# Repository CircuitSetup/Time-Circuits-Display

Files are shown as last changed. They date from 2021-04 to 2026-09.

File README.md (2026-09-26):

# Time Circuits Display

| TCD Front |

This [repository](https://github.com/CircuitSetup/Time-Circuits-Display) holds the most current firmware for CircuitSetup's wonderful [Time Circuits Display](https://circuitsetup.us/product/complete-time-circuits-display-kit/) ("TCD") kit, a reproduction of an iconic part of the Delorean Time Machine.

The kit is available [here](https://circuitsetup.us/product/complete-time-circuits-display-kit/). The metal version is very popular among Delorean owners who convert their vehicle into a Time Machine. A testament to its build quality and accuracy is further the fact that it is used in the **movie-based, official musicals on tour** (2024-2026), and that a sample is part of the experience in the **"OUTATIME" [Escape Room](https://www.universalorlando.com/web/en/us/things-to-do/entertainment/universals-great-movie-escape) in Orlando, Florida**. Namedropping aside, this TCD makes an excellent centerpiece of every movie props collection. It can be used stand-alone or in combination with several [peripherals](#peripherals), both in car and home setups.

[View the instructions for assembling your CircuitSetup TCD Kit](https://github.com/CircuitSetup/Time-Circuits-Display/wiki)

And don't be fooled by the looks, it got brains, too!

| Watch the video (https://youtu.be/1HX0PiZ1YL0) |
|:--:|
| Click to watch the video |

| Watch the video (https://youtu.be/u9oTVXUIOXA) |
|:--:|
| Click to watch the video |

Features include

- Clock-related:
  - Time keeping for years 1-9999, accurately based on Julian and Gregorian [calendars](#calendar-system)
  - Support for time zones and automatic DST (Daylight Saving adjustment)
  - Time synchronization through Internet ([NTP&#10548;](https://en.wikipedia.org/wiki/Network_Time_Protocol)) or [GPS](#gps-receiver)
  - [World Clock mode](#world-clock-mode): Show current time in different time zones on *destination time* and/or *last time departed* displays
  - [Alarm function](#alarm): Daily alarms, with weekday selection as well as snooze and auto-snooze functions
  - [Count-down timer](#count-down-timer): Count down from up to 99 minutes
  - [Yearly/monthly reminder](#yearlymonthly-reminder): Get a yearly or monthly acoustic reminder
  - [Sound on the hour](#additional-custom-sounds)
  - Time can be [spoken out loud](#martys-time-announcement) by "Marty McFly"
- Movie-related:
  - Movie-accurate [Beep](#beep-on-the-second) sound every second (4 modes)
  - Movie-accurate [time travel](#time-travel) function
  - Configuration options to emulate nearly all variations of the TCD shown in the trilogy
  - ["Return from Time Travel"](#time-travel): Return to real present time easily
  - ["Time-cycling"](#time-cycling): Movie-accurate time travel times displayed in *destination time* and *last time departed* displays, and cycled in configurable interval
  - [Exhibition mode](#exhibition-mode): Show a fixed time in *Present Time* display instead of a running clock. Helpful for filming or museums.
- Network capabilities:
  - Advanced network-accessible [Config Portal](#the-config-portal) for setup (http://timecircuits.local)
  - [Wireless communication](#connecting-props-wirelessly-bttf-network-bttfn) with compatible props such as CircuitSetup's [Flux Capacitor](https://circuitsetup.us/product/flux-capacitor-light-sound-kit/) and [SID](https://circuitsetup.us/product/delorean-time-machine-status-indicator-display-sid/), as well as the [Dash Gauges](https://circuitsetup.us/product/delorean-time-machine-dash-gauge-control-board/), [VSR](https://vsr.out-a-ti.me) and modified [Futaba Remote Control](https://circuitsetup.us/product/futaba-remote-stanley-display-wireless-control-kit/), for synchronized Time Travel sequences, replaying movie scenes, mutual remote control, and more. No need for even more wires in your Delorean.
  - [Home Assistant](#home-assistant--mqtt) (MQTT) support for sending and displaying messages, remote controlling and more.
  - Easy [firmware updates](#firmware-installation--firmware-update) over-the-air. No need to send in stuff for firmware updates, it's the 2020s after all.
- [Night mode](#night-mode): Dim or switch off displays on schedule, manually or sensor-controlled. So you won't be blinded during night drives.
- Support for [SD cards](#sd-card) up to 32GB
- Audio output through [line-out](#audio-output) for time travel sound, music and [user-added](#additional-custom-sounds) sound. Connect your TCD to your (car) stereo for high-quality stereo-sound. No more "time traveling" through a 2" speaker. (Requires Control Board 1.4.5 or later)
- [Music player](#the-music-player): Play your mp3 files located on SD card, through your (car) stereo if available. 
- [Keypad-controlled menu](#the-keypad-menu) for adjusting various settings and viewing status through the three displays
- Support for numerous [peripherals](#peripherals):
  - [Fake "power switch"](#fake-power-switch) (eg. a [TFC drive switch](https://tfc.out-a-ti.me))
  - [Speedometer](#speedometer) (eg. CircuitSetup's [speedo](https://circuitsetup.us/product/delorean-time-machine-speedometer-kit) with built-in GPS receiver)
  - [GPS receiver](#gps-receiver) for time synchronization and actual [speed](#gps-for-speed) to be displayed on speedo
  - [Rotary encoders](#rotary-encoder) for manual selection of speed to be displayed on speedo, and/or audio volume
  - External [Time Travel trigger](#external-time-travel-trigger), with optional delay
  - [Temperature/humidity sensor](#room-condition-mode-temperaturehumidity-sensor) for [Room Condition mode](#room-condition-mode-temperaturehumidity-sensor) [display temperature and humidity in *destination time* and *last time departed* displays] and for displaying temperature on speedo while idle
  - Multi-purpose output for signaling/controlling other props [connected by wire](#connecting-props-by-wire) (for example flux lights, third party props)
- &#128007; &#129370; &#129370; &#129370; &#129370; &#129370; &#129370; &#129370; &#129370; &#129370; &#129370; &#129370; &#129370;

>[This repository](https://tcd.out-a%2dti.me) is the upstream source for CircuitSetup's releases. The differences are that both code and documentation [here](https://tcd.out%2da-ti.me) might be ahead in development, and in the sound-packs.

For information on updating the firmware of your TCD, see [here](#firmware-installation--firmware-update).

## Initial Configuration

The first step is to establish access to the TCD's configuration website ("Config Portal") in order to configure your TCD:

- Power up the TCD and wait until it shows a time (which is probably wrong).
- Connect your computer or handheld device to the WiFi network "TCD-AP".
- Navigate your browser to http://timecircuits.local or http://192.168.4.1 to enter the Config Portal.

#### Time zone and Time

The next step is to set the TCD's time zone. If the time zone isn't properly configured, the TCD will show a wrong time and DST (daylight saving) will not be switched on/off correctly.

Click on "Settings" on the Config Portal's main page, and specify your [time zone](#-time-zone). Then click "SAVE"; the TCD will reboot.

Setting actual time:
- If the TCD is going to be connected to a WiFi network with internet access as described below, it will receive time information through NTP (network time protocol). No user interaction is required.
- Otherwise please set your local time through the [keypad menu](#how-to-set-the-real-time-clock-rtc).

#### Sound-pack re-installation (Firmware 3.23 an onwards)

If your factory-fresh TCD came with firmware version 3.23 or later, but no SD card, and you have an SD card at hand, the next step is to re-install the sound-pack. The reason for this is that the sound-pack does not entirely fit into the device's flash memory and parts of it need to be installed on your SD card. Please see [here](#sound-pack-installation) for instructions.

#### WiFi Setup

The TCD knows two ways of WiFi operation: Either it creates its own WiFi network or it connects to a pre-existing WiFi network.

As long as the device is unconfigured, it creates a WiFi network of its own named "TCD-AP". This is called **"Access point mode"** or **"AP-mode"**. In this mode, other WiFi devices - such as other props or a computer - can connect to the TCD, but the TCD can't access the internet (and therefore not synchronize time through NTP). Also, [HA/MQTT](#home-assistant--mqtt) is not possible.

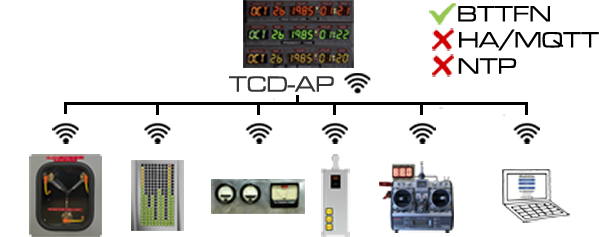
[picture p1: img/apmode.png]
APmode


It is ok to leave the TCD in this mode if there is no WiFi network available.

<details>
<summary>More...</summary>

>Please do not leave computers/handhelds permanently connected to the TCD's AP. These devices might think they are connected to the internet and therefore hammer the TCD with DNS and HTTP requests which might lead to packet loss and disruptions.

>If you want your device to remain in AP-mode, please choose a suitable WiFi channel on the Config Portal's "WiFi Configuration" page. See [here](#-wifi-channel).

</details>

In a typical **home setup**, however, you might want to connect the TCD to your local WiFi network. This allows for for time synchronization (NTP) and [HA/MQTT](#home-assistant--mqtt):

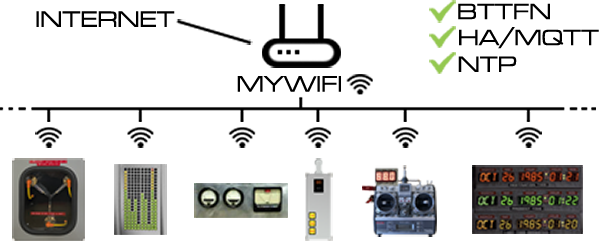
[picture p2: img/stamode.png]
STAmode


To connect your TCD to your WiFi network, navigate to the Config Portal and click on "WiFi Configuration". The bare minimum is to select an WiFi network name (SSID) and a WiFi password.

<details>
<summary>More...</summary>
  
>If there are several APs with identical SSID nearby, the TCD will connect to the first one found which might not be the nearest/strongest. It is therefore recommended to select a specific AP by its BSSID (AP's MAC address). You can either manually find out your AP's BSSID and enter it or have it filled out automatically: Click "Scan for networks", then "Show all". If you click on an AP, its BSSID will be copied into BSSID field in the form below. To see which AP is which, hover over the name to see its BSSID as a tooltip.

>The TCD requests an IP address via DHCP, unless you entered valid data in the fields for static IP addresses (IP, gateway, netmask, DNS). If the device is inaccessible as a result of incorrect static IPs, hold ```ENTER``` while powering it up until the white LED lights up; static IP data will be deleted and the device will return to DHCP.
</details>

After saving the WiFi configuration settings, the TCD reboots and tries to connect to your selected WiFi network. If that fails, it will again start in access point mode.

If your TCD is **mounted in a car**, there is a special Car Mode that allows having a WiFi network configured (for administrative purposes and NTP time synchronization) and switching between AP-Mode and WiFi-connection through keypad commands. See [here](#car-mode) and [here](#car-setup---best-practice). So, despite using your TCD in a car, you can at this point configure a WiFi Connection, eg. to your cell phone's hotspot, and then put the TCD into Car Mode which reboots it into Access-Point mode. 

After completing these steps, your TCD is ready for use; you can also continue configuring it to your personal preferences through the Config Portal.

## The Config Portal

The "Config Portal" is the TCD's configuration website. 

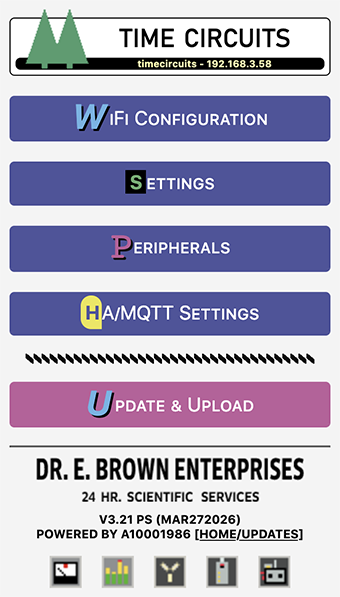
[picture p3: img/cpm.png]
The Config Portal
|  |
|:--:| 
| *The Config Portal's main page* |

It can be accessed as follows:

#### If TCD is in AP mode

- Connect your computer or handheld device to the WiFi network "TCD-AP".
- Navigate your browser to http://timecircuits.local or http://192.168.4.1 to enter the Config Portal.
- (For proper operation, please disconnect your computer or handheld from TCD-AP when you are done with configuring your TCD. These devices can cause high network traffic, resulting in severe performance penalties.)

#### If TCD is connected to WiFi network

- Connect your handheld/computer to the same WiFi network to which the TCD is connected, and
- navigate your browser to http://timecircuits.local

  <details>
  <summary>More...</summary>

  >Accessing the Config Portal through this address requires the operating system of your handheld/computer to support Bonjour/mDNS: Windows 10 version TH2     (1511) [other sources say 1703] and later, Android 13 and later; MacOS and iOS since the dawn of time.

  >If connecting to http://timecircuits.local fails due to a name resolution error, you need to find out the TCD's IP address: Hold ```ENTER``` on the TCD's keypad for 2 seconds, then repeatedly  press 8 until "NETWORK" is shown, then press ```5```. The TCD will show its current IP address. Then, on your handheld or computer, navigate to http://a.b.c.d (a.b.c.d being the IP address as shown on the display) in order to enter the Config Portal.
</details>

In the main menu, click on "Settings" or "Peripherals" to configure your TCD. 

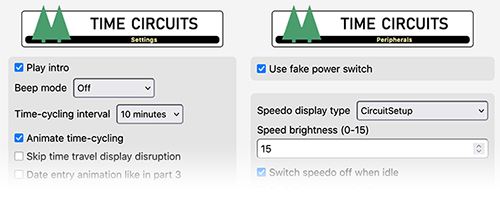
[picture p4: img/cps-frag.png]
| [](img/cp_setup.png) |
|:--:| 
| *Click for full screenshot* |

A full reference of the Config Portal is [here](#appendix-a-the-config-portal).

## Basic Operation

*Present time* is a clock and normally shows actual local present time, as received from the network or set up through the [keypad menu](#how-to-set-the-real-time-clock-rtc).

*Destination time* and *Last time departed* are stale. These, by default, work like in the movie: Upon a time travel, *present time* becomes *last time departed*, and *destination time* becomes *present time*. Or in Doc's words: The red one tells you where you're going. The green one tells you where you are. The yellow one tells you where you were.

The keypad is for programming destination times like in the movies and for controlling the TCD through commands. "Keypad commands" are multi-digit codes to be typed on the digit keys followed by ```ENTER```. ```ENTER``` is the button right above the "Clear" badge.

<details>
<summary>"REPLACE BATTERY" displayed on boot?</summary>
If "REPLACE BATTERY" is shown upon boot, the onboard CR2032 battery is depleted and needs to be replaced. For technical reasons, "REPLACE BATTERY" will also show up the very first time you power-up the TCD *after* changing the battery. You can, of course, disregard that message at that point.
</details>

### Powering down the TCD

The TCD sometimes writes data to either the internal flash memory or the SD card. These write operations should not be interrupted by a power loss.

In general, it is safe to power-down the TCD when it has been idle for 15 seconds or after it has been fake-powered-down. Try to avoid powering down the TCD
- when it is clearly busy (such as when copying or renaming audio files);
- within 15 seconds after changing the display mode (World Clock, Room condition, geolocation, …) or audio volume through a Rotary Encoder, 
- if [**_Make time travel persistent_**](#persistent--non-persistent-time-travels) is checked: in the first few seconds after a timetravel.

### Calendar system

The TCD firmware uses the [Julian Calendar&#10548;](https://en.wikipedia.org/wiki/Julian_calendar) from Jan 1, 1, until Sep 2, 1752, and for later dates the [Gregorian&#10548;](https://en.wikipedia.org/wiki/Gregorian_calendar) one. Sep 2, 1752, was the last day the Julian calendar was used in the ["First" British Empire&#10548;](https://en.wikipedia.org/wiki/British_Empire#%22First%22_British_Empire_(1707%E2%80%931783)) (Great Britain and its colonies, including eastern parts of North America, Canada). Other countries stopped using this calendar system way earlier; most of Europe, including Spain and its colonies worldwide, had switched in 1582 already.

Since the time machine was built in the USA, my guess is Doc would have picked 1752. (One might argue that California was a Spanish colony, but it only became that in 1769.)

So, what does this mean? First off, in the Julian calendar every 4th year is a leap year; in the Gregorian calendar there are some exceptions to this rule. As a result, the two calendars were drifting apart over time, and dates didn't match. As of 2023, the Julian calendar is 13 days ahead.

Secondly, and as a result of this drift, when countries switched from one to the other calendar system, days were skipped. In case of the switch in 1752, Sep 3 until Sep 13 were skipped, so after Sep 2 came Sep 14. For using the TCD this means that dates entered within that skipped period are corrected to Sep 14.

Neither the Gregorian nor the Julian Calendar know a "year 0"; 1AD followed after 1BC. Nevertheless, it is possible to travel to year 0. In good old Hollywood tradition, I won't let facts stand in the way of an authentic movie experience.

### Time-cycling

"Time cycling" is a decorative mode of operation in which the device cycles through a list of pre-programmed *destination* and *last time departed* times. These pre-programmed times match the dates/times of all time-travels that take place in the three movies.

Time-cycling is enabled by setting up a **_Time-cycling Interval_** in the Config Portal or the [keypad menu](#how-to-select-the-time-cycling-interval). The device will then cycle through named list every 5th, 10th, 15th, 30th or 60th minute. The option **_Animate time-cycling_** decides whether the times simply switch or the cycling event looks like someone entered a new destination date.

Triggering a time-travel pauses time-cycling for 30 minutes.

### World Clock mode

In World Clock (WC) mode, the red and yellow displays show not some stale times, but current time in other time zones. These time zones can be configured in Config Portal. At least one time zone (for either the red or yellow display) must be configured in order to use WC mode. Optionally, also names for cities/locations for these time zones can be entered in the Config Portal and shown [instead of the date or alternately](#world-clock-mode-1). Names can only contain letters a-z, numbers 0-9, space and minus. 

| Watch the video (https://youtu.be/Uk1W7D6Ab9Y) |
|:--:|
| Click to watch the video |

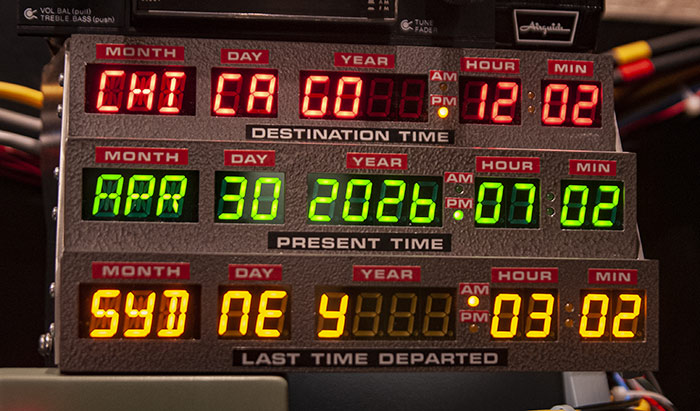
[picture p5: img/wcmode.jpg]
WC mode
|  |
|:--:|
| *World Clock mode* |

WC mode is toggled through keypad command ```112```. If an SD card is present, WC mode is persistent across reboots. To return to the default display mode, enter keypad command ```110```.

For logical reasons, WC mode will be automatically disabled in some situations:

- After entering a destination time. WC mode is disabled at this point, because your new *Destination Time* would be overwritten otherwise.
- Time travel. The time travel sequence runs like in non-WC mode: If a time travel is triggered while WC mode is enabled (and no new destination time was entered before), the currently shown *Destination Time* will be the travel target, and the *Last Time Departed* display will show your formerly current time. However: Both *Destination Time* as well as *Last Time Departed* become stale after the time travel as per the nature of the sequence.

#### WC/RC hybrid mode

In this mode, which is a hybrid of [Room Condition (RC) mode](#room-condition-mode-temperaturehumidity-sensor) and WC mode, one display is used for room conditions, the other for world time. If there is a time zone configured for the red display, room conditions will be shown in the yellow display. If there is no time zone for the red display, it's used for room conditions, and the yellow display will show world time.

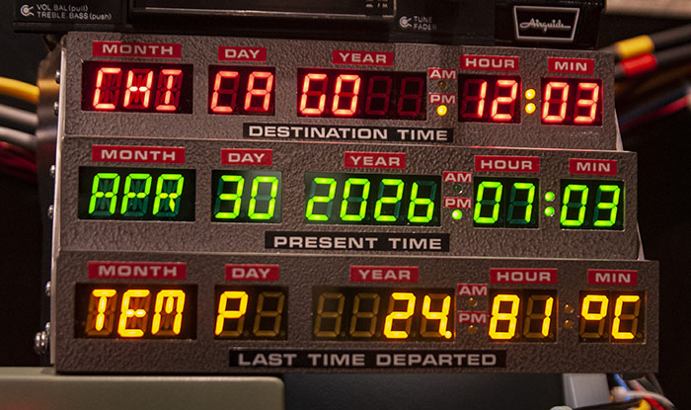
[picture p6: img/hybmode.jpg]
WC/RC hybrid
|  |
|:--:|
| *WC/RC hybrid mode* |

To toggle WC/RC hybrid mode, enter keypad command ```113```. To return to the default display mode, enter keypad command ```110```.

### Minimal mode

In "Minimal" mode, the *Present Time* display shows the weekday instead of the year, the other displays are switched off. To enable this mode, enter keypad command ```117```. If an SD card is present, Minimal mode is persistent across reboots. To return to the default display mode, enter keypad command ```110```.

Minimal mode is disabled automatically under the same conditions as World Clock mode.

### Exhibition mode

In this mode, the TCD shows a fixed, pre-programmed time in the *Present Time* display. Also after a time travel, the *Present Time* display will stay fixed at the time you travelled to. This is useful for exhibitions or for filming.

To enable this mode, enter keypad command ```999```. The default fixed time will be displayed. To change this time, type ```99mmddyyyyhhMM``` followed by ```ENTER```. Keypad command ```999``` takes you back to normal mode.

Exhibition mode is persistent; the pre-programmed time will be stored and retrieved after a reboot/power-down.

Not strictly part of Exhibition mode, but related: If you want your TCD to display specific times in the *Destination Time* and/or *Last Time Departed* displays, you can program those times through the [keypad menu](#how-to-program-datestimes-for-the-destination-and-last-time-departed-displays). To quickly reset the displays to your pre-programmed times (such as after a time travel, during which they were replaced by other dates/times), enter keypad command ```998```.

### Audio Output

Control boards 1.4.5 and later have two ways of audio output:
- built-in speaker or
- line-out (at line-level, for connecting the TCD to a stereo's line-in)

By default, all audio is played over the speaker.

Keypad command ```351``` enables playback over line-out for music, time travel sound, user-added sound as well as some other sound effects.

All sounds, which are supposed to be emitted by the TCD itself, are always played over the built-in speaker. Note that the TCD's volume control (knob, software-selected level, rotary encoder) only has impact on the built-in speaker.

Keypad command ```350``` disables line-out output. 

The chosen line-out setting is persistent over reboots.

### Common usage scenarios

####  &#9193; I want my TCD to work like in the movie

In this case, head to the Config Portal and set the **_Time Cycling Interval_** to OFF.

>Note that *actual* time travel is not supported.

#### 	&#9193; I want my TCD to always show my favorite *Destination* and *last time departed* times

In this case,
- head to the Config Portal and set the **_Time Cycling Interval_** to OFF, and
- then, using the [keypad menu](#how-to-program-datestimes-for-the-destination-and-last-time-departed-displays), program your favorite *Destination* and *Last time departed* times.

Time-traveling will naturally lead to the displays showing other times. To bring your favorite times back without rebooting, enter keypad command ```998```.

#### 	&#9193; I want my TCD to show/cycle movie times

In this case, head to the Config Portal and set the **_Time Cycling Interval_** to the desired interval.

Time-traveling will interrupt the cycling of movie times for 30 minutes.

### Keypad reference

In the following, "pressing" means briefly pressing a key, "holding" means keeping the key pressed for 2 seconds or longer.

```mm``` = month (01-12, 2 digits); ```dd``` = day (01-31, 2 digits); ```yyyy``` = year (4 digits); ```hh``` = hour (00-23, 2 digits); ```MM``` = minute (00-59, 2 digits)

<table id="commandref">
    <tr>
     <td align="center" colspan="2">Destination time programming<br>(&#9166; = <code>ENTER</code> key)</td>
    </tr>
    <tr>
     <td align="center"><code>mmddyyyyhhMM</code>&#9166;</td>
     <td align="center">Set complete date/time for <a href="#time-travel">Time Travel</a></td>
    </tr>
    <tr>
     <td align="center"><code>mmddyyyy</code>&#9166;</td>
     <td align="center">Set date for <a href="#time-travel">Time Travel</a></td>
    </tr>
    <tr>
     <td align="center"><code>hhMM</code>&#9166;</td>
     <td align="center">Set time for <a href="#time-travel">Time Travel</a></td>
    </tr>
</table>

<table>
    <tr>
     <td align="center" colspan="2">Keypad commands<br>(&#9166; = <code>ENTER</code> key)</td>
    </tr>
   <tr>
     <td align="left">Reset display mode (disable 111-117)</a></td>
     <td align="left"><code>110</code>&#9166;</td>
    </tr>
    <tr>
     <td align="left">Toggle <a href="#room-condition-mode-temperaturehumidity-sensor">Room Condition mode</a></td>
     <td align="left"><code>111</code>&#9166;</td>
    </tr>
    <tr>
     <td align="left">Toggle <a href="#world-clock-mode">World Clock mode</a></td>
     <td align="left"><code>112</code>&#9166;</td>
    </tr>
    <tr>
     <td align="left">Toggle <a href="#wcrc-hybrid-mode">WC/RC hybrid mode</a></td>
     <td align="left"><code>113</code>&#9166;</td>
    </tr>
    <tr>
     <td align="left">Toggle <a href="#geolocation-mode">geolocation mode</a> (DD/DMS/DMD)</td>
     <td align="left"><code>114</code>&#9166;/<code>115</code>&#9166;/<code>116</code>&#9166;</td>
    </tr>
    <tr>
     <td align="left">Toggle <a href="#minimal-mode">Minimal</a> mode</td>
     <td align="left"><code>117</code>&#9166;</td>
    </tr>
    <tr>
     <td align="left">Display weekday of currently displayed <i>present time</i> date</td>
     <td align="left"><code>39</code>&#9166;</td>
    </tr>
  <tr>
     <td align="left">Disable <a href="#beep-on-the-second">beep</a> sound</td>
     <td align="left"><code>20</code>&#9166;</td>
   </tr>
   <tr>
     <td align="left">Enable <a href="#beep-on-the-second">beep</a> sound</td>
     <td align="left"><code>21</code>&#9166;</td>
   </tr>
   <tr>
     <td align="left">Enable <a href="#beep-on-the-second">beep</a> sound (30 seconds)</td>
     <td align="left"><code>22</code>&#9166;</td>
   </tr>
   <tr>
     <td align="left">Enable <a href="#beep-on-the-second">beep</a> sound (60 seconds)</td>
     <td align="left"><code>23</code>&#9166;</td>
   </tr>
    <tr>
     <td align="left">Select relative beep volume level</td>
     <td align="left"><code>30</code> - <code>33</code>&#9166;</td>
    </tr>
  <tr>
     <td align="left">Select audio volume level</td>
     <td align="left"><code>300</code> - <code>320</code>&#9166;</td>
    </tr>
    <tr>
     <td align="left">Disable/enable <a href="#audio-output">line-out audio</a> for music and time travel sounds</td>
     <td align="left"><code>350</code>&#9166; / <code>351</code>&#9166;</td>
    </tr>
    <tr>
     <td align="left">Enable built-in volume knob</td>
     <td align="left"><code>399</code>&#9166;</td>
    </tr>
    <tr>
     <td align="left">Show current <a href="#alarm">alarm</a> time/weekday</td>
     <td align="left"><code>11</code>&#9166;</td>
    </tr>
    <tr>
     <td align="left">Set <a href="#alarm">alarm</a> to hh:MM</td>
     <td align="left"><code>11hhMM</code>&#9166;</td>
    </tr>
    <tr>
     <td align="left">Stop <a href="#alarm">alarm</a>, cancel Snooze</td>
     <td align="left"><code>12</code>&#9166;</td>
    </tr>
    <tr>
     <td align="left"><a href="#count-down-timer">Timer</a>: Show remaining time</td>
     <td align="left"><code>44</code>&#9166;</td>
    </tr>
    <tr>
     <td align="left"><a href="#count-down-timer">Timer</a>: Set timer to MM minutes</td>
     <td align="left"><code>44MM</code>&#9166;</td>
    </tr>
    <tr>
     <td align="left"><a href="#count-down-timer">Timer</a>: Delete timer</td>
     <td align="left"><code>440</code>&#9166;</td>
    </tr>
    <tr>
     <td align="left"><a href="#yearlymonthly-reminder">Reminder</a>: Display reminder</td>
     <td align="left"><code>77</code>&#9166;</td>
    </tr>
    <tr>
     <td align="left"><a href="#yearlymonthly-reminder">Reminder</a>: Display time until reminder</td>
     <td align="left"><code>777</code>&#9166;</td>
    </tr>
    <tr>
     <td align="left"><a href="#yearlymonthly-reminder">Reminder</a>: Program reminder</td>
     <td align="left"><code>77mmdd</code>&#9166;</td>
    </tr>
    <tr>
     <td align="left"><a href="#yearlymonthly-reminder">Reminder</a>: Program reminder</td>
     <td align="left"><code>77mmddhhMM</code>&#9166;</td>
    </tr>
    <tr>
     <td align="left"><a href="#yearlymonthly-reminder">Reminder</a>: Delete reminder</td>
     <td align="left"><code>770</code>&#9166;</td>
    </tr>
    <tr>
     <td align="left"><a href="#the-music-player">Music Player</a>: Show currently played track</td>
     <td align="left"><code>55</code>&#9166;</td>
    </tr>
    <tr>
     <td align="left"><a href="#the-music-player">Music Player</a>: Shuffle off</td>
     <td align="left"><code>222</code>&#9166;</td>
    </tr>
    <tr>
     <td align="left"><a href="#the-music-player">Music Player</a>: Shuffle on</td>
     <td align="left"><code>555</code>&#9166;</td>
    </tr> 
    <tr>
     <td align="left"><a href="#the-music-player">Music Player</a>: Go to track 0</td>
     <td align="left"><code>888</code>&#9166;</td>
    </tr>
    <tr>
     <td align="left"><a href="#the-music-player">Music Player</a>: Go to track xxx</td>
     <td align="left"><code>888xxx</code>&#9166;</td>
    </tr>
    <tr>
     <td align="left">Play "<a href="#additional-custom-sounds">keyX.mp3</a>" (X=1-9)</td>
     <td align="left"><code>501</code> - <code>509</code>&#9166;</td>
    </tr>
    <tr>
     <td align="left">Send pre-configured <a href="#send-messages">HA/MQTT</a> messages</td>
     <td align="left"><code>600</code> - <code>609</code>&#9166;</td>
    </tr>
    <tr>
     <td align="left">Set <a href="#connecting-props-by-wire">TT OUT</a> LOW / HIGH</td>
     <td align="left"><code>900</code>&#9166; / <code>901</code>&#9166;</td>
    </tr>
    <tr>
     <td align="left">Disable / enable <a href="#car-mode">car mode</a>(*)</td>
     <td align="left"><code>990</code>&#9166; / <code>991</code>&#9166;</td>
    </tr>
    <tr>
     <td align="left">Forbid / allow TCD to be <a href="#futaba-remote-control">remote controlled</a>(*)</td>
     <td align="left"><code>992</code>&#9166; / <code>993</code>&#9166;</td>
    </tr>
    <tr>
     <td align="left">Forbid / allow TCD keypad to be <a href="#remote-controlling-the-tcds-keypad">remote controlled</a>(*)</td>
     <td align="left"><code>994</code>&#9166; / <code>995</code>&#9166;</td>
    </tr>
    <tr>
     <td align="left">Release HA from <a href="#fake-power-control-through-ha">Fake-Power control</a>(*)</td>
     <td align="left"><code>996</code>&#9166;</td>
    </tr>
    <tr>
     <td align="left">Restore user destination/last time dep. times</td>
     <td align="left"><code>998</code>&#9166;</td>
    </tr>
    <tr>
     <td align="left">Enable / disable <a href="#exhibition-mode">Exhibition mode</a></td>
     <td align="left"><code>999</code>&#9166;</td>
    </tr>
    <tr>
     <td align="left">Program time for <a href="#exhibition-mode">Exhibition mode</a></td>
     <td align="left"><code>99mmddyyyyhhMM</code>&#9166;</td>
    </tr>
    <tr>
     <td align="left">Program and save time for <a href="#how-to-program-datestimes-for-the-destination-and-last-time-departed-displays"><i>Destination Time</i> display</a></td>
     <td align="left"><code>91mmddyyyyhhMM</code>&#9166;</td>
    </tr>
    <tr>
     <td align="left">Program and save time for <a href="#how-to-program-datestimes-for-the-destination-and-last-time-departed-displays"><i>Last Time Departed</i> display</a></td>
     <td align="left"><code>92mmddyyyyhhMM</code>&#9166;</td>
    </tr>    
    <tr>
     <td align="left">Toggle firmware update message at power-up</td>
     <td align="left"><code>53281</code>&#9166;</td>
    </tr>
    <tr>
     <td align="left">Reboot the device(*)</td>
     <td align="left"><code>64738</code>&#9166;</td>
    </tr>
</table>

(*) Not supported through HA/MQTT [_INJECT_](#the-inject_x-command) command

<table>
    <tr>
     <td align="center" colspan="3">Holding keys for 2 seconds</td>
    </tr>
    <tr>
     <td align="center"><code>1</code><br>Toggle <a href="#alarm">Alarm</a> on/off</td>
     <td align="center"><code>2</code><br><a href="#the-music-player">Music Player</a>: Previous track</td>
     <td align="center"><code>3</code><br><a href="#additional-custom-sounds">Play "key3.mp3"</a></td>
    </tr>
    <tr>
     <td align="center"><code>4</code><br>Toggle <a href="#night-mode">Night mode</a> on/off</td>
     <td align="center"><code>5</code><br><a href="#the-music-player">Music Player</a>: Play/Stop</a></td>
     <td align="center"><code>6</code><br><a href="#additional-custom-sounds">Play "key6.mp3"</a></td>
    </tr>
    <tr>
     <td align="center"><code>7</code><br><a href="#wifi-power-saving-features">Re-enable WiFi</a></td>
     <td align="center"><code>8</code><br><a href="#the-music-player">Music Player</a>: Next track</td>
     <td align="center"><code>9</code><br><a href="#time-travel">Return from Time Travel</a></td>
    </tr>
    <tr>
     <td align="center"></td>
     <td align="center"><code>0</code><br><a href="#time-travel">Time Travel</a></td>
     <td align="center"></td>
    </tr>
</table>

[Here](CheatSheet.pdf) is a cheat sheet for printing or screen-use.

#### Remote controlling the TCD's keypad

The TCD's keypad can be remote controlled through either [Flux Capacitor](https://circuitsetup.us/product/flux-capacitor-light-sound-kit/) or [SID](https://circuitsetup.us/product/delorean-time-machine-status-indicator-display-sid/), using their respective IR remote control. In order to permit keypad remote controlling, enter keypad command ```995```. To prohibit remote controlling, enter keypad command ```994```. No further configuration is required on the TCD's side. Please see the [Flux Capacitor](https://github.com/CircuitSetup/Flux-Capacitor) and/or [SID](https://github.com/CircuitSetup/SID) documentation for details. 

## Time travel

To travel through time, hold ```0``` for 2 seconds (or use an [external trigger](#external-time-travel-trigger)). The *destination time*, as shown in the red display, will be your new *present time*, the old *present time* will be the *last time departed*. The new *present time* will continue to run like a normal clock.

Before triggering the time travel, you can also first quickly set a new destination time by entering a date on the keypad: ```mmddyyyy```, ```mmddyyyyhhMM``` or ```hhMM```, then press ```ENTER```. While typing, there is no visual feedback, but the date is then shown on the *destination time* display after pressing ```ENTER```.

To travel back to actual present time, hold ```9``` for 2 seconds.

### Persistent / Non-persistent time travels

On the Config Portal's "Settings" page, there is an option item named **_Make time travel persistent_**. The default is off. 

>For using this feature, an SD card is required and the option **_Save secondary settings on SD_** must be checked as well.

If time travels are persistent
- any *destination time* entered (by typing ```mmddyyyyhhMM```/```mmddyyyy```/```hhMM```) is immediately saved and retrieved upon power-up/reboot.
- *last time departed* is saved when changed during a time travel and retrieved upon power-up/reboot.
- *present time*, be it actual present time or "fake" after time traveling, will continue to run while the device is not powered, as long as its battery lasts, and displayed on power-up/reboot.

If time travels are non-persistent
- *destination time* is not saved,
- a *last time departed* is not saved,
- *present time* is always reset to actual present time upon power-up/reboot.

If you want your device to display exactly the same after a power loss, choose persistent (and disable [Time-cycling](#time-cycling)). 

>[Time-cycling](#time-cycling), if enabled, will force the device to cycle through the list of pre-programmed times, regardless of your time travel persistence setting. Time-Cycling does, however, not overwrite saved times, only displayed times.

## Beep on the second

In the movies, the Time Circuits emit a "beep" sound every second, which is only really audible in the scene in which Doc explains to Marty how the time machine works. The firmware supports that beep, too.

The beep can be permanently disabled, permanently enabled, or enabled for 30 or 60 seconds
- after a destination time is entered (and ```ENTER``` is pressed),
- upon triggering a time travel,
- after switching on the TCD (real power-up or fake power-up),
- after changing "speed" using a [Rotary Encoder](#rotary-encoder).

The different modes are selected through keypad commands ```20``` (disabled), ```21``` (enabled), ```22``` (enabled for 30 secs) or ```23``` (enabled for 60 secs).

The beep volume level can be selected relative to general volume, in four steps (keypad commands ```30```-```33```). _Relative to general volume_ means that the beep volume is a percentage of general volume, and as a result, the lower your general volume, the less of a difference will be between the relative beep levels.

For technical reasons, the beep is suppressed whenever other sounds are played-back.

## Marty's time announcement

As of version 3.23, the TCD, or rather "Marty McFly", will tell you the time out loud on pressing ```ENTER``` (without a command).

Furthermore, since version 3.27, a default "sound on the hour" can be enabled in the Config Portal, which consists of the Clock Tower Bell and a time announcement from "Marty McFly".

## Night mode

In night-mode, by default, the *destination time* and *last time departed* displays are switched off, the *present time* display is dimmed to a minimum, and the volume of sound playback is reduced (except the alarm). Apart from considerably increasing the displays' lifetime, night-mode reduces the power consumption of the device from around 4.5W to around 2.5W.

You can configure the displays' behavior in night-mode in the Config Portal: They can individually be dimmed or switched off in night-mode.

#### Manually switching to night-mode

To toggle night-mode on/off manually, hold ```4```.

#### Scheduled night-mode

In the Config Portal, a schedule for night-mode can be programmed. You can choose from various time-schedule presets or set up a daily schedule with your preferred start and end hours.

The presets are for typical home, office and shop setups, and they assume the TCD to be in use (ie night-mode off) at the following times:
- Home: Mon-Thu 5pm-11pm, Fri 1pm-1am, Sat 9am-1am, Sun 9am-11pm
- Office (1): Mon-Fri 9am-5pm
- Office (2): Mon-Thu 7am-5pm, Fri 7am-2pm
- Shop: Mon-Wed 8am-8pm, Thu-Fri 8am-9pm, Sat 8am-5pm
- Night Owl (aka "Mancave"): Sun-Thu 8pm-1am, Fri/Sat 8pm-4am

The *daily* schedule works by entering start and end in the text fields below. The TCD will go into night-mode at the defined start hour (xx:00), and return to normal operation at the end hour (yy:00). 

Night mode schedules are always based on actual local present time.

#### Sensor-controlled night-mode

You can also connect a light sensor to your TCD for night-mode switching: When the sensor reports a lux level below or equal the threshold set in the Config Portal, the TCD will go into night-mode.

If both a schedule and the light sensor are enabled, the sensor will overrule the schedule only in non-night-mode hours; ie it will never switch off night-mode when night-mode is active according to the schedule.

Switching on/off night-mode manually deactivates any schedule and the light sensor for 30 minutes. Afterwards, a programmed schedule and/or the light sensor will overrule the manual setting.

To use a light sensor, check the option _Use light sensor_ in the Config Portal. You can observe the measured lux level through the [keypad menu](#how-to-view-sensor-info) to find out about the right lux threshold for your environment.

For information on supported sensor models/types and configuration, see [here](AddOns.md#light-sensor).

## Alarm

The alarm function works like any common alarm clock: An alarm sounds at a pre-programmed time.

The alarm can be programmed through the [keypad menu](#how-to-set-up-the-alarm) or quickly through keypad command ```11hhMM``` (hh=hour, 00-23; MM=minute, 00-59). Weekday selection must be done through the [keypad menu](#how-to-set-up-the-alarm).

Holding ```1``` enables and disables the alarm; the state is shown by the dot in the present time's minute field. Keypad command ```11``` shows the currently programmed alarm time and the weekdays.

As regards the alarm event itself, the alarm function knows two modes of operation: Legacy and Extended.

Legacy means a simple one-time alarm sound at the programmed time. The default alarm plays for 5 seconds; if [substituted](#sound-substitution), the provided file is played once until its end.

#### Extended Alarm 

In extended mode, the alarm sounds for two minutes, and can be stopped by pressing or holding ```ENTER``` while the alarm sound plays.

If Snooze is enabled in the Config Portal, 
- (briefly) pressing ```ENTER``` while the alarm sounds starts Snooze: The alarm will be silenced and repeat after the configured "Snooze Time".
- hold ```ENTER``` for 2 seconds while the alarm sounds to stop the alarm.

If Auto-Snooze is enabled, and the user does not react to the alarm with the ```ENTER``` button, the alarm will be silenced after two minutes and automatically repeat after the configured "Snooze Time".

While on snooze, the _Present time_'s minute's dot blinks and the alarm can be canceled by keypad command ```12```.

Alarms can also be stopped or put into snooze through [Home Assistant](#home-assistant--mqtt) (```ALARM_STOP```, ```ALARM_SNOOZE```).

A [substitution](#sound-substitution) alarm sound file will be played once. If it is considerably shorter than two minutes, it can be "looped". However, it is stopped after two minutes.

### Other means

An alarm can also be signalled through the [TT-OUT pin](-signals-alarm) to third party props, as well as wirelessly through [BTTFN](#connecting-props-wirelessly-bttf-network-bttfn) and [Home Assistant](#home-assistant--mqtt). Only the original alarm is transmitted, not repeated alarms resulting from Snooze.

## Count-down timer

The firmware features a simple count-down timer. This timer can count down from max 99 minutes and plays a sound upon expiration.

- To set the timer to MM minutes, type ```44MM``` and press ```ENTER```. A single-digit number of minutes must be preceded by 0.
- To cancel a running timer, enter keypad command ```440```.
- The check the remaining time, enter keypad command ```44```.

## Yearly/monthly reminder

A reminder is yearly or monthly alarm.

To program a yearly reminder, enter ```77mmddhhMM``` and press ```ENTER```. For example: ```7705150900``` sets the reminder to May 15, 9am. Now a reminder sound will play every year on May 15 at 9am.

To program a monthly reminder, enter ```7700ddhhMM``` and press ```ENTER```. For example: ```7700152300``` sets the reminder to the 15th of each month, at 11pm.

You can also leave out the hhMM part; in that case the time remains unchanged from a previous setting, unless both hour and minute were 0 (zero), in which case the reminder time is set to 9am.

_All fields consist of two digits, and hours are entered in 24-hour notation._

Keypad command ```77``` displays the programmed reminder, ```770``` deletes it, and ```777``` displays the days/hours/minutes until the next reminder.

At the time the reminder is due, the TCD plays a sound. If a file named "reminder.mp3" is on your SD card, this will be played instead of the default sound.

## SD card

>Only SD/SDHC/SDXC cards up to 32GB are supported. Card needs to be FAT32-formatted (not exFAT). Transcend, Sandisk Ultra (as of firmware version 3.25) and Industrial, Verbatim Premium and Samsung Pro Endurance SDHC cards usually work fine. Some SD cards might not be recognized due to off-specs initialization quirks. SDUC cards are not supported.

The SD card, apart from being required for [installing](#sound-pack-installation) and partly hosting the sound-pack, can be used for substituting built-in sound effects, some additional custom sound effects, and for music played back by the [Music player](#the-music-player). Also, it is _strongly recommended_ to store [secondary settings](#-save-secondary-settings-on-sd) on the SD card to minimize [Flash Wear](#flash-wear).

The SD card must be inserted before powering up the TCD. It is not recognized if inserted while the TCD is running. Furthermore, do not remove the SD card while the TCD is powered.

### Sound substitution

The TCD's built-in sound effects can be substituted by your own sound files stored on the SD card. These files will be played back directly from the SD card during operation, so the SD card has to remain in the slot.

Your replacements need to be put in the root (top-most) directory of the SD card, be in mp3 format (128kbps max) and named as follows:
- "alarm.mp3": Played when the alarm sounds.
- "alarmon.mp3": Played when enabling the alarm,
- "alarmoff.mp3": Played when disabling the alarm,
- "nmon.mp3": Played when manually enabling night mode,
- "nmoff.mp3": Played when manually disabling night mode,
- "reminder.mp3": Played when the reminder is due.
- "timer.mp3": Played when the count-down timer expires.
- "ping.mp3": Played when re-connecting/re-enabling WiFi by holding ```7``` on the keypad.
- "remoteon.mp3" / "remoteoff.mp3": Those are played back if a [Futaba remote control](#futaba-remote-control) takes over speed-control or relinquishes it, respectively. Those sounds are played through [line-out](#audio-output), if enabled.

The following sounds are time-sync'd to display action. If you decide to substitute these with your own, be prepared to lose synchronicity:
- "enter.mp3": Played when a date was entered and ```ENTER``` was pressed.
- "baddate.mp3": Played when a bad (too short or too long) date was entered and ```ENTER``` was pressed.
- "intro.mp3": Played during the power-up intro.
- "travelstart.mp3": Played when a time travel starts (including "acceleration").
- "travelstart2.mp3": Played when a time travel starts (without "acceleration").
- "timetravel.mp3": Played when re-entry of a time travel takes place.
- "shutdown.mp3": Played when the device is fake "powered down".
- "startup.mp3": Played when the TCD is starting up.

### Additional Custom Sounds

The firmware supports some additional, user-provided sound effects, which it will load from the SD card. If the respective file is present, it will be used. If that file is absent, no sound will be played.

- "ttaccel.mp3": Will be played immediately upon triggering a time travel when a speedo is connected, during the acceleration phase (ie while the speedo counts up to 88). This sound is then interrupted by the usual time travel sound. You can use, for instance, the sound of a car accelerating for this. This sound is played through [line-out](#audio-output), if enabled.
- "ttcancel.mp3": Will be played when a time travel acceleration phase is canceled by hitting the brake on the [Remote](#futaba-remote-control). This sound is played through [line-out](#audio-output), if enabled.
- "hour.mp3": Will be played every hour, on the hour. If this file is present, it will be played [instead of the default](#-play-default-sound-on-the-hour). This feature is disabled in night mode.
- "hour-xx.mp3", xx being 00 through 23: Sounds-on-the-hour for specific hours that will be played instead of "hour.mp3". If a sound for a specific hour is not present, "hour.mp3" will be played, if that one exists, otherwise the default (if enabled in the Config Portal). This feature is disabled in night mode.
- "key1.mp3" - "key9.mp3": Will be played on a ```50x``` keypad command (x=1-9); additionally, "key3.mp3"/"key6.mp3" will be played when holding the ```3```/```6``` key for 2 seconds. Those sounds are played through [line-out](#audio-output), if enabled.
- "ha-alert.mp3"/"ha-alart-p.mp3"/"ha-alart-l.mp3": Will be played when a [HA/MQTT message](#display-messages) is received.

Those files are not provided here. You can use any mp3, with a bitrate of 128kpbs or less. Examples are in the install/alt_sound folder.

### Installing Custom & Replacement Audio Files

Replacements and custom sounds can either be uploaded through the Config Portal or copied to the SD card’s root folder using a computer.

Uploading through the Config Portal works exactly like [installing the sound-pack](#sound-pack-installation); on the main menu, click "Update & Upload". Afterwards choose one or more mp3 files to upload using the bottom file selector, and click "Upload". The firmware will store the uploaded mp3 files on the SD card.

In order to delete a file from the SD card, upload a file whose name is prefixed with "delete-". For example: To delete "ttaccel.mp3" from the SD card, upload a file named "delete-ttaccel.mp3"; the file's contents does not matter, so it's easiest to use a newly created empty file. The firmware detects the "delete-" part and, instead of storing the uploaded file, it throws it away and deletes "ttaccel.mp3" from the SD card.

For technical reasons, the TCD must reboot after mp3 files are uploaded in this way.

The maximum bitrate for mp3 files is 128kbps. 

The uploaded files are stored to the root folder of the SD card, so this way of uploading cannot be used to upload music files for the Music Player. 

## The Music Player

The firmware contains a simple music player to play mp3 files located on the SD card. 

> [!NOTE]
> The maximum mp3 bitrate is __128kpbs__. The free [Adapter&#10548;](https://macroplant.com/adapter/audio-converter) tool can re-encode your mp3 files in batches.

To be recognized, your mp3 files need to be organized in music folders named *music0* through *music9*. The folder number is 0 by default, i.e. the player starts searching for music in folder *music0*. This folder number can be changed in the [keypad menu](#how-to-select-the-music-folder-number).

The names of the audio files must only consist of three-digit numbers, starting at 000.mp3, in consecutive order. No numbers should be left out. Each folder can hold up to 1000 files (000.mp3-999.mp3). 

Since manually renaming mp3 files is somewhat cumbersome, the firmware can do this for you: Just copy your files with their original filenames to a music folder of your choice; when selecting that folder, the files will be sorted alphabetically and renamed according to the 3-digit name scheme. (If you want your tracks in a specific order, you must rename them, for instance by inserting a letter or number at the start.) The renaming process can take a while (11 minutes for 1000 files in bad cases). Mac users are advised to delete the ._ files from the SD before putting it back into the TCD as this speeds up the process. While the renaming is in progress, the TCD's display shows the number of files yet to be processed.

To add files to a music folder later, just copy them to the music folder, and delete the cache file "musicXc" (X being the folder number) located in the top-most folder. That way that the firmware knows that something has changed and will re-examine the folder. 

To start and stop music playback, hold ```5```. Holding ```2``` jumps to the previous track, holding ```8``` to the next one.

By default, the tracks are played in order, starting at 000.mp3, followed by 001.mp3 and so on. By entering keypad command ```555``` you can switch to shuffle mode, in which the tracks are played in random order. Keypad command ```222``` switches back to consecutive mode. The Shuffle mode state is saved and persistent across reboots.

Keypad command ```888``` re-starts the player at track 000, and ```888xxx``` (xxx = three-digit number) jumps to track #xxx.

See [here](#keypad-reference) for a list of controls of the music player.

While the music player is playing music, most sound effects are disabled/muted, such as keypad sounds, sound-on-the-hour, sounds for switching on/off the alarm and night-mode. Initiating a time travel stops the music player, as does activating the keypad menu. The alarm, the reminder and the count-down timer will sound as usual and stop the music player.

## The keypad menu
 
The keypad menu is an additional way to configure your TCD; it only involves the three displays and the keypad. 

The menu is invoked by holding the ```ENTER``` button for 2 seconds.

> [!NOTE]
> If the keypad menu is active at a time when the alarm, the reminder or sound-on-the-hour are due, those events will be missed. In case of the count-down timer, the expiration sound will be played after leaving the keypad menu, hence not on time.

Menu navigation uses
- ```2``` for "up" or "+",
- ```8``` for "down" or "-",
- ```5``` or ```ENTER``` for select, and
- ```9``` for cancel/quit.

Data entry, such as for dates and times, is done through the keypad's number keys and works as follows: Whenever a data entry is requested, the field for that data is lit (while the rest of the display is dark) and a pre-set value is shown. If you want to keep that pre-set, press ```ENTER``` to proceed to next field. Otherwise press a digit on the keypad; the pre-set is then overwritten by the value entered. 2 digits can be entered (4 for years). After entering a value, press ```ENTER``` to proceed. A month needs to be entered numerically (01-12), and hours need to be entered in 24-hour notation (00-23), regardless of 12-hour or 24-hour mode as per the Config Portal setting.

After invoking the keypad menu, the first step is to choose a menu item. The available items are  
- set the alarm ("ALARM"),
- set the audio volume (VOLUME),
- set the Music Player folder number ("MUSIC FOLDER NUMBER")
- select the Time-cycling Interval ("TIME CYCLING"),
- select the brightness for the three displays ("BRIGHTNESS"),
- show network information ("NETWORK"),
- set the internal Real Time Clock (RTC) ("SET CLOCK"),
- enter dates/times for the *Destination* and *Last Time Departed* displays ("PROGRAM DATE"),
- show light/temperature/humidity sensor info (if such a sensor is connected) ("SENSORS"),
- show when time was last sync'd with NTP or GPS ("TIME SYNC"),
- see a list of [BTTFN-Clients](#connecting-props-wirelessly-bttf-network-bttfn) currently connected ("BTTFN CLIENTS").
 
Pressing ```ENTER``` or ```2```/```8``` cycles through the list, holding ```ENTER``` or pressing ```5``` selects an item. ```9``` quits the menu.
 
#### How to set up the [alarm](#alarm):

- Hold ```ENTER``` to invoke main menu
- (Currently, the alarm is the first menu item; otherwise press ```2```/```8``` until "ALARM" is shown)
- Press ```5``` or ```ENTER```
- Press ```2```/```8``` to toggle the alarm on and off, press ```5``` or ```ENTER``` to proceed
- Then enter the hour and minutes. This works as described above under "Data entry".
- Choose the weekday(s) by pressing ```2```/```8``` to cycle through options
- Press ```5``` or ```ENTER``` to select
- If you chose "USER DAYS", press keys ```1``` through ```7``` to toggle each day.
- Press ```ENTER``` to proceed to save and quit the menu. "SAVING" is displayed briefly.

Pressing ```9``` at any point - except when entering hour and minutes - cancels and quits the menu.

When the alarm is set and enabled, the dot in the present time's minute field will light up. 

Under normal operation (ie outside of the menu), holding ```1``` toggles the alarm on/off.

The alarm time can also quickly be set by typing ```11hhMM``` (eg. ```110645``` for 6:45am, or ```112300``` for 11:00pm) and pressing ```ENTER```, just like when setting a time travel destination time. (The weekday selection has still to be done via the keypad menu.) Keypad command ```11``` shows the currently set time and weekday selection briefly.

The alarm is recurring, i.e. it rings daily at the programmed time, unless disabled. 

The alarm time is, by default, based on your actual local time, not the time displayed (eg after a time travel). It can, however, be configured to be based on the time displayed, in the Config Portal.

*Important: The alarm will not sound when the keypad menu is active at the programmed alarm time.*

#### How to set the audio volume:

By default, the device uses the built-in hardware volume knob to determine the desired volume. You can change this to a pre-selected level as follows:
- Hold ```ENTER``` to invoke main menu
- Press ```2```/```8``` repeatedly until "VOLUME" is shown
- Press ```5``` or ```ENTER```
- Press ```2```/```8``` to toggle between "USE VOLUME KNOB" and "SELECT LEVEL"
- Press ```5``` or ```ENTER```
- If you chose "SELECT LEVEL", you can now select the desired level by pressing ```2```/```8```. The volume knob is now ignored.
- Press ```5``` or ```ENTER``` to save and quit the menu. "SAVING" is displayed briefly.

Pressing ```9``` at any point cancels and quits the menu.

You can also quickly set the volume through keypad commands ```300```-```320``` (select a level) and ```399``` (enables the volume knob).

If you are using a Rotary Encoder for volume, you need to disable the volume knob by pre-selecting a level (00-20). While the built-in volume knob is active, the Rotary Encoder will do nothing.

#### How to select the music folder number:

In order for this menu item to show up, an SD card is required.

- Hold ```ENTER``` to invoke main menu
- Press ```2```/```8``` repeatedly until "MUSIC FOLDER NUMBER" is shown
- Press ```5``` or ```ENTER```, "FOLDER" and a number is displayed
- Press ```2```/```8``` repeatedly to cycle through the possible values. The message "NOT FOUND" appears if either the folder itself or 000.mp3 in that very folder is not present. "PROCESSING REQUIRED" means that the TCD will prepare the folder (eg rename files) after selection; this requires a reboot.
- Press ```5``` or ```ENTER``` to select the value shown and exit the menu. "SAVING" is displayed briefly.

Pressing ```9``` at any point cancels and quits the menu.

If shuffle was enabled before, the new folder is also played in shuffled order.

#### How to select the Time-cycling Interval:

- Hold ```ENTER``` to invoke main menu
- Press ```2```/```8``` repeatedly until "TIME-CYCLING" is shown
- Press ```5``` or ```ENTER```, "INTERVAL" is displayed
- Press ```2```/```8``` repeatedly to cycle through the possible Time-cycling intervals. "0" disables automatic time cycling ("OFF").
- Press ```5``` or ```ENTER``` to select the value shown and exit the menu. "SAVING" is displayed briefly.

Pressing ```9``` at any point cancels and quits the menu.
 
#### How to adjust the display brightness:

- Hold ```ENTER``` to invoke main menu
- Press ```2```/```8``` repeatedly until "BRIGHTNESS" is shown
- Press ```5``` or ```ENTER```, the displays show all elements, the top-most display says "LVL"
- Press ```2```/```8``` repeatedly to cycle through the possible levels (1-15)
- Press ```5``` or ```ENTER``` to use current value and proceed to next display
- After the third display, "SAVING" is displayed briefly and the menu is left automatically.

Pressing ```9``` at any point cancels and quits the menu.
 
#### How to find out the IP address and WiFi status:

- Hold ```ENTER``` to invoke main menu
- Press ```2```/```8``` repeatedly until "NETWORK" is shown
- Press ```5``` or ```ENTER```, the displays show the IP address
- Repeatedly press ```2```/```8``` to cycle between IP address, WiFi status, MAC address (in station mode) and Home Assistant connection status.
- Press ```5``` or ```ENTER``` or 9 to leave the menu

#### How to set the Real Time Clock (RTC):

If you can't use network time (NTP) as a source of time, you need to manually adjust the TCD's clock. Moreover, manual clock adjustment is a required prerequisite for using [GPS](#gps-receiver). Before setting the TCD's clock, it is essential that you set the correct time zone in the [Config Portal](#the-config-portal).

Always set your actual local present time here; if you want to display some other time, use the Time Travel function. 

- Hold ```ENTER``` to invoke main menu
- Press ```2```/```8``` repeatedly until "SET CLOCK" is displayed and the *Present Time* display shows a date and time 
- Press ```5``` or ```ENTER```
- The *Present Time* display goes off and only the field to enter data into is shown, pre-set with its current value
- Data entry works as described [above](#the-keypad-menu); remember that months need to be entered numerically (01-12), and hours in 24-hour notation (0-23).
- After entering data into all fields, the data is saved and the menu is left automatically.

The time you entered will be re-set/overruled/re-adjusted when the TCD has access to authoritative time via NTP or GPS.

#### How to program dates/times for the *Destination* and *Last Time Departed* displays:

- Hold ```ENTER``` to invoke main menu
- Press ```2```/```8``` repeatedly until the display says "PROGRAM DATE" and the desired display shows a date and time
- Press ```5``` or ```ENTER```
- The display goes off and only the field to enter data into is shown, pre-set with its current value
- Data entry works as described [above](#the-keypad-menu); remember that months need to be entered numerically (01-12), and hours in 24-hour notation (00-23).
- After entering data into all fields, the data is saved and the menu is left automatically.

Your entered date/time(s) are stored, and shown until replaced by the results of time travels; you can then quickly bring your times back to the displays by entering keypad command ```998```.

When entering dates/times into the *destination time* or *last time departed* displays, Time-cycling Interval is paused for 30 minutes. 

Alternatively, you can program and store a "destination time" outside of the keypad menu by typing ```91mmddyyyyhhMM```, and a "last time departed" by ```92mmddyyyyhhMM```. 

#### How to view sensor info

- Hold ```ENTER``` to invoke main menu
- Press ```2```/```8``` repeatedly until "SENSORS" is shown. If that menu item is missing, a light or temperature sensor was not detected during boot.
- Press ```5``` or ```ENTER```
- Now the currently measured lux level or temperature is displayed.
- Press ```2```/```8``` to toggle between light sensor and temperature sensor info (if both are connected)
- Press ```5``` or ```ENTER``` or 9 to exit the menu

>Sometimes a lux value of -1 might be displayed, indicating a sensor overload. This can have the following reasons: The TCD firmware sets up the sensors for indoor usage and, as a result, sensors will overload in broad daylight. Secondly, some sensors have issues with halogen lamps (reportedly TSL2561), and most sensors also "overload" if too much IR light is directed at them, for instance from surveillance cameras.

#### How to see a list of BTTF-Network clients

- Hold ```ENTER``` to invoke main menu
- Press ```2```/```8``` repeatedly until "BTTFN CLIENTS" is shown.
- Press ```5``` or ```ENTER```
- Now one of the connected clients is displayed, or "NO CLIENTS" if currently no clients are connected.
- Press ```2```/```8``` to cycle through the list of connected clients.
- Press ```5``` or ```ENTER``` or 9 to exit the menu

#### How to leave the menu:

Press ```9``` in the main menu.

## Peripherals

![The BTTF Prop Family](img/family-head.png)

- [Fake Power Switch](#fake-power-switch)
- [Speedometer](#speedometer)
- [GPS-Receiver](#gps-receiver)
- [Rotary encoder](#rotary-encoder)
- [Temperature Sensor](#room-condition-mode-temperaturehumidity-sensor)
- [Light Sensor](#sensor-controlled-night-mode)
- [Other Props](#controlling-other-props) (Flux Capacitor, SID, Dash Gauges, VSR, Flux lights, ...)

## Fake power Switch 

You probably noticed that the device takes longer to boot than would be required to re-create the movie experience where Doc turns the knob and the Time Circuits immediately turn on. As a remedy, the firmware supports a fake "power switch": 

If the **_Use fake power switch_** option is checked in the Config Portal, the device will power-up, initialize everything, but stay quiet and dark. Only when the fake "power switch" is activated, the device will visually "power up". Likewise, you can also fake "power off" the device using this switch. Fake "off" disables the displays, all audio (except alarm, reminder and timer) and the keypad. Just like in the movie.

On Control Boards V1.3 and later, there is a dedicated header labeled "Fake PWR" to connect the switch to. The pins to be connected by the switch are labeled "GND" and "PWR Trigger":

![pwr_trigger](img/fakepwr.jpg)

On earlier Control Boards (1.2 and below), the switch needs connect the pins labeled "IO13" and "GND" as shown here: (The pin headers are not present on original boards)

![pwr_trigger1_2](img/fakepwr12.jpg)

The switch needs to be a switch with a maintained contact; the pins need to remain connected for as long as the device is fake-switched-on.

To use the Fake Power Switch, check **_Use fake power switch_** in the Config Portal.

[Here](https://tfc.out-a-ti.me) are some hints for building a TFC Switch like this one:

![TFC Switch](img/tfcswitch.jpg)

Fake-Power can also be controlled through [HomeAssistant/MQTT](#home-assistant--mqtt) and a modified [Futaba remote control](#futaba-remote-control).

## External Time Travel Trigger

As mentioned above, a time travel can be triggered by holding ```0``` on the keypad. Since this doesn't really allow for an authentic movie-like experience, the firmware also supports an external trigger, such as a button switch or even another prop to trigger a time travel. Unlike the [Fake Power Switch](#fake-power-switch), this trigger must be a momentary toggle.

On Control Boards V1.3 and later, there is a dedicated header for the button labeled "Time Travel". The button needs to connect pins "TT IN" and "GND".

| ![ttin](img/ttin.jpg) |
|:--:|
| TT_IN/GND on TCB 1.3 |

Unfortunately, there is no header for "TT_IN" on TC control boards V1.2 and below. There is, however, a row of solder pads right next to the socket on the control board, where a pin header or cable can easily be soldered on:

| ![tcboard_io27](img/ttin12.jpg) |
|:--:|
| TT_IN/GND on TCB 1.2 |

To trigger a time-travel sequence on the Time Circuits, "TT IN" and GND must be connected for at least 200ms and then opened; the time travel is triggered upon release of the button. If the button is pressed for 3000ms (3 seconds), a ["Return from Time Travel"](#time-travel) is triggered.

The Config Portal allows configuring a delay for matching/synchronizing the TCD to another prop. The delay, if any, starts running after the button is released. The time travel sequence starts after the delay has expired.

## Speedometer

The firmware supports [CircuitSetups's speedometer display](https://circuitsetup.us/product/delorean-time-machine-speedometer-kit) as part of the time travel sequence and for other purposes.

| [![Watch the video](https://img.youtube.com/vi/opAZugb_W1Q/0.jpg)](https://youtu.be/opAZugb_W1Q) |
|:--:|
| Click to watch the video |

_The video was shot before the CircuitSetup speedo became available. The speedo shown is a DIY prop and not the - much better looking - CircuitSetup speedo. The video is only meant to demonstrate how the TCD and the speedo inter-operate. (The TFC switch was made by me, see [here](https://tfc.out-a-ti.me), it uses the [Fake Power Switch](#fake-power-switch) feature of the TCD.)_

If your CircuitSetup [Speedo Kit](https://circuitsetup.us/product/delorean-time-machine-speedometer-kit/) came with a cable with 7 wires, it needs to be wired as shown below:

![speedo_i2c](img/speedo_i2c.jpg)

The SDA and SCL wires should be paired with a wire connected to GND. If you using a 4 wire twisted-pair cable, pair SCL with GND, and SDA with 5V.

If the cable is shielded, connect the shield to GND on the TCD's end (not the other!). Also see [here](AddOns.md#i2c-peripheral-wiring).

If you want to make your own speedo, see [here](AddOns.md#speedometer).

#### Software setup

In order to use the Speedometer display, select the correct model/display type in the Config Portal. 

## GPS receiver

A GPS receiver can be used as a source of authoritative time (like NTP), speed of movement and geolocation mode.

The CircuitSetup original [speedo](https://circuitsetup.us/product/delorean-time-machine-speedometer-kit) has a built-in GPS receiver. If you want to use a third party GPS receiver, see [here](AddOns.md#gps-receiver). 

GPS receivers receive signals from satellites, but in order to do so, they need to be "tuned in" (in GPS-lingo: get a "fix"). This "tuning" process can take a long time; after first power up, it can take 30 minutes or more for a receiver to be able to determine its position. To speed up this process, modern GPS receivers have special "assisting" features. One key element is knowledge of current time, as this helps identifying satellite signals quicker. So, in other words, initially, you need to tell the receiver what it is supposed to tell you. However, as soon as the receiver has received satellite signals for 15-20 minutes, it saves the data it collected to its battery-backed memory and will find a fix within seconds after power-up in the future.

For using GPS effectively as a long-term source of accurate time, it is therefore essential, that 
- the correct time zone is defined in the Config Portal,
- the Time Circuit's RTC (real time clock) is initially [set to correct local time](#how-to-set-the-real-time-clock-rtc), 
- and the GPS receiver has been receiving data for 15-20 mins at least once a month.

If/as long as the GPS receiver has a fix and receives data from satellites, the dot in the *present time*'s year field is lit.

To use the GPS receiver as a source of time, the option [**_Use GPS time_**](#-use-gps-time) must be checked in the Config Portal (which it is by default).

### Geolocation mode

If the TCD is connected to the CircuitSetup Speedo or a third-party GPS receiver, it can display your current location.

| ![geolocation](img/geomode.jpg) |
|:--:|
| *Geolocation mode* |

Three different notations are supported:
- DD: Decimal degrees;
- DMS: Degrees, minutes, seconds;
- DMD: Degrees, decimal minutes. This is the most precise one of the three.

To toggle geolocation mode, enter keypad commands ```114``` (DD), ```115``` (DMS) or ```116``` (DMD). Geolocation mode is mutually exclusive to World Clock, Room Condition and Minimal mode, and disabled when a Time Travel is initiated. If an SD card is present, Geolocation mode is persistent across reboots.

### GPS for speed

One nice feature of GPS is that the receiver can deliver current speed of movement. If the Time Circuits are, for instance, mounted in a car, and a [speedo](#speedometer) is connected, you'll have a real speedometer:

| [![Watch the video](https://img.youtube.com/vi/wbeXZJaDLa8/0.jpg)](https://youtu.be/wbeXZJaDLa8) |
|:--:|
| Click to watch the video |

To have GPS speed displayed on your speedo, check **_Display GPS speed_** in the Config Portal. 

To let other props connected through [BTTF-Network](#connecting-props-wirelessly-bttf-network-bttfn) know about current GPS speed, check the option **_Provide GPS speed to wireless props_**.

Setting these options gives GPS speed priority over speed from a [rotary encoder](#rotary-encoder), and, as regards the speedo display, over other purposes (such as displaying temperature). Checking them really does not make sense when your props are permanently stationary.

> [!NOTE]
> The only indicator for a fix is the dot in the *present time*'s year field. The speedo will show "0" when the receiver has no fix. If there was a fix, and speed was greater than 3mph when the signal was lost, the speedo will display "-" for 60 seconds and then switch to "0". 

## Rotary Encoder

A rotary encoder is a sensor that converts the physical rotation or position of a shaft into electrical signals or, simply put, a turnable knob. The TCD supports rotary encoders for adjusting speed and/or audio volume.

For information on supported encoder models/types and wiring, see [here](AddOns.md#rotary-encoder).

Up to two rotary encoders can be connected, one for speed, one for volume.

### Rotary Encoder for Speed 

A rotary encoder for speed allows manually selecting speed to be displayed on the speedo, as well as to be sent to [BTTFN](#connecting-props-wirelessly-bttf-network-bttfn) clients in place of actual (GPS) speed.

| [![Watch the video](https://img.youtube.com/vi/Y6uu1SU6YJA/0.jpg)](https://youtu.be/Y6uu1SU6YJA) |
|:--:|
| Click to watch the video |

Remarks:
- The encoder is only evaluated if no GPS receiver is connected or if the **_Display GPS speed_** is unchecked (as this option gives GPS speed priority over the encoder).
- The encoder is also evaluated if no speedo is connected; it can be operated "blindly" to trigger time travels and its movement is sent to BTTFN clients like GPS speed (if no GPS receiver is connected or the option **_Provide GPS speed to wireless props_** is unchecked)
- The speedo displays "0" as long as the encoder is not moved; if the encoder is turned counter-clockwise a couple of notches, the speedo will be switched off.

### Rotary Encoder for Audio Volume

A rotary encoder for volume replaces the volume knob on back of the TCD's keypad. The advantages of the rotary encoder are that it is more precise, especially at lower volume levels, and it can be physically relocated. To use a rotary encoder for volume, the TCD's own volume knob must be disabled; this is done by pre-selecting an audio level in the keypad menu or by entering keypad commands ```3xx``` (xx being 00-20).

## Room Condition Mode, Temperature/humidity sensor

The firmware supports various [temperature/humidity sensors](AddOns.md#temperaturehumidity-sensor) for "Room Condition mode"; in this mode, *destination* and *last departed* times are replaced by temperature and humidity, respectively. To toggle between normal and Room Condition mode, enter keypad command ```111```. If an SD card is present, Room Condition mode is persistent across reboots.

![rcmode](img/rcmode.jpg)

"WC/RC hybrid mode", which is Room condition mode combined with [World Clock mode](#world-clock-mode), is described [here](#wcrc-hybrid-mode).

Temperature on speedometer display: Unless you do time traveling on a regular basis, the [speedo](#speedometer) is idle most of the time in a typical home setup. To give it more of a purpose, the firmware can display ambient [temperature on the speedo](#-display-temperature) while idle. 

A connected sensor is auto-detected, no configuration is required. For information on supported sensor models and wiring, see [here](AddOns.md#temperaturehumidity-sensor).

## Controlling other props

### Connecting props wirelessly: BTTF-Network (BTTFN)

The TCD can communicate with other compatible props wirelessly, via the built-in "**B**asic-**T**elematics-**T**ransmission-**F**ramework" over WiFi. It can send out information about a time travel and an alarm, and other props can query the TCD for time, speed and some other data.

Here is a demonstration of all the props connected through BTTFN:

| [![Watch the video](https://img.youtube.com/vi/u9oTVXUIOXA/0.jpg)](https://youtu.be/u9oTVXUIOXA) |
|:--:|
| Click to watch the video |

BTTFN requires the props to be connected to the same network, such as, for example, your home WiFi network. 

![STAmode](img/stamode-bttfn.png)

>In order to use BTTFN, all props must be connected to the same IP subnet; BTTFN does not work over the internet.

On the TCD, no special configuration is required for BTTFN. 

On the other prop, such as CircuitSetup's [Flux Capacitor](https://circuitsetup.us/product/flux-capacitor-light-sound-pcb/), [SID](https://circuitsetup.us/product/delorean-time-machine-status-indicator-display-sid/), the [Dash Gauges](https://circuitsetup.us/product/delorean-time-machine-dash-gauge-control-board/), the [VSR](https://vsr.out-a-ti.me) or the [Futaba Remote Control kit](https://circuitsetup.us/product/futaba-remote-stanley-display-wireless-control-kit/?v=7d0db380a5b9), the TCD's hostname (usually _timecircuits_) must be entered into the *Hostname or IP address of TCD* field on the Setup page in their Config Portal - that's all.

To see which BTTFN clients are currently known to the TCD, either check at the Config Portal's main page or enter the keypad menu and select "BTTFN CLIENTS", 

#### Car Mode

As [discussed](#wifi-setup), in a car or other places without a WiFi network, the TCD can act as WiFi access point for other props. The recommended network configuration for this use case is as follows:

![APmode](img/apmode-car.png)

When set in *Car Mode*, the TCD _always boots into AP-mode_, regardless of a configured WiFi network. Not attempting to connect to a network speeds up the boot process and allows other BTTFN-capable props to quickly connect to "TCD-AP".

To enable *Car Mode*, enter keypad command ```991```. The TCD will reboot in AP mode. If a WiFi network to connect to is configured at that point, it is ignored; no connection attempt is made.

To disable *Car Mode*, enter keypad command ```990```. The TCD will reboot and attempt to connect to a previously configured WiFi network.

*Car Mode* is persistent, i.e. it remains active (even across reboots and power-downs) until disabled.

A compilation of best practices in Car Mode is [here](#car-setup---best-practice).

### Connecting props by wire

The TCD has a TT-OUT pin (marked "TT OUT (IO14)" or "IO14") which can be used to
- signal a time travel,
- signal alarm,
- or manually switching on/off connected props.

#### Signal a Time Travel

If the option [TT-OUT (IO14) pin] **_signals Time Travel_** is checked in the Config Portal, the TCD sets this pin to HIGH either 5 seconds ahead of the temporal displacement sequence or - if the option **_Signal without 5s lead_** is checked - right at the start of the temporal displacement sequence. This allows third-party props to take part in time travel sequences. For more information, see [here](AddOns.md#other-props).

CircuitSetup/A10001986 original props also support a wired connection, if for whatever reason BTTFN is not an option. For detailed wiring instructions, please see the documentation for the prop ([Flux capacitor](https://github.com/CircuitSetup/Flux-Capacitor#connecting-a-tcd-by-wire), [SID](https://github.com/CircuitSetup/SID#connecting-a-tcd-by-wire), [Dash Gauges](https://github.com/realA10001986/Dash-Gauges/blob/main/Hardware.md#connecting-a-tcd-to-the-dash-gauges-by-wire), [VSR](https://github.com/realA10001986/VSR#connecting-a-tcd-by-wire)); 

In case CircuitSetup/A10001986 original props are connected by wire, the option **_Signal without 5s lead_** should _not_ be set since it deletes the props’ "acceleration phase"; however, if that option is set on the TCD (for instance, because third-party props, unaware of the 5 second lead, are connected by wire as well), the corresponding option must be set in the CircuitSetup/A10001986 prop's Config Portal, too. This option has no effect for wirelessly connected props.

#### Signal Alarm

If the option [TT-OUT (IO14) pin] **_signals alarm_** is checked in the Config Portal, the TCD sets this pin to HIGH upon an [alarm](#alarm); the duration for HIGH can be between 3 and 99 seconds.

#### Switching TT-OUT manually

If the option [TT-OUT (IO14) pin] **_is controlled by commands 900/901_** is checked in the Config Portal, keypad commands ```900``` (off) and ```901``` (on) allow switching this pin manually. The power-up state of the TT OUT pin can be set to HIGH by checking the **_Power-up state HIGH_** option.

#### Limitations

Although the options can be set freely and are not mutually exclusive, be advised that CircuitSetup/A10001986 original props connected by wire always interpret the TT-OUT signal as a trigger for a time travel sequence. It can make sense to set more than one option if your connect, for instance, flux bands or lights.

Hardware considerations: CS/A10001986 props can be connected directly. TT OUT cannot be used to supply power for third party props; please us a relay. In case of a standard "Arduino relay module", connect "-"/"GND" to GND, "+"/"VCC"/"5V" to 5V, and "S"/"IN" to TT OUT.

See also [here](AddOns.md#other-props), chapter "Other props".

## Home Assistant / MQTT

By means of MQTT, the TCD can
- display messages on configured topics on its displays,
- send pre-programmed messages to pre-programmed topics,
- be remote controlled through commands sent to **bttf/tcd/cmd**
- send out notifications on time travel and alarm for use by third party props.

The TCD supports MQTT protocol versions 3.1.1 and 5.0.

### Display messages

The TCD can subscribe to three user-configured topics and display messages received for these topics on all three displays. This can be used to display the status of other HA/MQTT devices, for instance alarm systems. 

If the SD card contains a file named 
- "ha-alert.mp3" (for _Destination Time_ display),
- "ha-alart-p.mp3" (for _Present Time_  display) and/or
- "ha-alert-l.mp3" (for _Last Time Departed_  display),

this file will be played upon reception of a message for the respective display. There are no default sounds.

Only ASCII messages are supported, the maximum length is 255 characters.

### Send messages

The TCD can send configurable messages to configurable topics through keypad commands ```600``` up to ```609```. Both topics and messages are programmed in the Config Portal.

### Control the TCD via MQTT

The TCD can be controlled through messages sent to topic **bttf/tcd/cmd**. Supported commands are
- ```TIMETRAVEL```: Start a time travel
- ```RETURN```: Return from time travel
- ```BEEP_ON```: Enables the [beep](#beep-on-the-second)
- ```BEEP_OFF```: Disables the [beep](#beep-on-the-second)
- ```BEEP_30```, ```BEEP_60```: Set the beep modes as described [here](#beep-on-the-second)
- ```ALARM_ON```: Enable the alarm
- ```ALARM_OFF```: Disable the alarm
- ```ALARM_STOP```: Stop on-going alarm and cancel a snoozed alarm
- ```ALARM_SNOOZE```: Put an on-going alarm into snooze
- ```NIGHTMODE_ON```: Enable manual [night mode](#night-mode)
- ```NIGHTMODE_OFF```: Disable manual [night mode](#night-mode)
- ```MP_PLAY```: Starts the Music Player
- ```MP_STOP```: Stops the Music Player
- ```MP_NEXT```: Jump to next track
- ```MP_PREV```: Jump to previous track
- ```MP_SHUFFLE_ON```: Enables shuffle mode in Music Player
- ```MP_SHUFFLE_OFF```: Disables shuffle mode in Music Player
- ```MP_REQSTATUS```: Publish current [music player status](#-publish-music-player-status-to-bttftcdmpstatus) to bttf/tcd/mpstatus
- ```PLAYKEY_x```: Play keyX.mp3 (from SD card), X being in the range from 1 to 9.
- ```STOPKEY```: Stop playback of keyX file. Does nothing if no keyX file is currently played back.
- ```PLAY_DOOR_OPEN```, ```PLAY_DOOR_CLOSE```: Play door sound
- ```PLAY_DOOR_OPEN_L```, ```PLAY_DOOR_CLOSE_L```: Play door sound on left stereo channel
- ```PLAY_DOOR_OPEN_R```, ```PLAY_DOOR_CLOSE_R```: Play door sound on right stereo channel
- ```VOLUME_UP```, ```VOLUME_DOWN```: Increase/decrease volume by a notch
- ```VOLUME_SET_x```: Set volume to x% (x=0-100)
- ```POWER_CONTROL_ON```: Take over Fake-Power control; POWER_xx commands now control Fake-Power.
- ```POWER_CONTROL_OFF```: Release Fake-Power control
- ```POWER_ON```, ```POWER_OFF```: Switch Fake-Power on or off, respectively.
- ```INJECT_x```: See immediately below.

#### The INJECT_x command

This command allows controlling the TCD through HA/MQTT in the same way as through pressing keys on the keypad. By means of this command, you can "enter" dates/times as well as keypad commands. Commands are listed [here](#commandref); nearly all are supported. For example:

To set 12/25/0000 as the destination date, issue ```INJECT_12250000```

To enable the "beep" (21), issue the following command: ```INJECT_21```

To play "key2.mp3" (502), issue ```INJECT_502```

To set the alarm to 9:00am (110900), issue ```INJECT_110900```

#### Fake-Power control through HA

HA can control [Fake-Power](#fake-power-switch), overruling a Fake-Power switch.

In order to let HA/MQTT control fake power, first publish ```POWER_CONTROL_ON``` to **bttf/tcd/cmd**. Subsequent ```POWER_ON``` or ```POWER_OFF``` commands switch Fake-Power on or off, respectively.

```POWER_CONTROL_OFF``` relinquishes Fake-Power control; afterwards, if a Fake-Power switch is connected, its state becomes effective. If no switch is connected, Fake-Power will be switched on.

The initial power-up state of POWER_CONTROL and POWER can be configured in the [Config Portal](#-ha-controls-fake-power-at-startup).

Keypad command ```996``` works like ```POWER_CONTROL_OFF```; it allows to separate HA from Fake-Power control. This is useful when, for instance, the broker isn't reachable.

### Notify other devices of a time travel or alarm

The TCD can send out notifications on time travel and/or alarm through MQTT. This enables the use of MQTT-capable devices to react to, and take part in time travel and/or alarm sequences by simply listening to the TCD's public topic **bttf/tcd/pub**.

To enable the sending of time travel and/or alarm notifications, check the options **_Publish time travel events_** and/or **_Publish alarm events_** on the _HA/MQTT Settings_ page in the Config Portal. These options, however, have some implications for BTTFN-connected devices, see [below](#MQTT-vs-BTTFN).

The timing for time travel is described [here](AddOns.md#synchronized-time-travel-through-hamqtt), in short:
- ```PREPARE``` might be published ahead of the time travel to prepare; the timing is not specified.
- ```TIMETRAVEL``` or ```TIMETRAVEL_xxxx_yyyy``` is published [on or 5 seconds ahead](#-enhanced-time-travel-notification) of the temporal displacement sequence.
- ```REENTRY``` is published upon re-entry.

```WAKEUP``` is published if something happens on the TCD, like destination time entry or speed changes.

When the [alarm](#alarm) sounds, the TCD publishes ```ALARM```.

### MQTT vs BTTFN

MQTT and BTTFN work fine along each other.

BTTFN is the primary way of inter-prop communication. The majority of network features (such as mutual remote controlling, transmission of speed, synchronized fake-power and night mode switching, etc.) _require_ a BTTFN connection. These features are not supported through MQTT. Therefore, to work as designed, all BTTFN-compatible props need to be properly configured to connect to the TCD through BTTFN.

The only inter-prop communication features that are covered by both BTTFN and MQTT are _time travel_ and _alarm_. 

The TCD can send out time travel and alarm notifications through **_either_ MQTT _or_ BTTFN**, and you must make a choice:
- If the options **_Publish time travel events_** and **_Publish alarm events_** on the _HA/MQTT Settings_ page are checked, respective notifications are exclusively sent over MQTT. Therefore, all props that are supposed to take part in time travel and/or alarm sequences must be connected to the same broker. That includes all CircuitSetup/A10001986 props.
- If either of these options is unchecked, respective notifications are sent exclusively over BTTFN.

Checking these options really only makes sense if there are MQTT-capable, but BTTFN-incapable props to take part in time travel and/or alarm sequences. If that is not the case, please leave these options unchecked.

### Setup

MQTT requires a "broker" such as [mosquitto&#10548;](https://mosquitto.org/), [Cassandana&#10548;](https://github.com/mtsoleimani/cassandana), [RabbitMQ&#10548;](https://www.rabbitmq.com/), [Ejjaberd&#10548;](https://www.ejabberd.im/), [HiveMQ&#10548;](https://www.hivemq.com/) or [EMQX&#10548;](https://www.emqx.com/), to name a few. For proper operation with low latency, running the broker on your local network is recommended.

![MQTT connection](img/stamode-mqtt.png)

The broker's address needs to be configured in the Config Portal. It can be specified by either domain or IP (IP preferred). The default port is 1883. If a different port is to be used, append a ":" followed by the port number to the domain/IP, such as "192.168.1.5:1884". 

If your broker supports protocol version 3.1.1, stick with 3.1.1. Version 5.0 has no advantages, but more overhead.

If your broker does not allow anonymous logins, a username and password can be specified.

Limitations: TLS/SSL not supported; ".local" domains (MDNS, Bonjour) not supported; maximum message length 255 characters; the machine running the broker must respond to PING (ICMP) echo requests. Using HA/MQTT will disable [WiFi power saving](#wifi-power-saving-features). MQTT is disabled when the TCD is operated in AP-mode or car mode.

## Futaba Remote Control

CircuitSetup's [kit for modifying a Futaba remote control](https://circuitsetup.us/product/futaba-remote-stanley-display-wireless-control-kit/) allows, among many features, to control the TCD's speedo. The Remote can increase/decrease speed, trigger a time travel, switch fake power, and more. 

In order to permit remote controlling, enter keypad command ```993```. No further configuration is required on the TCD's side.

To prohibit remote controlling, enter keypad command ```992```. 

For more information, see [here](https://github.com/CircuitSetup/Remote).

## Car Setup - Best Practice

> In the following, default settings are assumed. If you, for instance, changed your TCD's hostname, this hostname is to be used instead of _timecircuits_ below.

#### General

- Do not connect the props to your car's electrical system. Use a separate power supply, such as a lithium battery, with constant power output (no peaks, no degrading voltage on depletion).
- Put good-quality ("endurance") SD cards into all the props.
  
#### Network setup

In a car, the TCD acts as WiFi access point, to which the other props are connected:

![APmode](img/apmode-car.png)

This configuration is achieved automatically by putting all props into [Car Mode](#car-mode). 

- TCD: Keypad commands ```990```/```991``` disable/enable Car Mode. 
- FC and SID: IR command sequences ```*990ok```/```*991ok``` disable/enable Car Mode.
- Dash Gauges: Holding "Button 1" for 6 seconds (until a triple beep is emitted) toggles Car Mode.
- VSR: Holding ```9``` in Admin Button Mode toggles Car Mode.
- Remote: Holding "Calibration" for 6 seconds (until a triple beep is emitted) toggles Car Mode.

Please refer to the other props' documentation, chapter "Car Setup", for details: [Flux Capacitor](https://fc.out-a%2dti.me#car-setup), [SID](https://sid.out%2da%2dti.me#car-setup), [Dash Gauges](https://dg.out%2da-ti.me#car-setup), [VSR](https://vsr.out-a%2dti.me#car-setup), [Remote Control](https://remote.out-a%2dti%2eme#car-setup).

> If your car might come close to other cars with identical equipment, for instance at meet-ups, it is recommended to add your TCD's BSSID (a unique identifier of your TCD) in the other props' Car Mode settings. To find out your TCD's BSSID, check the TCD's Config Portal's _WiFi Configuration_ page, section _Access Point settings_. Copy the value next to **_TCD-AP BSSID_** (XX:XX:XX:XX:XX:XX) into the field "TCD-AP BSSID" under _Car Mode Settings_ on all the other props' _WiFi Configuration_ pages. **Firmwares released after September 19, 2026, do this automatically upon the first successful connection to your TCD in Car Mode.**

#### Accessing the Config Portal while in Car Mode

1. Connect your notebook/handheld to WiFi network "TCD-AP".
2. Navigate your browser to the prop's Config Portal. By default the domains are http://timecircuits.local, http://flux.local, http://sid.local, http://gauges.local, http://vsr.local, http://dtmremote.local.

#### Typical Option setting for in-car operation

- TCD:
  - Check **_Display GPS Speed_**
  - Check **_Provide GPS speed to BTTFN clients_**

- Other props (FC, SID, Dash Gauges, VSR, Remote):
  - Put TCD's hostname (usually _timecircuits_) in **_Hostname of TCD_**. (The other options under "Wireless connection (BTTFN)" can be set/unset based on your personal preferences.)
  - Uncheck **_TCD is connected by wire_** (Option not available on Remote)

#### Performing Firmware Updates

1. Download the firmware binaries and sound-packs for all props to be updated to your notebook/handheld.
2. Connect said notebook/handheld to WiFi network "TCD-AP".
3. Navigate your browser to the prop's Config Portal. By default the domains are http://timecircuits.local, http://flux.local, http://sid.local, http://gauges.local, http://vsr.local, http://dtmremote.local.
4. Perform firmware update procedure. Repeat steps 2-4 for installing the sound-pack, if a new version is available.

#### Time Synchonization

The TCD has no internet access while in Car Mode; this means that, unless a GPS receiver is present, it cannot update its clock automatically. If the clock runs off over time (which usually is something like 1 minute in 6-8 months), you either quit Car Mode once in a while and allow the TCD connect to a internet-connected WiFi network or re-adjust time using the [keypad menu](#how-to-set-the-real-time-clock-rtc). 

For the first alternative, it is recommended to pre-configure the TCD to connect to a WiFi network (eg. your iPhone's WiFi hotspot) when *not* in Car mode. In order to do so, 
- quit Car Mode (```990```),
- enter the TCD's Config Portal by connecting to "TCD-AP" and navigating to http://timecircuits.local, enter "WiFi Settings", and [connect](#connecting-to-an-existing-wifi-network) the TCD to your WiFi network.
- After saving the new settings and thereby rebooting, re-enable Car Mode (```991```).

In order to sync time, have your WiFi network ready (eg, by enabling the iPhone hotspot), and
- power up the TCD in Car Mode,
- disable Car Mode (```990```),
- and wait until the TCD has rebooted and connected to your WiFi network. Time synchronization is usually done in the first few seconds after a reboot.
- re-enable Car Mode (```991```).

## WiFi power saving features

The Config Portal offers two options for WiFi power saving, one for station mode (ie when the device is connected to a WiFi network), one for AP-mode (ie when the device acts as an access point). Both options do the same: They configure a timer after whose expiration WiFi is switched off; the device is no longer transmitting or receiving data over WiFi. 

The timers can be set to 0 (which disables them; WiFi is never switched off; this is the default) or 10-99 minutes. 

The reason for having two different timers for AP-mode and for station mode is that if the device is used in a car, it might act as an access point (such as in [car mode](#car-mode)), while at home it is most probably connected to a WiFi network as a client. Since in a car, unless other props are installed that communicate wirelessly, WiFi will most likely not be used on a regular basis, the timer for AP mode can be short (eg 10 minutes), while the timer for station mode can be disabled.

After WiFi has been switched off due to timer expiration, it can be re-enabled by holding ```7``` on the keypad for approx. 2 seconds, in which case the timers are restarted (ie WiFi is again switched off after timer expiration).

If your configured WiFi network was not available when the TCD was trying to connect, it will end up in AP-mode. Holding ```7``` in that case will trigger another attempt to connect to your WiFi network.

## Flash Wear

Flash memory has a somewhat limited lifetime. It can be written to only between 10.000 and 100.000 times before becoming unreliable. The firmware writes to the internal flash memory when saving settings and other data. Every time you change settings through the keypad menu or the Config Portal, data is written to flash memory.

To reduce the number of write operations and thereby prolong the life of your TCD, it is recommended to use a good-quality SD card and to check **_[Save secondary settings on SD](#-save-secondary-settings-on-sd)_** in the Config Portal; secondary settings (volume, alarm, reminder, car-mode state, exhibition mode data and state, time travel data and state) are then stored on the SD card (which also suffers from wear but is easy to replace). See [here](#-save-secondary-settings-on-sd) for more information.

## Firmware Installation / Firmware Update

To update the firmware of your TCD, enter the [Config Portal](#the-config-portal), click on "Update & Upload", select the pre-compiled binary file ("**timecircuits-A10001986-Vx.xxx-XXXX.bin**" for A10001986 releases, "**Time_Circuits_Display_vX.YY.bin**" for CircuitSetup releases) provided in the [Release package](https://github.com/CircuitSetup/Time-Circuits-Display/releases), and click on *Update*. 

> [!IMPORTANT]
> Do not install "A-Car" and/or "GTE" labeled versions on standard versions of the TCD, those are for modified/different hardware! Unless you know for a fact that you have "A-Car" displays or a "GTE" keypad, you need the "standard" firmware file.

<details>
<summary>Installing on a fresh ESP32...</summary>
If you are using a fresh ESP32, please go <a href="https://install.out-a-ti.me">here</a> and follow the instructions or - if you are a nerd and want to deal with source code, compilers'n'stuff - see <a href="https://github.com/CircuitSetup/Time-Circuits-Display/blob/master/Software/src/timecircuits.ino">timecircuits-A10001986.ino</a> for detailed build and upload information.
</details>

### Sound-pack installation

The firmware comes with a sound-pack which needs to be installed separately. The sound-pack is not updated as often as the firmware itself. There will be a message in the Config Portal and the TCD will display "PLEASE INSTALL SOUND PACK" during boot when/if the sound-pack needs to be updated.

_Installing the sound-pack requires an [SD card](#sd-card)._

>If your factory-fresh TCD came without an SD card, you need to re-install the sound-pack to be able to enjoy all of the provided sounds. Parts of the sound-pack are installed to your SD card.

>A10001986 and CircuitSetup use different sound-packs. If you switch from one version to the other, the matching sound-pack must be re-installed. [A10001986-releases](https://github.com/CircuitSetup/Time-Circuits-Display/releases) use "sound-pack-**tw**XX", while [CircuitSetup's](https://github.com/CircuitSetup/Time-Circuits-Display/releases) are named "sound-pack-**cs**XX". The Config Portal will tell you which version is required to be installed.

The first step is to extract the zipped sound-pack (which is included in every [Release package](https://github.com/CircuitSetup/Time-Circuits-Display/releases)). It contains one file named "TCDA.bin".

Next, head to the [Config Portal](#the-config-portal), click on "Update & Upload", select the "TCDA.bin" file in the _bottom_ file selector and click on *Upload*.

<details>
<summary>Alternative way</summary>
<br>
Alternatively, you can install the sound-pack the following way:
<ul>
<li>Using a computer, copy "TCDA.bin" to the root directory of a FAT32 formatted SD card;</li>
<li>power down the TCD,</li>
<li>insert this SD card into the slot and</li>
<li>power up the TCD; the sound-pack will be installed automatically.</li>
</ul>
  
*Since version 3.23, a considerable part of the sound-pack is installed on the SD card itself. As a result, to enjoy all provided sound effects, the SD card has to remain in the slot.*
</details>

---

## Appendix A: The Config Portal

### Main page

##### &#9193; WiFi Configuration

This leads to the [WiFi configuration page](#wifi-configuration)

##### &#9193; Settings

This leads to the [Settings page](#settings).

##### &#9193; Peripherals

This leads to the [Peripherals settings page](#settings-for-peripherals).

##### &#9193; HA/MQTT Settings

This leads to the [HomeAssistant/MQTT Settings page](#hamqtt-settings).

##### &#9193; Update & Upload

This leads to the firmware update and audio upload page.

To upload a new firmware, such as published in the [Release packages](https://github.com/CircuitSetup/Time-Circuits-Display/releases), select the "**timecircuits-A10001986-Vx.xxx-XXXX.bin**" or "**Time_Circuits_Display_vX.YY.bin**" file as contained in the Release package in the _top_ file selector and click *Update*. 

> [!IMPORTANT]
> Do not install "A-Car" and/or "GTE" labeled versions on standard versions of the TCD, those are for modified/different hardware! Unless you know for a fact that you have "A-Car" displays or a "GTE" keypad, you need the "standard" firmware file.

You can also install the TCD's sound-pack on this page; download the sound-pack (which is included in every [Release package](https://github.com/CircuitSetup/Time-Circuits-Display/releases)), extract it and select the resulting TCDA.bin file in the _bottom_ file selector. Finally, click *Upload*. An SD card is required for this operation.

See also [here](#firmware-installation--firmware-update).

Finally, this page is also for uploading [custom or replacement sound files](#installing-custom--replacement-audio-files) to the SD card. Select one or more mp3 file in the _bottom_ file selector and click *Upload*. (Maximum 16 files at a time.)

---

### WiFi Configuration

Through this page you can either connect your TCD to your local WiFi network or configure AP mode. 

#### <ins>Connecting to an existing WiFi network</ins>

To connect your TCD to your WiFi network, all you need to do is either to click on one of the networks listed at the top or to enter a __WiFi network name (SSID)__, and optionally a __password__ (WPAx). If there is no list of networks displayed, click on "Scan for Networks".

>By default, the TCD requests an IP address via DHCP. However, you can also configure a static IP for the TCD by entering the IP, netmask, gateway and DNS server. All four fields must be filled for a valid static IP configuration. If you want to stick to DHCP, leave those four fields empty.

If there are several APs with identical SSID nearby, the TCD will connect to the first one it finds, which might not be the one with the strongest signal. It is therefore recommended to select the nearest/strongest AP by its BSSID (AP's MAC address). You can either manually find out your AP's BSSID and enter it, or have it filled out automatically: Click "Scan for networks", then "Show all". If you click on an AP, its BSSID will be copied into BSSID field in the form below. To see which AP is which, hover over the name to see its BSSID as a tooltip.

##### &#9193; Forget Saved WiFi Network

Checking this box (and clicking SAVE) deletes the currently saved WiFi network (SSID and password) and reboots the device; it will restart in "access point" (AP) mode. See [here](#wifi-setup).

##### &#9193; Hostname

The device's hostname in the WiFi network. Defaults to 'timecircuits'. This also is the domain name at which the Config Portal is accessible from a browser in the same local network. The URL of the Config Portal then is http://<i>hostname</i>.local (the default is http://timecircuits.local)

If you have more than one TCD in your local network, please give them unique hostnames.

_This setting applies to both AP-mode and when your TCD is connected to a WiFi network._ 

##### &#9193; WiFi connection attempts

Number of times the firmware tries to connect to a WiFi network, before falling back to AP-mode. See [here](#wifi-setup)

##### &#9193; Periodic reconnection attempts

Selects whether periodic re-connection attempts (between 12am and 6am) should be made after a failure to connect to a configured WiFi network.

In typical home setups with 24/7 WiFi, this option hardly matters. However, if you have connected your TCD to your WiFi network, but move it between environments (with and without WiFi access) on a regular basis, uncheck this to keep the TCD from searching for your configured WiFi network unnecessarily.

This option has no effect if the TCD is in [Car Mode](#car-mode).

##### &#9193; WiFi power save timer

See [here](#wifi-power-saving-features)

#### <ins>Settings for AP-mode</ins>

##### &#9193; Network name(SSID) appendix

By default, when your TCD creates a WiFi network of its own ("AP-mode"), this network is named "TCD-AP". In case you have multiple TCDs in your vicinity, you can have a string appended to create a unique network name. If you, for instance, enter "-ABC" here, the WiFi network name will be "TCD-AP-ABC". Characters A-Z, a-z, 0-9 and - are allowed.

##### &#9193; Password

By default, and if this field is empty, the TCD's own WiFi network ("TCD-AP") will be unprotected. If you want to protect your TCD access point, enter your password here. It needs to be 8 characters in length and only characters A-Z, a-z, 0-9 and - are allowed.

If you forget this password and are thereby locked out of your TCD, power-down, hold the ```ENTER``` key, power-up and wait until the white LED flashes, then release the ```ENTER``` key. The TCD will boot and start the access point temporarily without a password. Then connect to the TCD's AP with your computer or handheld, enter the Config Portal and either look up or change your AP WiFi password. This ENTER-key-procedure is not persistent: When you reboot or re-power the TCD, the AP will be password protected again.

##### &#9193; WiFi channel

Here you can select one out of 11 channels or have the TCD choose a random channel for you. The default channel is 1. Preferred are channels 1, 6 and 11.

WiFi channel selection is key for a trouble-free operation. Disturbed WiFi communication can lead to disrupted sequences, packet loss, hanging or freezing props, and other problems. A good article on WiFi channel selection is [here&#10548;](https://community.ui.com/questions/Choosing-the-right-Wifi-Channel-on-2-4Ghz-Why-Conventional-Wisdom-is-Wrong/ea2ffae0-8028-45fb-8fbf-60569c6d026d).

If a WiFi Scan was done (which can be triggered by clicking "Scan for networks"), 

- a list of networks is displayed at the top of the page; click "Show All" to list all networks including their channel;
- a "proposed channel" is displayed near the "WiFi channel" drop-down, based on a rather simple heuristic. The banner is green when a channel is excellent, grey when it is impeded by overlapping channels, and when that banner is red operation in AP mode is not recommended due to channels all being used.

The channel proposition is based on all WiFi networks found; it does not take non-WiFi equipment (baby monitors, cordless phones, Bluetooth devices, microwave ovens, etc) into account.

##### &#9193; WiFi power save timer

See [here](#wifi-power-saving-features)

---

### Settings

#### <ins>Basic settings</ins>

##### &#9193; Play intro

Selects whether the animated intro should be played upon power-up.

##### &#9193; Beep mode

Selects the ["beep"](#beep-on-the-second) mode. "Auto: xx secs" enables the beep for xx seconds after entering a destination time, after triggering a time travel, and upon (real or fake) power-on. Can be changed at any time through keypad commands ```20``` (off), ```21``` (on), ```22``` (Auto 30secs) or ```23``` (Auto 60secs).

##### &#9193; Time-cycling interval

In this decorative mode the device cycles through a list of pre-programmed, movie-accurate *destination* and *last time departed* times. This mode is enabled by setting the "Time-cycling Interval" to anything but "off". The device will cycle through named list every 5th, 10th, 15th, 30th or 60th minute, and thereby change the displays. Set the interval to "off" to disable. See [here](#time-cycling)

##### &#9193; Animate time-cycling

If this option is checked, cycling times will be animated imitating entering a new destination time. 

If this option is unchecked, times are simply switched without further ado.

##### &#9193; Skip time travel display disruption

If this is checked, the TCD will not show the display disruption animation during a time travel.

##### &#9193; Date entry animation like in part 3

If this is checked, the TCD will show a different animation upon entering a Destination time, as shown in part 3 of the Series. _This option is not available in the A-Car version._

##### &#9193; Play time travel sounds

If other props are connected, they might bring their own time travel sound effects. In this case, you can uncheck this to disable the Time Circuit's own time travel sounds. 

This option only covers sounds played during time travel, not other sound effects.

##### &#9193; Play default sound-on-the-hour

If this option is checked, the TCD will play a sound on every hour. You will hear Hill Valley's clock tower bell and Marty McFly telling you the time.

Note that if there is either ["hour.mp3" or a "hour-xx.mp3"](#additional-custom-sounds) file for the current hour present on the SD card, this sound will be played instead of the default.

##### &#9193; Alarm base is real present time

Selects whether the alarm and sound-on-the-hour are based on real, actual local present time or *present time* as displayed (eg after a time travel).

_The night mode schedules and the Reminder are always based on actual present time._

##### &#9193; 24-hour clock mode

Selects 24-hour clock mode, ie hours go from 0 to 23, "AM" and "PM" are permanently dark.

#### <ins>Time Synchronization settings</ins>

##### &#9193; Time zone

The time zone of the place where the device is operated in POSIX format. Needs to be set in order to use NTP or GPS, and for DST (daylight saving). Defaults to UTC0. See [here](#appendix-b-time-zones), [here&#10548;](https://github.com/nayarsystems/posix_tz_db/blob/master/zones.csv) or [here](https://tz.out-a-ti.me) for a list of valid time zones.

##### &#9193; NTP Server

Name of your preferred NTP (network time protocol) server for time synchronization. Leave this empty to disable NTP.

##### &#9193; Use GPS time

If this option is checked (which it is by default), the TCD uses GPS as a source for authoritative time, in the same way like NTP.

The issue with GPS time and the reason for this option is so-called "GPS week rollovers". Traditional GPS (L1/L1A aka "Legacy C/A") encodes time information in shape of "number of weeks" since 1980, and uses a 10 bit counter. As a result, this counter overflows every 1024 weeks, which is every about 19 years. The receivers' firmware is usually pretty dumb and only works for one of those periods (and it appears manufacturers prohibit longer periods of operation on purpose by refusing manual date/time feeds beyond the next rollover). The TCD firmware knows some measures to overcome a rollover if it were handled smartly, but I have no idea what the receivers actually are going to do (report time 19 years in the past? Report any time in the past, perhaps depending on the firmware's week-offset? Stop working at all?), and I cannot test this in any way. In case the TCD syncs to wrong time as a result of the receiver being unable to properly cope with a roll-over, you can disable usage of GPS time information using this option. The next rollover is due in 2038, but trouble might come earlier, if the receiver firmware uses a week-offset to shift its working period across a rollover. According to the datasheets of some MTK3333 receivers, these might stop reporting correct time already in 2034. More modern GPS signals (L1C, L2C, L5) overcome this issue by using 13 bits for weeks, but given those signals are either not yet broadcast by many satellites and/or considered pre-operational as of this writing (2026), and rollout plans reach into the early 2030s, receivers supporting them are scarce and unreasonably expensive.

#### <ins>World Clock mode</ins>

##### &#9193; Time zone for Destination Time display

The time zone for the red display in [World Clock mode](#world-clock-mode). Default: unset. Needs to be in [Posix](https://tz.out-a-ti.me) format.

##### &#9193; Time zone for Last Time Dep. display

The time zone for the yellow display in [World Clock mode](#world-clock-mode). Default: unset. Needs to be in [Posix](https://tz.out-a-ti.me) format.

##### &#9193; City/location name

For each World Clock time zone, a city or location name can be configured. For example "SYDNEY" or "LORD HOWE". See immediately below for how it is used.

##### &#9193; Show names permanently

If _City/Location names_ are short enough to fit next to time:
- If this option is checked, the location name will be shown permanently instead of the date
- If this option is unchecked, the location name will be shown every few seconds, for a few seconds, instead of the date.

If _City/Location names_ are too long to fit next to time, this option is ignored and the location name will be shown every few seconds, for a few seconds, instead of date and time.

#### <ins>Alarm settings</ins>

##### &#9193; Alarm mode

This allows choosing between standard/legacy or extended [alarm function](#alarm). 

"Legacy" is a simple, one-time alarm signal. All alarm-related settings below are for "Extended" only.

##### &#9193; Snooze

This enables the Snooze function. If enabled, (briefly) pressing ```ENTER``` while the alarm sounds activates a repeated alarm after a selectable time period ("Snooze Time"). 

##### &#9193; Snooze Time

This selects the time period after which an alarm is repeated when Snooze is active.

##### &#9193; Auto Snooze

If this is checked, and the user does not react to an alarm by either pressing or holding ```ENTER``` within 2 minutes, the alarm is silenced and repeated after the selected "Snooze Time".

##### &#9193; Loop user-provided Alarm sound

The alarm plays for 2 minutes. If the alarm sound is [substituted](#sound-substitution) by a user-provided mp3 file, this option allows looping it, which is useful if it is considerably shorter than two minutes. Note that you can only snooze or disable the alarm using the ```ENTER``` button while the alarm sounds. Afterwards the alarm can only be stopped through keypad command ```12``` if snooze is enabled.

#### <ins>Night-mode</ins>

##### &#9193; Destination time off in night mode

Selects whether the *destination time* display is dimmed or switched off in night mode.

##### &#9193; Present time off in night mode

Selects whether the *present time* display is dimmed or switched off in night mode.

##### &#9193; Last time dep. off in night mode

Selects whether the *last time departed* display is dimmed or switched off in night mode.

##### &#9193; Schedule

Selects a schedule for night-mode. See [here](#night-mode)

##### &#9193; Daily night-mode start hour

If "Daily" is chosen in the "Schedule"-drop-down, enter night-mode start hour here.

##### &#9193; Daily night-mode end hour

If "Daily" is chosen in the "Schedule"-drop-down, enter night-mode end hour here.

##### &#9193; Use light sensor

Select whether to use a light sensor's data to enable night-mode. See [here](#night-mode).

##### &#9193; Light (lux) threshold

If the light sensor reports a number of lux below or equal to this value, night-mode is activated. See [here](#night-mode).

#### <ins>Other settings</ins>

##### &#9193; Save secondary settings on SD

If this is checked, secondary settings (brightness, time cycling interval, volume, alarm, reminder, car mode state, exhibition mode data and state, time travel state and data) are stored on the SD card (if one is present). This helps to minimize write operations to the internal flash memory and to prolong the lifetime of your TCD. See [Flash Wear](#flash-wear).

Apart from Flash Wear, there is another reason for using an SD card for settings: Writing data to internal flash memory can cause delays of up to 1.5 seconds, which interrupt sound playback and have other undesired effects. The TCD needs to save data from time to time, so for a smooth experience without unexpected and unwanted delays, please use an SD card and check this option.

It is safe to have this option checked even with no SD card present.

If you want copy settings from one SD card to another, do as follows:
- With the old SD card still in the slot, enter the Config Portal, turn off _Save secondary settings on SD_, and click "SAVE".
- After the TCD has rebooted, power it down, and swap the SD card for your new one.
- Power-up the TCD, enter the Config Portal, re-enable _Save secondary settings on SD_, and click "SAVE".

This procedure ensures that all your settings are copied from the old to the new SD card.

##### &#9193; Make time travel persistent

See [here](#persistent--non-persistent-time-travels). For this option to take effect, it is required that the _Save secondary settings on SD_ is checked as well, and an SD card is present. Time travel data is only ever stored on SD, never in internal flash memory.

#### <ins>Hardware settings</ins>

##### &#9193; Swap red and yellow displays like B-Car

The B-Car had the red and yellow displays flipped; the red one was mounted at the bottom, the yellow one on top. This version of the TCD is briefly shown in part 1 when Doc opens the frozen Delorean's door after Einstein had returned. If you assemble your TCD in that very way, check this option to swap the ways of operation for the red and yellow displays so that the yellow display will act as the _Destination Time_ display, the red one as _Last Time Departed_. _This option is only available in the A-Car version._

##### &#9193; Reverse AM/PM like in parts 2/3

If this is checked, the TCD will reverse the AM and PM lights, as seen in parts 2 and 3 of the Series. This is under "hardware settings" as it requires attaching the labels in a different manner.

---

### Settings for Peripherals

##### &#9193; Use fake power switch

Check this if you want to use a fake power switch. See [here](#fake-power-switch).
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

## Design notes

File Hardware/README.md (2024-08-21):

# PCB Revision History
## Control Board
v1.4.5 (8/1/24)
- Consolodated inputs/outputs into 8 pin screw connector
- Added label for TFC connections
- Added ground to audio line output screw connector
- Moved reset and io0 buttons to back of the board
- Added ability to switch between line out and speaker audio

v1.4 (7/1/24)
- Added dedicated audio line out
- Switched to original style TRW enter button
- Added on-board ESP32 module
- Added 3.3V power supply
- Added serial USB chip with ESD filtering
- Added micro-USB connector to back of board
- Moved RTC battery to rear of the PCB for ease of changing
- Changed volume pot to rear facing
- Moved micro-SD card to the rear of the board, and swtiched to a flip out holder
- 3d printed lens holder is now screwed to the PCB
- Changed Speedo and I2C to 2.54mm screw connectors
- Removed PCF2129AT and extra caps footprints
- Changed to TRW style mounting holes (3)

v1.3 (7/1/22)
- Added switch for lens LEDs
- Added header for TT In (GPIO 27)
- Added reverse polarity protection for power connectors
- Split resistors for keypad LEDs to make it so green LED can be brighter
- Added labels for PWR Trigger, TT Out, TT In, and Speedo

v1.2 (6/1/21)
- Fixed footprint for enter button
- Added 5.0V/3.3V level shifter, and ESD protection for I2C lines. This will prevent random glitches in I2C, and keep the ESP32 happy.
- Added footprint for PCF2129AT RTC in case DS3231 becomes unavailable or too expensive. Both should not be populated at the same time.
- Changed volume to connect to GPIO32 on ESP32 instead of amp GAIN_SLOT
- Updated schematic to include some notes

[OctoPart BOM](https://octopart.com/bom-tool/zCnlEeUa)

## Time Circuits Display
v1.31
- Made mounting holes slightly larger
- Moved some traces so they are not as close to pins

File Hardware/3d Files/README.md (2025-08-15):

# 3d Printing
### What to print for the most recent version of the TCD:
#### Keypad:
- _keypad_body_v3-4_hole_mount_ - print with the face down. [eSUN PLA PRO in Olive Green](https://amzn.to/3BTbkVD) is very very close to the color of the actual TRW keypad housing.
- _keypad_body_v3_surround_ - later glued on to the face of _keypad_body_v3_
- _keypad_body_v3_clear_ - later glued on to the face of _keypad_body_v3_. Use a 0.2 nozzle if available.
- _keypad_bezel-v3_ - print in white with the key side up, and supports. Ironing in your slicer can be used to smooth out the top surface. The example in pictures is not sanded/painted at all.

#### Enclosures:
Print all in a silver or grey color
- _enclosure_one_piece-v4.1_
- _dest_time_enclosure-v3_
- _pres_time_enclosure-v3_
- _last_time_enclosure-v3_ - print face down with supports (for the speaker mounting tabs)
- _display_faceplate_ (x3) - print face down so the face is as smooth as possible. You will need 3 of these.

_circuitsetup_time_circuits_display.3mf_ - multi plate file for Bambu Labs printers.

# Revision History
### 8/1/24
#### Keypad v3
- _keypad_body-v3_ - Revised keypad completely to fit latest control board (v1.4). Fits the bottom angled profile of the original. Is now printed in 3 pieces (_keypad_body_v3_surround_ & _keypad_body_v3_clear_) so the body can be printed face down & without supports.
- _keypad_bezel-v3_ - Is now more true to the original size
- _keypad_lens_mount-v2-1_ & _keypad_enter_spacer_ - Completely new and come installed on the control board (v1.4) to hold the keypad lenses and space the new enter button properly

### 11/13/23
Update to the enclosures to make them even more true to the original C car TCD, which is now in the restored A car. Inner enclosures only changed the screw hole positions slightly

### 3/16/22
Update to the enclosures to make them more true to the original C car TCD, which is now in the restored A car.

#### Outer Enclosure v3:
- Corrected top dimensions
- Made bends on left (96 degrees) and right (104 degrees) sides angled forward instead of 90 degrees to the top edge
- Adjusted profile of the left and right front edges
- Adjusted angle of bends of left (91.3 degrees) and right (94.2 degrees) sides in relation to the top
- Added proper curves to right back side
- Added rear screw dash mounting holes (4 on right, 2 on left)
- Adjusted display mounting holes to match original (which are not evenly spaced)
- Increased display mounting hole size to 3mm

#### Display Enclosures v2:
- Made display enclosures resemble LMB boxes a bit more 
- Rounded top left/right edges, and face bottom edge
- Squared bottom left/right edges, and top face edge
- Increased space around segment displays by 0.2mm
- Matched mounting holes to enclosure_one_piece-v3
- Created separate enclosures for Destination Time & Present Time (since mounting holes are now different between the two)

### 9/24/21
#### Keypad v2:
- updated to more closely match TRW keypad
- moved side buttons and keypad down slightly
- moved the slope of the top and bottom down, so the top is more flat when compared to the bottom
- flattened the 'clear' lettering a bit
- removed lip on the inside of the lens/button cutout
- lens holder: made lens holes larger, body slimmer, and easier to snap into body

### 9/18/21
#### Outer Enclosure v2:
- Increased rear opening from about 9.75 to 10.25" (width of a Delorean upper center console)
- depth increased a tiny bit - left side 3", right side 4"
- Height increased from 4.5" to 5"
- Angles on left and right side going front to back are now about even
- Bends on sides moved forward a bit
- Rounded the corner on the lower left side
- Notch for keypad on left side, and reformed in the front

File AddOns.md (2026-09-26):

# DIY additions for the Time Circuits Display

- [Rotary Encoder](#rotary-encoder)
- [Temperature/humidity sensor](#temperaturehumidity-sensor)
- [Light sensor](#light-sensor)
- [Speedometer](#speedometer)
- [GPS receiver](#gps-receiver)
- [Other props](#other-props)
- Timing for [MQTT-capable props](#synchronized-time-travel-through-hamqtt)

## Rotary Encoder

A rotary encoder is a sensor that converts the physical rotation or position of a shaft into electrical signals or, simply put, a turnable knob. The TCD supports rotary encoders for adjusting speed and/or audio volume.

The firmware currently supports the 
- [Adafruit 4991](https://www.adafruit.com/product/4991)/[5880](https://www.adafruit.com/product/5880),
- [DuPPA I2CEncoder 2.1](https://www.duppa.net/shop/i2cencoder-v2-1/) (or [here](https://www.elecrow.com/i2cencoder-v2-1.html)) and
- [DFRobot Gravity 360](https://www.dfrobot.com/product-2575.html)

i2c rotary encoders. For the Adafruit and the DuPPa, I recommend buying the PCBs without an encoder and soldering on a Bourns PEC11R-42xxy-S0024.

Up to two rotary encoders can be connected, one for speed, one for volume.

### Hardware Configuration

In order to use an encoder for speed or volume, it needs to be configured as follows:

  <table>
  <tr><td></td><td>Ada4991/5880</td><td>DFRobot</td><td>DuPPA</td></tr>
  <tr><td>Speed</td><td>Default</td><td>SW1=0,SW2=0</td><td>A0 closed</td></tr>
  <tr><td>Volume</td><td>A0 closed</td><td>SW1=0,SW2=1</td><td>A0,A1 closed</td></tr>
  </table>

For DuPPA: RGB-encoders not supported.

Here is how they look configured for speed (the purple spots are solder joints):

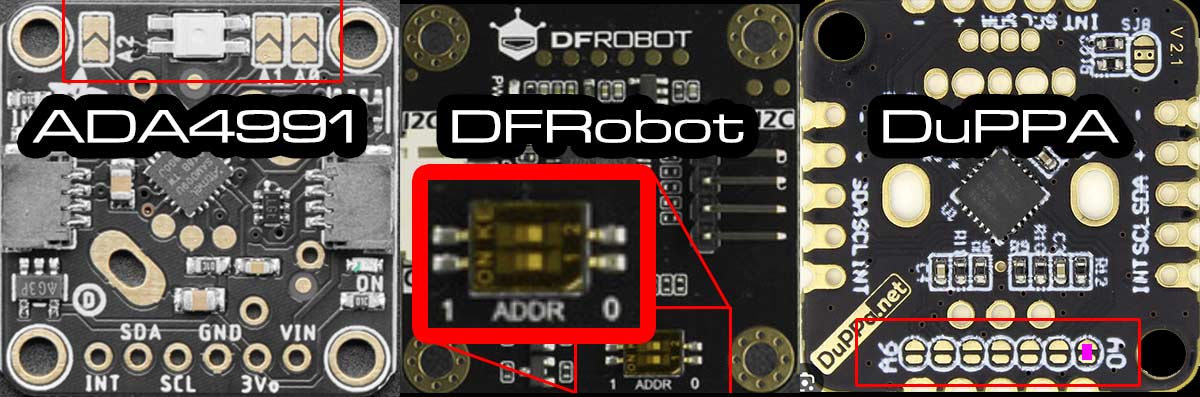
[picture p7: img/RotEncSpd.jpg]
RotEncSpd


Here is the configuration for volume:

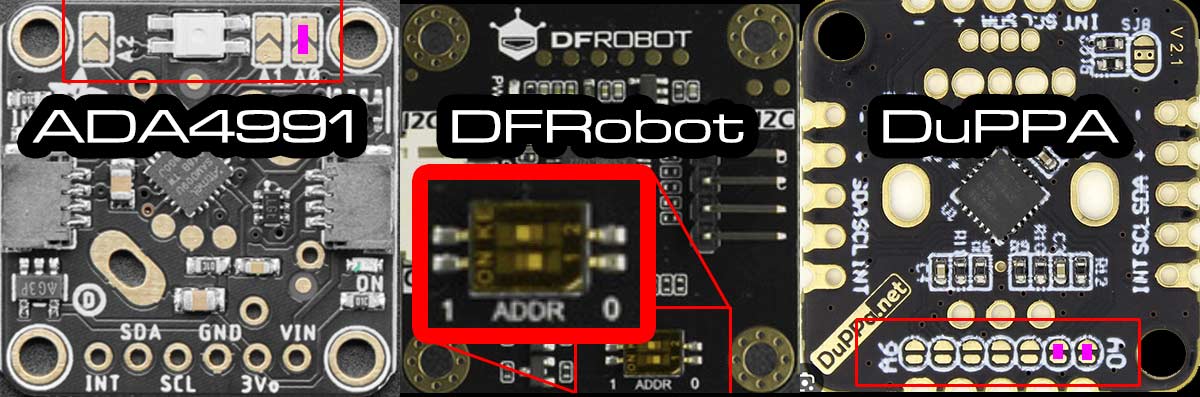
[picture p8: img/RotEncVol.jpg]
RotEncVol


For wiring information, see [here](#i2c-peripheral-wiring). 

## Temperature/humidity sensor

The firmware supports connecting a temperature/humidity sensor for "room condition mode" and for displaying ambient temperature on a speedo display while idle.

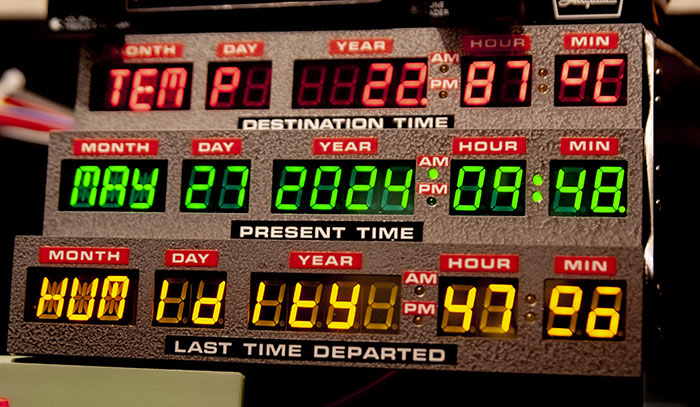
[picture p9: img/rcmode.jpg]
RC mode
|  |
|:--:|
| *RC mode* |

The following sensor types are supported: 
- [MCP9808](https://www.adafruit.com/product/1782) (address 0x18 - non-default),
- [BMx280](https://www.adafruit.com/product/2652) (0x77),
- [SI7021](https://www.adafruit.com/product/3251),
- [SHT40](https://www.adafruit.com/product/4885) (0x44),
- [SHT45](https://www.adafruit.com/product/5665) (0x44),
- [TMP117](https://www.adafruit.com/product/4821) (0x49),
- [AHT20/AM2315C](https://www.adafruit.com/product/4566),
- [HTU31D](https://www.adafruit.com/product/4832) (0x41 - non-default),
- [MS8607](https://www.adafruit.com/product/4716)
- [HDC302x](https://www.adafruit.com/product/5989) (0x45 - non-default)

>The BMP280 (unlike BME280), MCP9808 and TMP117 work as pure temperature sensors, the others for temperature and humidity.

All of those are readily available on breakout boards from Adafruit or Seeed (Grove); the links in above list lead to tested example products. Only one temperature/humidity sensor can be used at the same time.

For wiring information, see [here](#i2c-peripheral-wiring).

>Note: You cannot connect the sensor chip directly to the TCD control board; most sensors need at least a voltage converter/level-shifter. It is recommended to use Adafruit or Seeed breakouts, which all allow connecting named sensors to the 5V the TCD board operates on.

## Light sensor

The firmware supports connecting a light sensor for night-mode switching.

The following sensor types/models are supported:

- [TSL2591](https://www.adafruit.com/product/1980),
- [TSL2651](https://www.seeedstudio.com/Grove-Digital-Light-Sensor-TSL2561.html),
- [BH1750](https://www.adafruit.com/product/4681),
- [VEML7700](https://www.adafruit.com/product/4162),
- VEML6030 [0x48 - non-default],
- [LTR303/LTR329](https://www.adafruit.com/product/5610)

>The VEML7700 can only be connected if no CircuitSetup Speedo or third-party GPS receiver is connected at the same time; the VEML6030 needs its address to be set to  0x48 if a CircuitSetup Speedo or third party GPS receiver is present at the same time. 

Almost all these sensor types are readily available on breakout boards from Adafruit or Seeed (Grove); the links in above list lead to tested example products. 

For wiring information, see [here](#i2c-peripheral-wiring).

>Note: You cannot connect the sensor chip directly to the TCD control board; most sensors need at least a voltage converter/level-shifter.  It is recommended to use Adafruit or Seeed breakouts, which all allow connecting named sensors to the 5V the TCD board operates on.

## Speedometer

Despite CircuitSetup offering a really good and [screen-accurate speedo](https://circuitsetup.us/product/delorean-time-machine-speedometer-kit/), you might want to make your own.

| Watch the video (https://youtu.be/opAZugb_W1Q) |
|:--:|
| Click to watch the video |

The speedo shown in this video is based on a fairly well-designed stand-alone replica I purchased on ebay. I removed the electronics inside and wired the LED segments to an Adafruit i2c backpack (from the Adafruit 878 product) and connected it to the TCD.

What you need is a box, the LED segment displays and a HT16K33-based PCB that allows accessing the LED displays via i2c (address 0x70). There are various readily available LED segment displays with suitable i2c break-outs from Adafruit and Seeed (Grove) that can be used as a basis: 

- Adafruit [878](https://www.adafruit.com/product/878)/[5599](https://www.adafruit.com/product/5599),
- Adafruit [1270](https://www.adafruit.com/product/1270),
- Adafruit [1911](https://www.adafruit.com/product/1911),
- Grove 0.54" 14-segment [2-digit](https://www.seeedstudio.com/Grove-0-54-Red-Dual-Alphanumeric-Display-p-4031.html)
- Grove [4-digit](https://www.seeedstudio.com/Grove-0-54-Red-Quad-Alphanumeric-Display-p-4032.html).

The product numbers vary with color, the numbers here are the red ones.

For wiring information, please see [here](#i2c-peripheral-wiring).

#### Software setup

The type of display needs to be configured in the Config Portal's _Speedo display type_ drop-down widget. 

For DIY speedos, there are two special options in the Speedo Display Type drop-down: *Ada 1911 (left tube)* and *Ada 878 (left tube)*. These two can be used if you connect only one 2-digit-tube to the respective Adafruit i2c backpack, as I did in case of my speedo replica as well as my [Wall Clock](https://github.com/realA10001986/Time-Circuits-Display/blob/main/WALLCLOCK.md).

## GPS receiver

The CircuitSetup original [speedo](https://circuitsetup.us/product/delorean-time-machine-speedometer-pcb) has a built-in GPS receiver, but the firmware also supports alternatives such as the 
- Adafruit Mini GPS PA1010D (product id [4415](https://www.adafruit.com/product/4415)) or the
- Pimoroni P1010D GPS Breakout ([PIM525](https://shop.pimoroni.com/products/pa1010d-gps-breakout?variant=32257258881107))
  
or any other MT(K)3333-based GPS receiver, connected through i2c (address 0x10). Note that the supply and bus voltage must be 5V.

The GPS receiver can be used as a source of authoritative time (like NTP) and speed of movement.

For wiring information, see [here](#i2c-peripheral-wiring).

Note that the Adafruit and Pimoroni breakout boards do not have a proper GPS antenna and require excellent reception conditions; thick windows might already block reception. The CircuitSetup speedo has an external antenna and works far better in cars and indoors (close to windows).

## I2C peripheral wiring

All i2c peripherals described above are to be wired as follows:

On the TCD control board, there are three breakouts named "I2C", at least one of which has a header soldered on; it does not matter which one you use to connect your sensors/speedo/GPS/rotary encoders. On Control Boards version 4, there are screw terminals for the other two i2c connectors; for older boards, I recommend to solder on [XH](https://www.amazon.com/s?k=jst+xh) 4-pin headers to the other two i2c breakouts as well (like in the second picture). When you order a CircuitSetup Speedo, they will include such headers if you request them. Do not solder wires directly to the board!

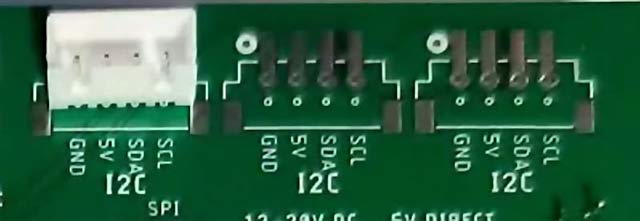
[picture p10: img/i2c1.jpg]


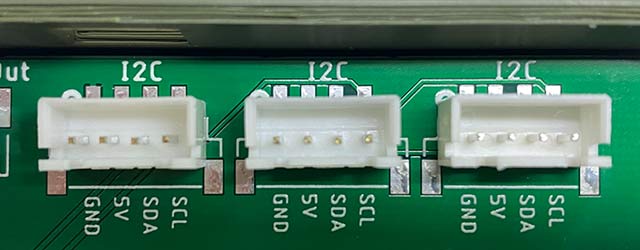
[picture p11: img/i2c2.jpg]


On most peripherals the pins are named as follows, and need to be connected to the corresponding pins on the control board:

<table>
    <tr>
     <td align="center">Peripheral PCB</td><td align="center">TCD control board</td>
    </tr>    
    <tr>
     <td align="center">GND or "-"</td>
     <td align="center">GND</td>
    </tr>
    <tr>
     <td align="center">VIN or 5V or "+"</a></td>
     <td align="center">5V</td>
    </tr>
    <tr>
     <td align="center">SDA<br>(SDI on BME280)</td>
     <td align="center">SDA</td>
    </tr>
    <tr>
     <td align="center">SCL<br>(SCK on BME280)</td>
     <td align="center">SCL</td>
    </tr>
</table>

For longer cables, ie >50cm (>20in), I recommend using a shielded twisted pair (S/FTP) cable, and to connect it as follows:

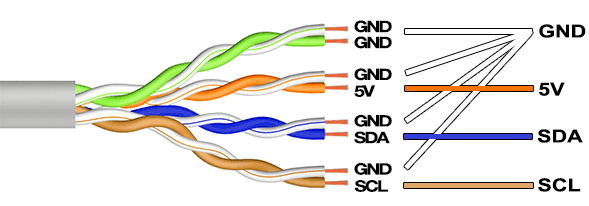
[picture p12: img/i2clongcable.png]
i2clongcable


In case of a shielded cable, connected the shield to GND on the TCD's end.

If you experience sound stutter or stalled displays, the reason is in nearly all cases a problem with i2c cabling. SDA and SCL should be separated as far as possible to avoid cross-talk. Also, don't put the i2c cable too close to other cables.

>Important: The TCD control board delivers and drives the i2c bus on 5V. Most sensors/GPS receivers operate on 3.3V. Therefore, you cannot connect the chips directly to the TCD control board without a level-shifter. This goes for the power supply as well as the i2c bus signals (SDA, SCL). I only use readily available sensor breakout boards that include level-shifters.

#### Multiple i2c devices

If going by the book, multiple i2c devices should be daisy chained; however, I had sensors, speedo and GPS receivers run in parallel without issues for months.

Note that you can only use one per device type (temperature/humidity sensor, light sensor, GPS receiver, Speedo display) at a time. As regards rotary encoders, one for speed and one for volume can be connected.

To avoid running out of i2c connectors, and to reduce the cable chaos, I designed a small PCB that acts as a i2c and power splitter:

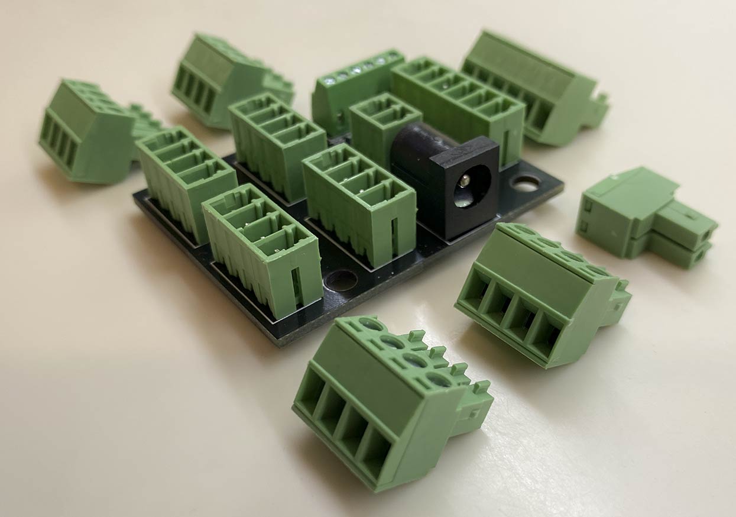
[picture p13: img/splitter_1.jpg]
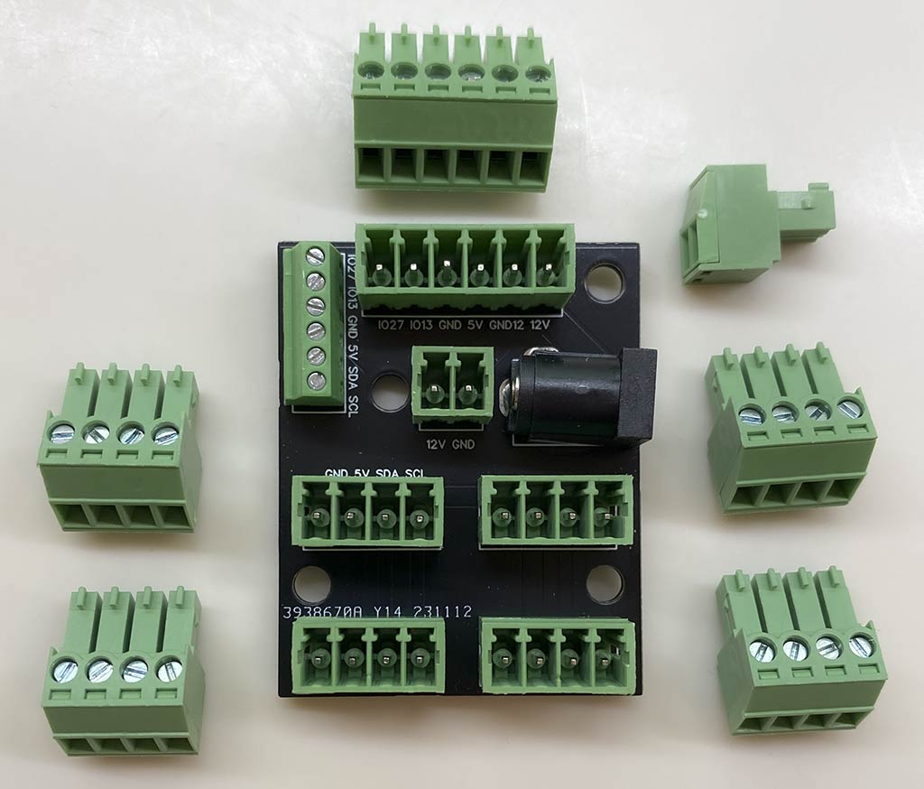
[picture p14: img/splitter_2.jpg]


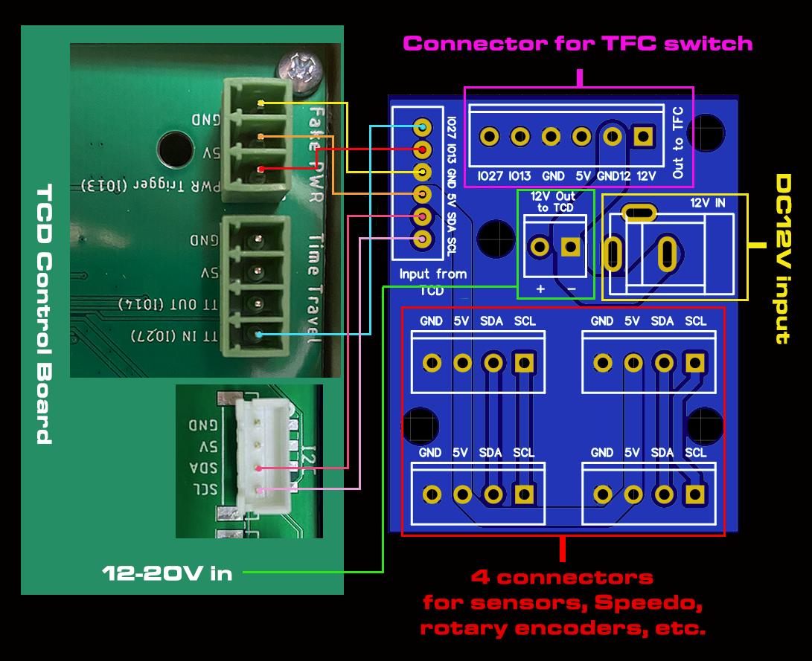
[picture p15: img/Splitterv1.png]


- 12V in: 12V input for the TCD and the TFC switch, using a 5.5/2.1mm standard DC power plug.
- Input from TCD: Connect those to the TCD control board as indicated above
- 12V output: 12V power for the TCD
- four i2c screw connctors for sensors, rotary encoders, Speedo, etc
- TFC drive switch connector

Production files are in the [DIY/splitter](https://github.com/realA10001986/Time-Circuits-Display/tree/main/DIY/Splitter) folder.

#### i2c addresses

i2c devices have "addresses". Most sensors either only support one i2c address, or are recognized by the firmware (only) by their default address. For those, nothing must be done in order to use them with the Time Circuits Display.

Notable exceptions are the TMP117 and HTU31D sensors: Their address needs to changed in order to be recognized by the firmware. On the Adafruit breakouts, this is done by connecting two solder pads on the back side of the PCB:

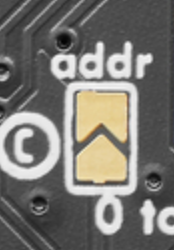
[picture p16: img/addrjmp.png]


This image shows the HTU31D PCB's back side. Connect (shorten) those two pads in order to change the address. It looks similar on the TMP117.

For Rotary Encoders, see [here](#hardware-configuration).

## Other props

The TCD has a TT-OUT pin (marked "TT OUT (IO14)" or "IO14") which can be used to
- signal a time travel,
- signal alarm,
- or manually switching on/off connected props.

Signaling is done by setting this pin HIGH (2.7-3.3V).

For connecting CircuitSetup/A10001986 props, see the prop's documentation ([Flux capacitor](https://github.com/CircuitSetup/Flux-Capacitor#connecting-a-tcd-by-wire), [SID](https://github.com/CircuitSetup/SID#connecting-a-tcd-by-wire), [Dash Gauges](https://github.com/CircuitSetup/Dash-Gauges/blob/main/hardware/README.md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), [VSR](https://github.com/realA10001986/VSR#connecting-a-tcd-by-wire)).

In order to connect props that can sense HIGH/LOW levels (and don't use the TT OUT pin for power supply), you need two wires for connecting the TCD: TT-OUT and GND, which need to be connected to the prop:

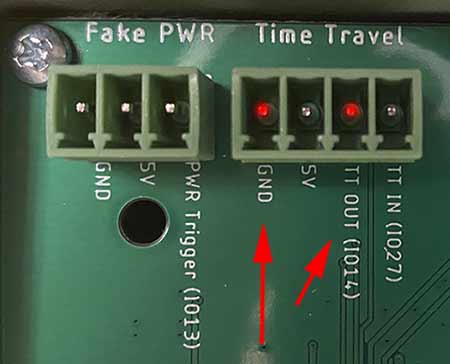
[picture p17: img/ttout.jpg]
ttout
|  |
|:--:|
| TT_OUT/IO14 on board version 1.3 |

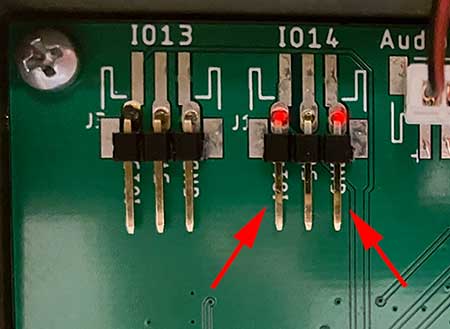
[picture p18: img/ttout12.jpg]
ttout
|  |
|:--:|
| IO14 on board version 1.2 |

Flux bands, lights and the likes need to be connected through a relay. When using a standard "Arduino Relay Module", connect GND to GND, 5V to 5V and "S" (or "IN") to TT OUT. 

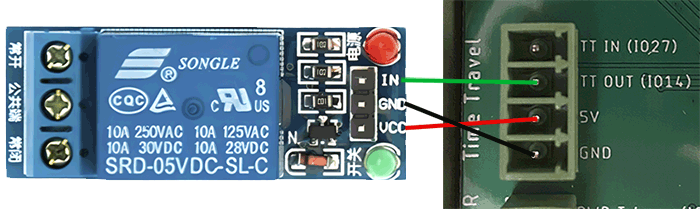
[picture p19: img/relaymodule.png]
RelayModule


### Timing

Here's the timing diagram for a time travel signal:

1) Option **_Signal without 5s lead_** unchecked

If a time travel sequence is started by button, the TCD itself is taking care of "acceleration", and can therefore calculate in advance when the temporal displacement sequence will start and notify other props 5 seconds ahead:

```
|<-------------- acceleration ------------>|<-Temporal displacement->|<--speedo deceleration--->|
0....10....20....................xx....87..88------------------------88...87....................0
                                           |  (Display disruption)   |
                                           |                         |
                                      TT starts                      Reentry phase
                                           |                         |
             |<---------ETTO lead--------->|                         |
             |                                                       |
             |                                                       |
             |                                                       |
             TT-OUT: LOW->HIGH                                       TT-OUT: HIGH->LOW
 ```

"ETTO lead", ie the lead time between TT-OUT going HIGH and the actual start of a temporal displacement, is fixed and always 5000ms (5 seconds). In this window of time, the prop can play its pre-time-travel (warm-up/acceleration/etc) sequence. The sequence inside the temporal displacement follows after that lead time, and as soon as TT-OUT goes LOW, re-entry into the destination time takes place.

This fixed lead time becomes a problem if using GPS speed, a rotary encoder for speed, or a Futaba remote to control speed: In that case, a time travel is automatically triggered upon hitting 88mph. In this scenario, the TCD cannot know in advance if or when a speed of 88mph is actually reached, and therefore not inform other props 5 seconds ahead. As a result, there will be a delay of 5 seconds from when the TCD's GPS/Rotary Encoder/Futaba Remote-induced speed hits 88mph until the temporal displacement sequence actually starts:

```
|<--------- random speedo action --------->|<- waiting, waiting...........|<-Temporal displacement->|<--speedo deceleration-->|
0....20....40.....87......80.....20....81..88******************************-------------------------88...87...................0
                                                                          |  (Display disruption)   |
                                                                          |                         |
                                                                     TT starts                      Reentry phase
                                                                          |                         |
                                           |<----------ETTO lead--------->|                         |
                                           |                                                        |
                                           |                                                        |
                                           |                                                        |
                                           TT-OUT: LOW->HIGH                                        TT-OUT: HIGH->LOW
 ```

**** marks the certainly unwanted 5 seconds "stall". 

2) Option **_Signal without 5s lead_** checked

```
|<-- acceleration/random speed changes --->|<-Temporal displacement->|<--speedo deceleration--->|
0....xx....xx.......xx......xx...xx....xx..88------------------------88...87....................0
                                           |  (Display disruption)   |
                                           |                         |
                                      TT starts                      Reentry phase
                                           |                         |
                                           |                         |
                                           |                         |
                                           |                         |
                                           |                         |
                                           TT-OUT: LOW->HIGH         TT-OUT: HIGH->LOW
 ```

In this case, there is no lead. TT-OUT goes high when the temporal displacement sequence starts.

Conclusion: 

If you are not planning on using GPS speed, a Rotary Encoder for speed or a Futaba remote to control speed on your TCD, you can use the normal 5-second-lead technique if your prop is designed to play some kind of pre-time-travel sequence (acceleration, warm-up, etc). 

Checking **_Signal without 5s lead_** is required if you are using GPS speed, a Rotary Encoder for speed or a Futaba remote to control speed on your TCD, in order to avoid a "stall" when hitting 88mph. The downside is that other props do not get time to play any kind of "acceleration" sequence.

If you connect original CircuitSetup/A10001986 props by wire, make sure you check/uncheck the option _TCD signals Time Travel without 5s lead_ in the prop's Config Portal accordingly.

## Synchronized time travel through HA/MQTT

Time Travel timing:

1) Option **_Enhanced Time Travel notification_** unchecked

If a time travel sequence is started by button, the TCD itself is taking care of "acceleration", and can therefore calculate in advance when the temporal displacement sequence will start and notify other props 5 seconds ahead using the simple TIMETRAVEL message:

```
|<-------------- acceleration ------------>|<-Temporal displacement->|<--speedo deceleration--->|
0....10....20....................xx....87..88------------------------88...87....................0
                                           |  (Display disruption)   |
                                           |                         |
                                      TT starts                      Reentry phase
                                           |                         |
             |<---------ETTO lead--------->|                         |
             |                                                       |
             |                                                       |
             |                                                       |
             MQTT: TIMETRAVEL                                        MQTT: REENTRY
 ```

"ETTO lead", ie the lead time between dispatch of the "TIMETRAVEL" message and the actual start of a temporal displacement, is fixed and always 5000ms (5 seconds). In this window of time, the prop can play its pre-time-travel (warm-up/acceleration/etc) sequence. The sequence inside the temporal displacement follows after that lead time, and as soon as "REENTRY" is sent, re-entry into the destination time takes place.

This fixed lead time becomes a problem if using GPS speed, a rotary encoder for speed, or a Futaba remote to control speed: In that case, a time travel is automatically triggered upon hitting 88mph. In this scenario, the TCD cannot know in advance if or when a speed of 88mph is actually reached, and therefore not inform other props 5 seconds ahead. As a result, there will be a delay of 5 seconds from when the TCD's GPS/Rotary Encoder/Futaba Remote-induced speed hits 88mph until the temporal displacement sequence actually starts:

```
|<--------- random speedo action --------->|<- waiting, waiting...........|<-Temporal displacement->|<--speedo deceleration-->|
0....10....30....20.....60.......40....81..88******************************-------------------------88...87...................0
                                                                          |  (Display disruption)   |
                                                                          |                         |
                                                                     TT starts                      Reentry phase
                                                                          |                         |
                                           |<----------ETTO lead--------->|                         |
                                           |           (5000ms)                                     |
                                           |                                                        |
                                           |                                                        |
                                           MQTT: TIMETRAVEL                                         MQTT: REENTRY
 ```

**** marks the certainly unwanted 5 seconds "stall".

2) Option **_Enhanced Time Travel notification_** checked

If a time travel sequence is started by button, the situation is as above: The TCD itself takes care of "acceleration", calculates in advance when the temporal displacement sequence will start and notifies other props 5 seconds ahead. However, by using the enhanced TIMETRAVEL message, the lead time becomes variable. The enhanced message enables the TCD to tell other props when exactly the temporal displacement is expected to start:

```
|<------------- acceleration ------------->|<-Temporal displacement->|<--speedo deceleration--->|
0....10....20....................xx....87..88------------------------88...87....................0
                                           |  (Display disruption)   |
                                           |                         |
                                      TT starts                      Reentry phase
                                           |                         |
             |<---------ETTO lead--------->|                         |
             |           (5000ms)                                    |
             |                                                       |
             |                                                       |
             MQTT: TIMETRAVEL_5000_yyyy                              MQTT: REENTRY
 ```

And here the GPS speed/rotary encoder/Futaba remote control scenario:

```
|<--------- random speedo action --------->|<-Temporal displacement->|<--speedo deceleration--->|
0....20....10.......45......87......70.....88------------------------88...87....................0
                                           |  (Display disruption)   |
                                           |                         |
                                      TT starts                      Reentry phase
                                           |                         |
                                           |                         |
                                           |                         |
                                           |                         |
                                           |                         MQTT: REENTRY
                                           MQTT: TIMETRAVEL_0000_yyyy
 ```

Note that there is no stall: The props receive proper info on when the temporal displacement starts - in this case immediately (0ms).

Conclusion: 

If you are not planning on using GPS speed, a rotary encoder for speed or a Futaba remote to control speed on your TCD, you can leave **_Enhanced Time Travel notification_**  unchecked and thereby have the TCD send out the simple TIMETRAVEL message. 

Otherwise you need to check **_Enhanced Time Travel notification_** and teach your MQTT-aware prop how to interpret the enhanced TIMETRAVEL_xxxx_yyyy message. Both xxxx and yyyy denote milliseconds, always consist of four digits, and both can be zero. xxxx is the time until temporal displacement starts, yyyy is an approximation of the duration of the temporal displacement; however, don't use this value to schedule re-entry, instead wait for the REENTRY message to initiate your re-entry sequence.

---
_Text & images: (C) Thomas Winischhofer ("A10001986"). See LICENSE._ Source: https://github.com/CircuitSetup/Time-Circuits-Display

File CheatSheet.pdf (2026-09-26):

## Destination time programming

Set date and time | mmddyyyyhhMM
Set date / time only | mmddyyyy / hhMM
Reset display mode (disable 111-117) | 110
Toggle Room Condition mode (https://tcd.out-a-ti.me/#room-condition-mode-temperaturehumidity-sensor) | 111
Toggle World Clock mode (https://tcd.out-a-ti.me/#world-clock-mode) | 112
Toggle WC/RC hybrid mode | 113
Toggle geoloc. mode (https://tcd.out-a-ti.me/#geolocation-mode) (DD/DMS/DMD) | 114 / 115 / 116
Toggle “Minimal” mode | 117
Show weekday of present time date | 39
Disable / Enable beep (https://tcd.out-a-ti.me/#beep-on-the-second) sound | 20 / 21
Enable beep (https://tcd.out-a-ti.me/#beep-on-the-second) sound (30/60 seconds) | 22 / 23
Set relative beep volume level (0 - 3) | 30 - 33
Select volume level / Enable knob | 300 - 320 / 399
Alarm (https://tcd.out-a-ti.me/#how-to-set-up-the-alarm) : Set to hh:MM / Show / Stop | 11hhMM / 11 / 12
Timer (https://tcd.out-a-ti.me/#count-down-timer) : Set to MM minutes / Show | 44MM / 44
Timer (https://tcd.out-a-ti.me/#count-down-timer) : Delete timer | 440
Reminder (https://tcd.out-a-ti.me/#yearlymonthly-reminder) : Display reminder | 77 / 777
Reminder (https://tcd.out-a-ti.me/#yearlymonthly-reminder) : Program reminder | 77mmdd
Reminder (https://tcd.out-a-ti.me/#yearlymonthly-reminder) : Program reminder | 77mmddhhMM
Reminder (https://tcd.out-a-ti.me/#yearlymonthly-reminder) : Delete reminder | 770
Play “keyX.mp3” (X = 1 - 9) | 501 - 509
Send user-defined HA messages | 600 - 609
Set TT OUT (https://tcd.out-a-ti.me/#connecting-props-by-wire) to LOW / HIGH | 900 / 901
Disable / Enable Car Mode (https://tcd.out-a-ti.mee/#car-mode) | 990 / 991
Program & store Destination Time | 91mmddyyyyhhMM
Program & store Last Time Dep. | 92mmddyyyyhhMM
Restore stored dest./last dep. times | 998
Toggle Exhibition Mode (https://tcd.out-a-ti.me/#exhibition-mode) | 999
Program Time for Exhibition Mode (https://tcd.out-a-ti.me/#exhibition-mode) | 99mmddyyyyhhMM

## Time Circuits Display

A10001986

## Holding key for 2 seconds

1 Toggle Alarm (https://tcd.out-a-ti.me/#how-to-set-up-the-alarm) on/off | 2 Music Player (https://tcd.out-a-ti.me/#the-music-player) : Previous track | 3 Play "key3.mp3"
4 Toggle Night mode (https://tcd.out-a-ti.me/#night-mode) | 5 Music Player (https://tcd.out-a-ti.me/#the-music-player) : Play/Stop | 6 Play "key6.mp3"
7 Re-enable WiFi (https://tcd.out-a-ti.me/#wifi-power-saving-features) | 8 Music Player (https://tcd.out-a-ti.me/#the-music-player) : Next track | 9 Return from Time Travel

0
Time Travel (https://tcd.out-a-ti.me/#time-travel)

## Additional Music Player commands

Music Player (https://tcd.out-a-ti.me/#the-music-player) : Display current track | 55
Music Player (https://tcd.out-a-ti.me/#the-music-player) : Shuffle off / on | 222 / 555
Music Player (https://tcd.out-a-ti.me/#the-music-player) : Go to track 000 / xxx | 888 / 888xxx

## Admin commands

Disable / Enable line-out audio | 350 / 351
Forbid / Allow Remote Control (https://tcd.out-a-ti.mee/#remote-control-the-tcd) | 992 / 993
Forbid / Allow Keypad Rem. Control | 994 / 995
Release HA Fake-Power Control (https://tcd.out-a-ti.me/#fake-power-control-through-ha) | 996
Restart the Time Circuits | 64738

## Time Circuits Display

A10001986

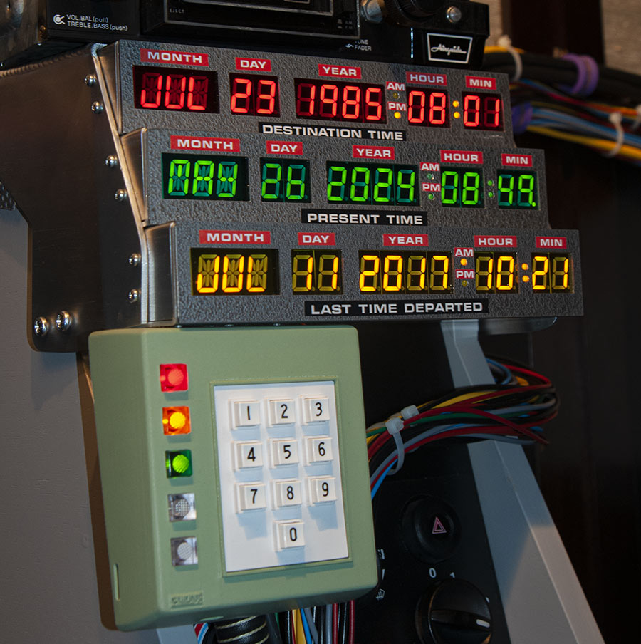
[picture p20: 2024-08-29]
img/mytcd.jpg

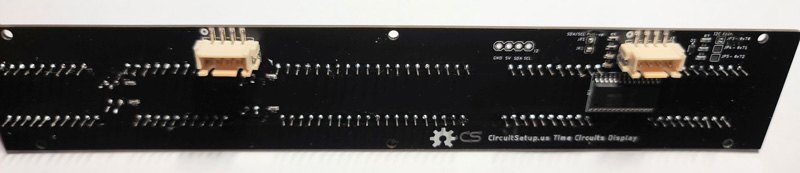
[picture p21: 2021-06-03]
Images/resize/tcd_back.jpg

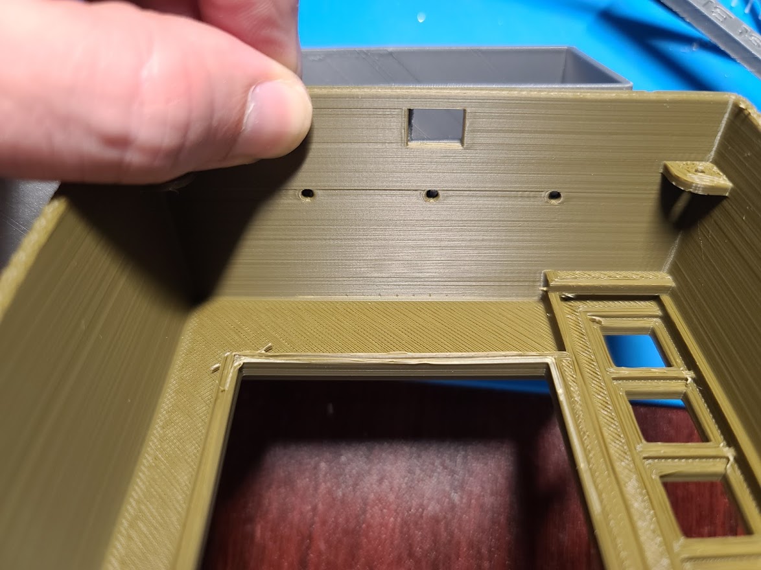
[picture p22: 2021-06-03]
Images/tcd_keypad_mount.jpg

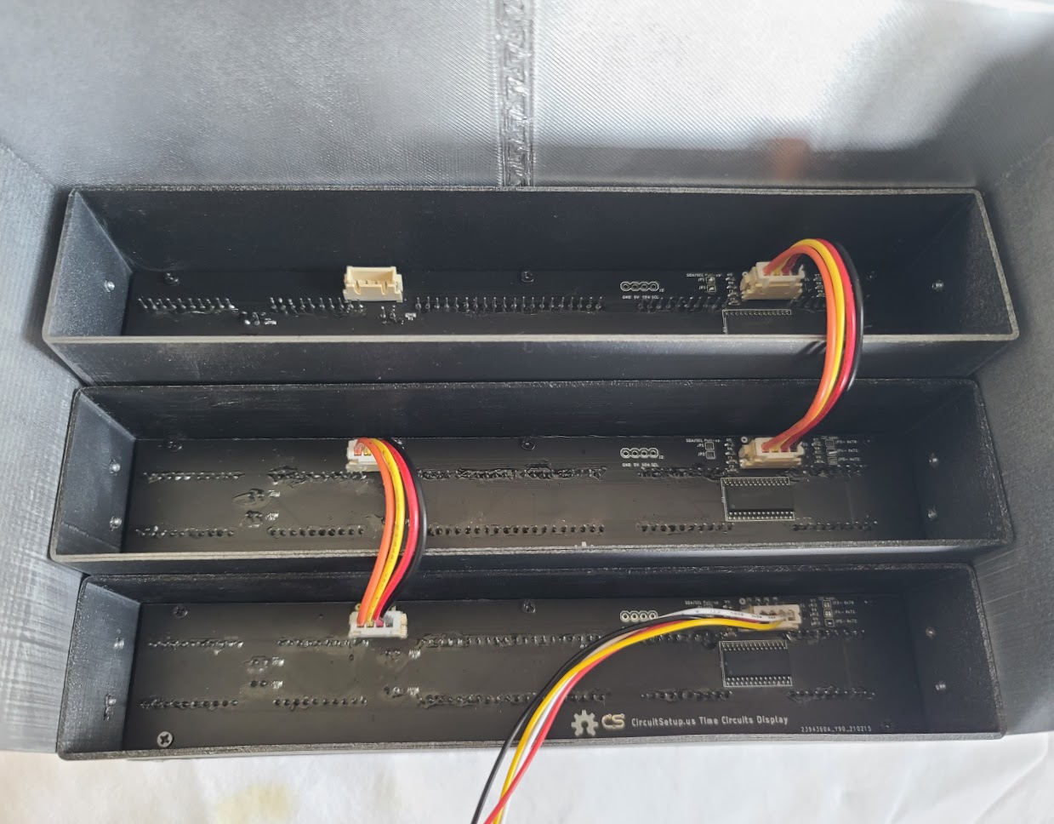
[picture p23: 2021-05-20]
Images/tcd_back2.jpg

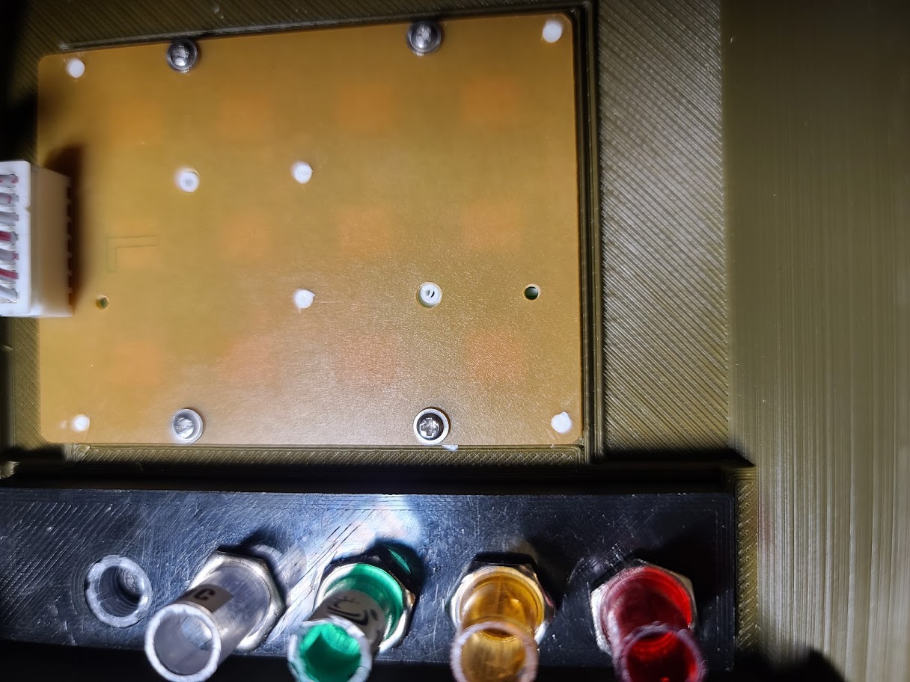
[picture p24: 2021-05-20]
Images/keypad_back.jpg

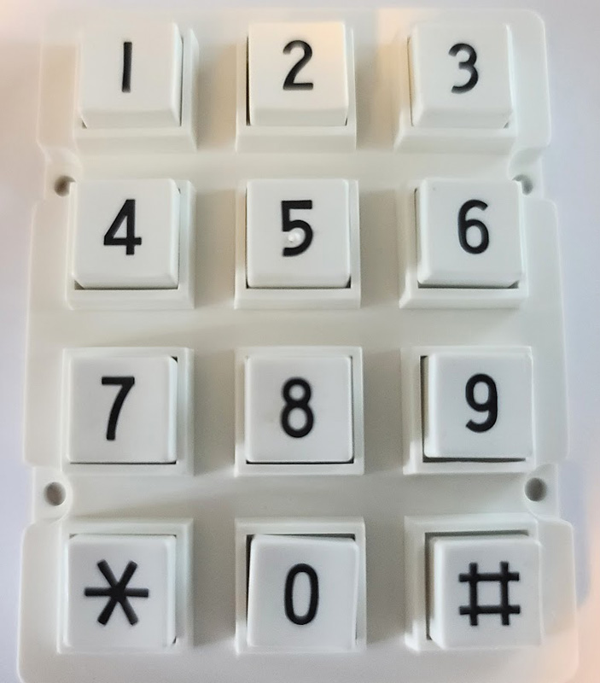
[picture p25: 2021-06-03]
Images/resize/tcd_keypad_stock.jpg

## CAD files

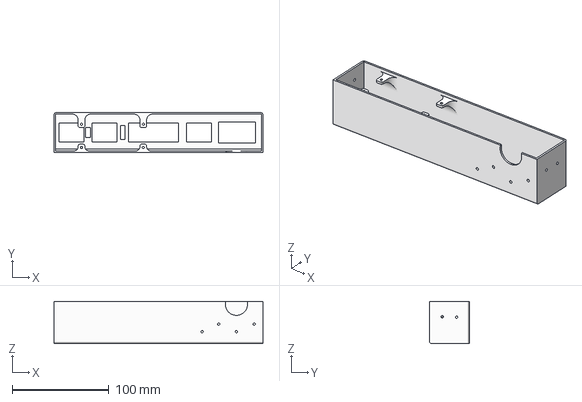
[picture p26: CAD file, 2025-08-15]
Hardware/3d Files/last_time_departed_v3.3mf
215.9 x 41.3 x 43.8 mm

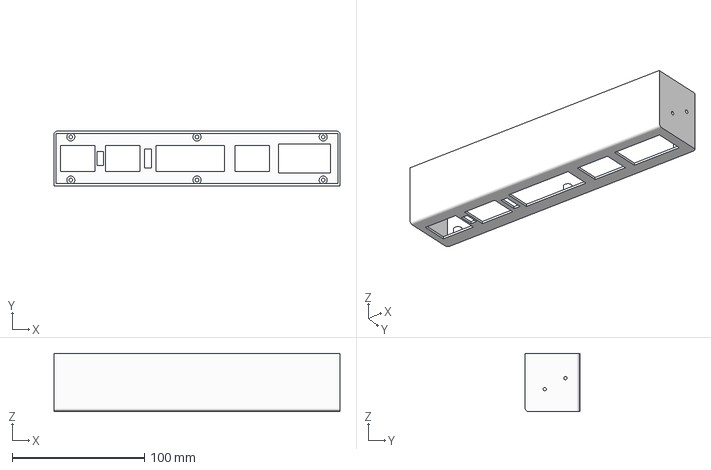
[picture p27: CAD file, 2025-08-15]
Hardware/3d Files/present_time_v3.3mf
215.9 x 41.3 x 43.8 mm

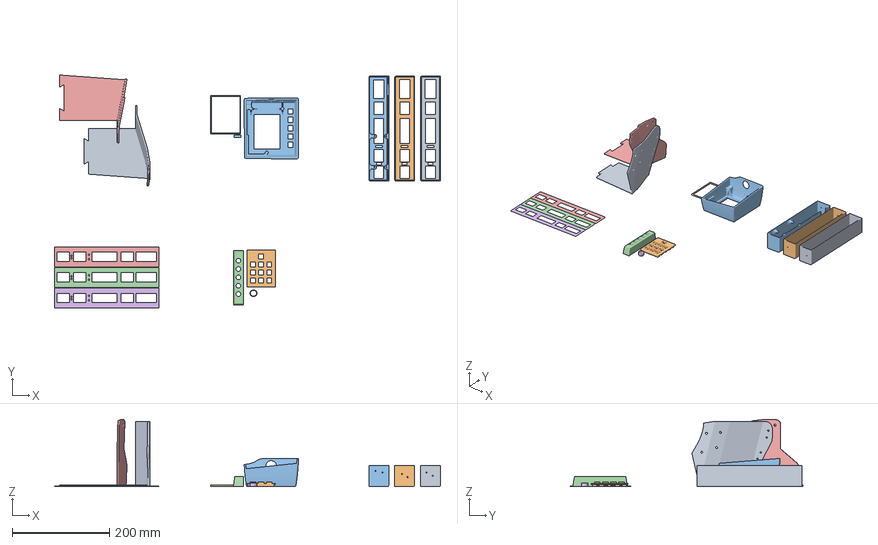
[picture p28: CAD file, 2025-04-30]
Hardware/3d Files/circuitsetup_time_circuits_display.3mf
795.7 x 480.3 x 138.3 mm
tcd_enclosure_A
Keypad Bezel
Keypad
Keypad Lens Mount
tcd_enclosure_B
Enter Button Spacer
Number pad surround
CLEAR
Present Time
Destination Time
Last Time Departed
time_circuits_faceplate.step x 3

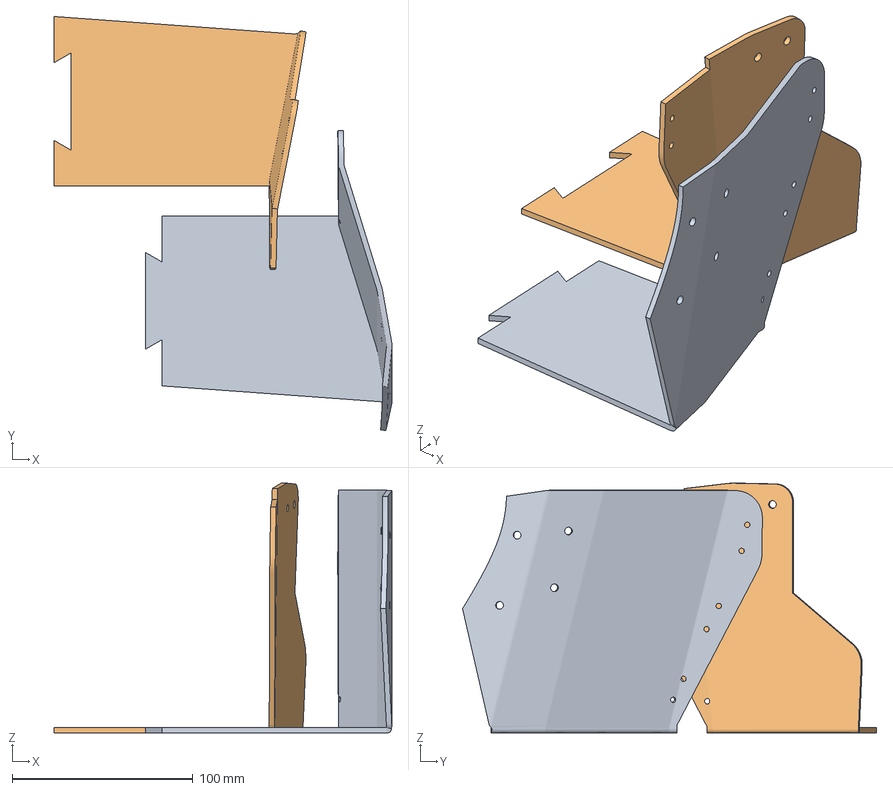
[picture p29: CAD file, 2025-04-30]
Hardware/3d Files/x1_enclosure_2_piece-v4.1.3mf
187.1 x 229.1 x 138.3 mm
tcd_enclosure_A
tcd_enclosure_B

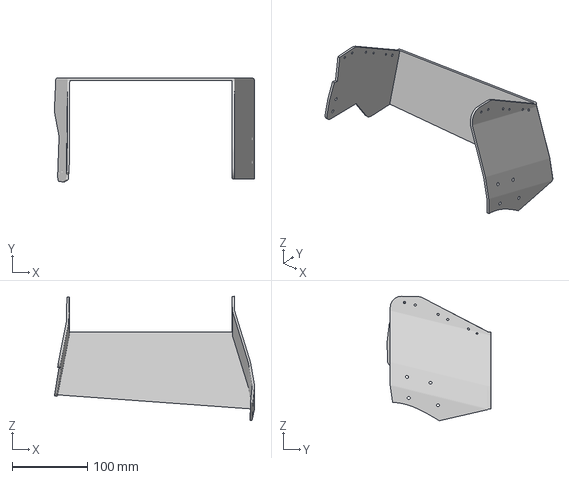
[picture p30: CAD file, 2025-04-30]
Hardware/3d Files/enclosure_one_piece-v4.1.3mf
266.6 x 138.3 x 165.9 mm

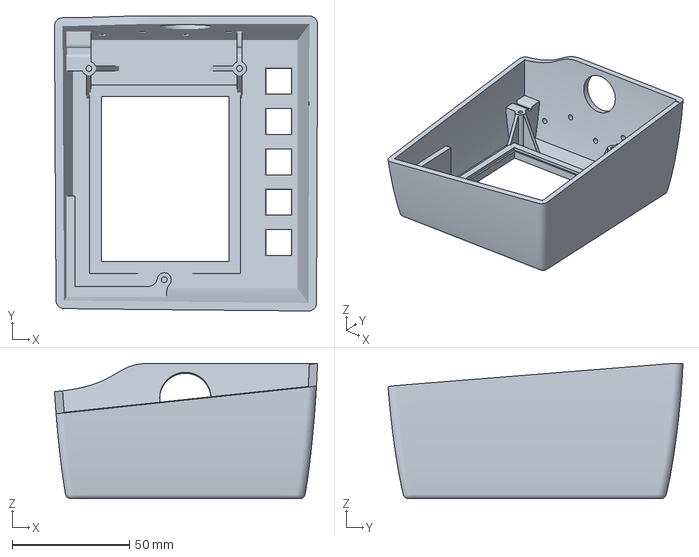
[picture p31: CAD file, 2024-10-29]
Hardware/3d Files/keypad_body_v3-4_hole_mount.3mf
112.3 x 125.9 x 57.6 mm

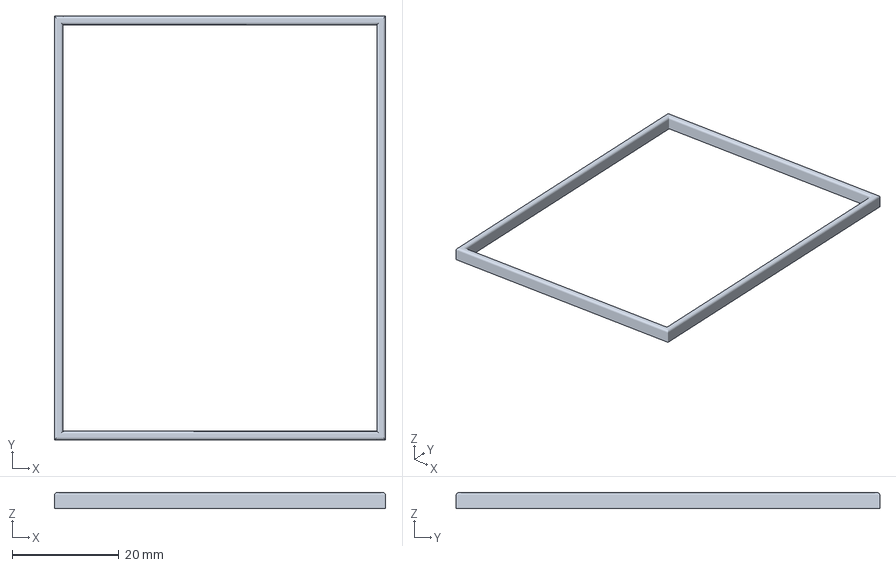
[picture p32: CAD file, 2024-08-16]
Hardware/3d Files/keypad_body_v3_surround.3mf
62.0 x 79.3 x 3.00 mm

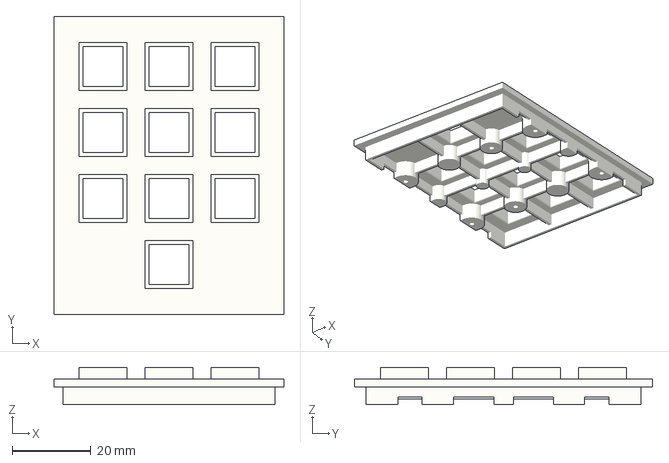
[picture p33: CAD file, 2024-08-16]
Hardware/3d Files/keypad_bezel-v3.3mf
58.4 x 75.7 x 9.50 mm

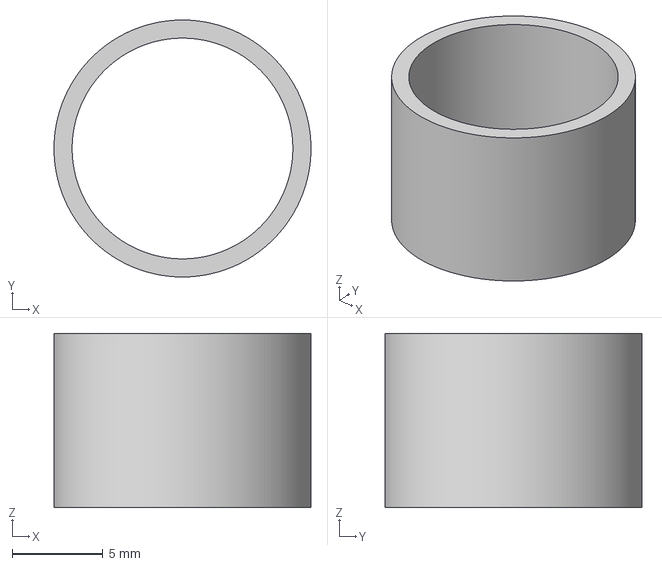
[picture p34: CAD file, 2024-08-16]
Hardware/3d Files/keypad_enter_spacer.3mf
14.2 x 14.2 x 9.60 mm

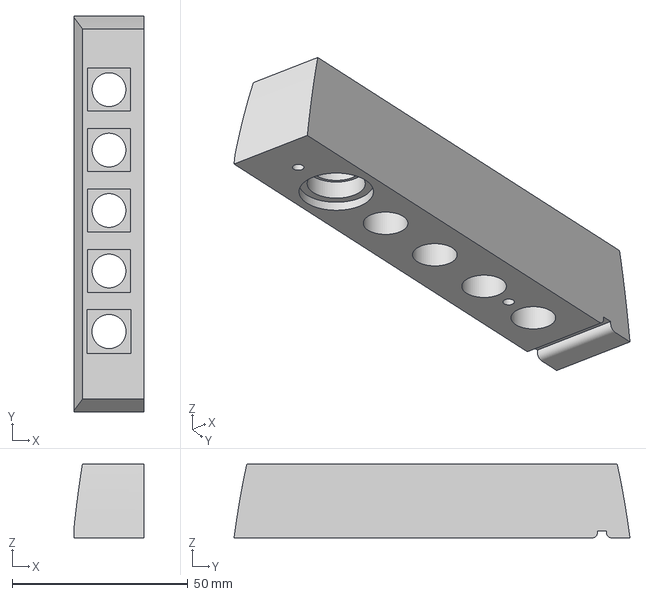
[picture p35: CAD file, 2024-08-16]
Hardware/3d Files/keypad_lens_mount_v2-1.3mf
20.0 x 112.6 x 21.0 mm

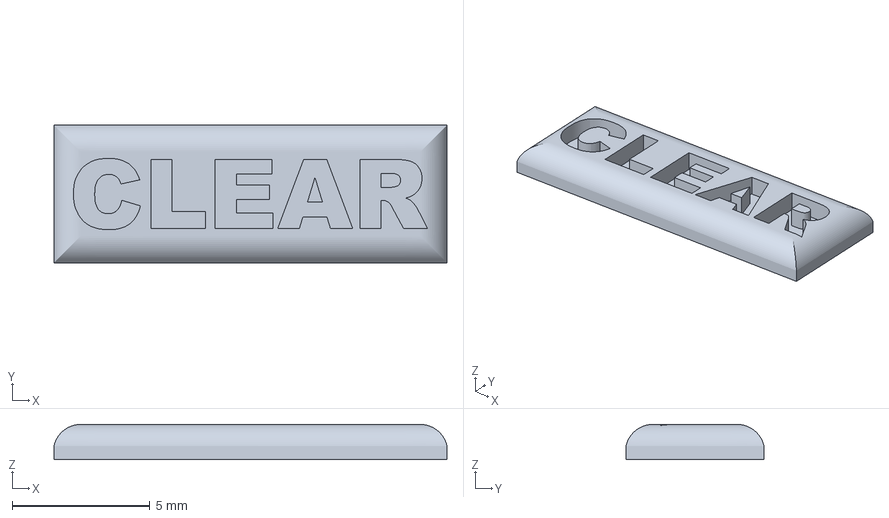
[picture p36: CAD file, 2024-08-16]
Hardware/3d Files/keypad_body_v3_clear.3mf
14.2 x 5.00 x 1.28 mm

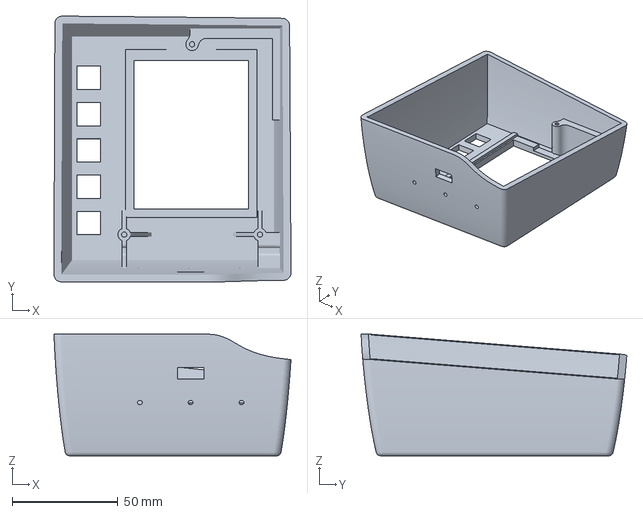
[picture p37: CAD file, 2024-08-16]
Hardware/3d Files/keypad_body_v3-3_hole_mount.3mf
112.3 x 125.9 x 57.6 mm

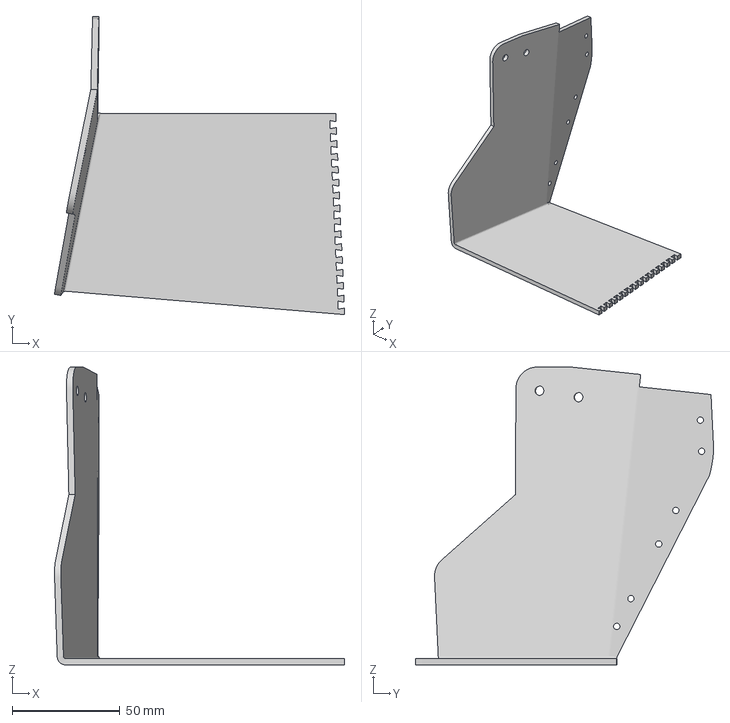
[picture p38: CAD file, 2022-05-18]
Hardware/3d Files/enclosure_left-v3.3mf
134.8 x 138.6 x 138.5 mm

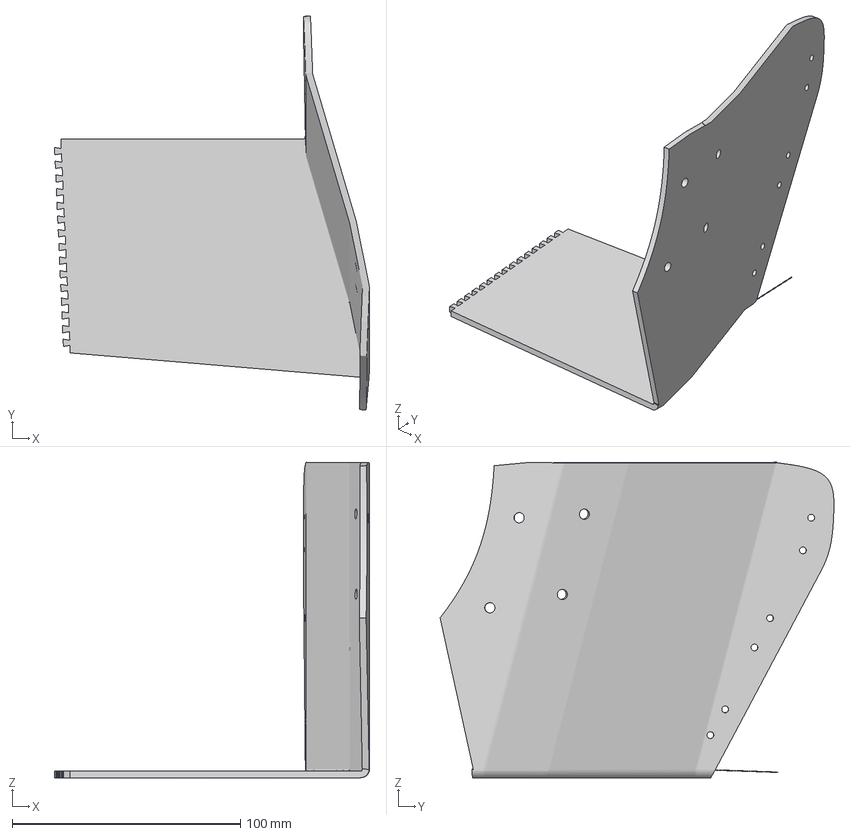
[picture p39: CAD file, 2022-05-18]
Hardware/3d Files/enclosure_right-v3.3mf
137.9 x 172.4 x 138.2 mm

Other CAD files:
Hardware/3d Files/destination_time_v3.3mf
Hardware/3d Files/pres_time_enclosure-v2.5.3mf
Hardware/3d Files/dest_time_enclosure-v2.5.3mf
Hardware/3d Files/last_time_enclosure-v2.5.3mf
Hardware/3d Files/Old_Versions/button_lens_bracket-v2.stl
Hardware/3d Files/Old_Versions/button_lens_bracket.stl
Hardware/3d Files/Old_Versions/cura_keypad_bezel-v2.3mf
Hardware/3d Files/Old_Versions/cura_keypad_body-v2.3mf
Hardware/3d Files/Old_Versions/dest_time_enclosure-v2.3mf
Hardware/3d Files/Old_Versions/dest_time_enclosure-v2.5.3mf
Hardware/3d Files/Old_Versions/enclosure_left.stl
Hardware/3d Files/Old_Versions/enclosure_one_piece-v2.3mf
Hardware/3d Files/Old_Versions/enclosure_one_piece-v2.stl
Hardware/3d Files/Old_Versions/enclosure_one_piece-v3.3mf
Hardware/3d Files/Old_Versions/enclosure_one_piece-v4.3mf
Hardware/3d Files/Old_Versions/enclosure_one_piece.stl
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

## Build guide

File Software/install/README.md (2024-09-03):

This folder holds all files necessary for immediate installation on your Time Circuits Display. Here you'll find
- a binary of the current firmware, ready for upload to the device;
- the latest audio data

## Firmware Installation

If a previous version of the Time Circuits Display firmware is installed on your device, you can update easily using the pre-compiled binary. Enter the [Config Portal](https://github.com/CircuitSetup/Time-Circuits-Display/tree/master?tab=readme-ov-file#the-config-portal), click on "Update" and select the pre-compiled binary file provided in this repository. 

## Audio data installation

The firmware comes with some audio data ("sound-pack") which needs to be installed separately. The audio data is not updated as often as the firmware itself. If you have previously installed the latest version of the sound-pack, you normally don't have to re-install the audio data when you update the firmware. Only if the TCD displays "PLEASE INSTALL AUDIO FILES" during boot, an update of the audio data is needed.

The first step is to download "install/sound-pack-xxxxxxxx.zip" and extract it. It contains one file named "TCDA.bin".

Then there are two alternative ways to proceed. Note that both methods *require an SD card*.

1) Through the Config Portal. Click on *Update*, select the "TCDA.bin" file in the bottom file selector and click on *Upload*. Note that an SD card must be in the slot during this operation.

2) Via SD card:
- Copy "TCDA.bin" to the root directory of of a FAT32 formatted SD card;
- power down the TCD,
- insert this SD card into the slot and 
- power up the TCD; the audio data will be installed automatically.

See also [here](https://github.com/CircuitSetup/Time-Circuits-Display/tree/master?tab=readme-ov-file#audio-data-installation).

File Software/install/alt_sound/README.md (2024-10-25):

Alternative and custom sounds. Copy these to a FAT formatted SD card and leave this card in the slot.

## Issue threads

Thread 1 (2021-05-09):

Fix settings menu to work with keypad input

CircuitSetup, 2021-05-09:
Currently holding down the enter button enters menu mode, and pressing enter goes to the next field, but the keypad does not take number input from the keypad to change time and update settings.

The menu function may need to be made non blocking to capture key presses properly.

CircuitSetup, 2022-08-18:
This was fixed in PR #16

Closed 2022-08-18.

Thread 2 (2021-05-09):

Pressing enter in settings menu mode goes to next settings item

CircuitSetup, 2021-05-09:
Currently only the present time is updated via the settings menu. Hitting enter after the min field should go to the next display, then other mis settings, then SAVE
Need to fix/add:
- last time departed
- brightness per display
- Add beep on/off (the tone that sounds in sync with the second leds)
- Add wifi on/off (to get NTP time)

CircuitSetup, 2022-08-18:
This was fixed in PR #16

Closed 2022-08-18.

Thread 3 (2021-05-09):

Add beep sound to sync with seconds led blink

CircuitSetup, 2021-05-09:
With the audio mixer library being used, there is a way to play 2 sounds at once, but it currently does not work. It may be necessary to not play the beep sound when a keypad tone or time travel sound is played. So...
- the beep sound only plays if other sounds are not played, and the beep option is turned on
- the beep sound should be played softer than other sounds as to not be totally annoying

WMasterJedi, 2022-10-01:
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

I would not mind that because the sound is only on for when you're typing on the keypad, and I wouldn't mind not having it for time travel either. Because the sound for the keypad is short and personally, I don't mind pausing the beeping for the time travel.

CircuitSetup, 2023-04-06:
This is now included with v2.7

Closed 2023-04-06.

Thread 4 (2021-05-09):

Allow music to be played from sd card

CircuitSetup, 2021-05-09:
- Add a settings menu option to play sounds/music from the SD card if mp3 files are detected.
- Set a sound to play if a GPIO is pulled high. 13 and 14 have headers on the control board.

jasonglisson, 2021-07-26:
I might be able to look into this. I just got my circuits and was looking over the documentation. I've got some experience triggering sounds with arduino in blasters and lightsabers that I've written code for. Really nice work on this kit by the way!

CircuitSetup, 2021-07-26:
This can be done using the ESP8266Audio library that is used for other sounds, FYI. There is another file that would have to be included to do stuff from an SD card.

Glad you like the kit! Thanks!

jasonglisson, 2021-07-27:
What are you thoughts about triggers for the music? We're you wanting
alarms or did you have something else in mind?

I'll have a look at the library. Several of the ones I've worked with
require mp3/wav files to be named 0000 or 0001 etc. And then some require
specific types of high speed SD cards in order to play multiple sounds at
the same time.

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

CircuitSetup, 2021-07-27:
I was thinking this would work with an alarm that would allow setting the time for the alarm and setting the sound. In addition this could also be a stand alone music player, but it may be more useful as an alarm feature first.

I started to implement a web interface as well, but right now all it does is set the wifi credentials. Other fields are in there but they do not save properly yet. It may be easier to allow for setting time and sound files with this. Data is stored in the eeprom.

CircuitSetup, 2022-08-18:
This was added in PR #16

Closed 2022-08-18.

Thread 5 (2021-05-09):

Add display flicker when time traveling

CircuitSetup, 2021-05-09:
In order to add some additional effect to the time traveling:
- Turn random displays on and off and random rates
- Dim random displays at random amounts
- Scramble different displays at random
- Combo of all 3, where a display can turn off, come back on at a dim level, all segments turn on, then back into a number, etc.
- Turn enter button led on and off at random

CircuitSetup, 2022-08-25:
Added in #16

Closed 2022-08-25.

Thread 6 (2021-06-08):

Fix settings in web interface

CircuitSetup, 2021-06-08:
Currently the web interface has fields for:
- Beep Sound
- NTP Time Server
- Brightness per display

Currently these are placeholders and do not affect anything. They need to be tied into the actual variables that control these parameters. Web interface variables are defined in tc_wifi.cpp

CircuitSetup, 2021-06-12:
Also need to add a fields for
- Time zone offset
- DST

CircuitSetup, 2021-12-14:
This is fixed with eb9f815

Ricky3Nut, 2021-12-18:
Thanks John. Do I have to update the module or something to get the fix to take effect? I am still not able to set the time on the web interface or adjust for my time zone.

CircuitSetup, 2021-12-19:
> Thanks John. Do I have to update the module or something to get the fix to take effect? I am still not able to set the time on the web interface or adjust for my time zone.

Yes. There is an option to update software from the web interface. I have to post the compiled .bin file though. Stay tuned.

Closed 2021-12-14.

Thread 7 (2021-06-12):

Add alarm clock functionality

CircuitSetup, 2021-06-12:
Just some ideas:
- Set time from web interface or from settings menu
- Can be turned on or off by holding down a button on the keypad
- Sound from sd card can be chosen to play as the alarm via web interface
- Alarm can be turned off by pressing any button on the keypad

CircuitSetup, 2022-08-18:
This was added in PR #16

Closed 2022-08-18.

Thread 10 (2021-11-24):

Years after 2159 do not copy correctly when time traveling

CircuitSetup, 2021-11-24:
For example, the year 2160 is copied to present time as 2000. I believe this has something to do with hitting a limit of DateTime in RTClib.

Closed 2021-12-14.

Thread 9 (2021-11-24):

After time traveling a 0 is inserted into the date entry buffer

CircuitSetup, 2021-11-24:
The date entry buffer is getting a 0 inserted after time traveling, causing the next entered date to be incorrect.

realA10001986, 2022-08-01:
I think that can be fixed as follows, in tc_keypad.cpp:

Somewhere at the top, insert:

bool doKey = false;

Then replace the keypadEvent function with the following code:

// handle different cases for keypresses
void keypadEvent(KeypadEvent key) {
    switch (keypad.getState()) {
        case PRESSED:
            if(key != '#' && key != '*') {
                play_keypad_sound(key);
            }
            doKey = true;    
            break;
        case HOLD:    
            if(key == '0') {
                doKey = false;
                timeTravel();        
            }
            break;
        case RELEASED:
            if(doKey && key != '#' && key != '*') {
                if(isSetUpdate) {
                    recordSetTimeKey(key);
                } else {
                    recordKey(key);
                }
            }
            break;
        case IDLE:
            break;
    }
}

This way, the held "0" key is not inserted into the buffer.

CircuitSetup, 2022-08-18:
This is fixed in PR #16
Thanks!

Closed 2022-08-18.

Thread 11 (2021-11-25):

Cannot Compile 'clockdisplay.h'

Ricky3Nut, 2021-11-25:
I keep getting the following error when I try to compile the sketch and program the board. I can see the file in ...software/src/timecircuits and its open in a tab in IDE but for some reason it keeps fizzing out on me.... Any help please?? :-) Thanks!

tc_wifi.h:23:26: fatal error: clockdisplay.h: No such file or directory
compilation terminated.
exit status 1
clockdisplay.h: No such file or directory

CircuitSetup, 2021-11-26:
I believe with the Arduino IDE you have to have the clockdisplay files in your libraries directory. Have you tried this?

Ricky3Nut, 2021-11-26:
Yep, that was it. Thanks! I actually had 4 or 5 others that were doing the same thing then I figured out by experimenting just before getting your message. But that helped confirm the problem and solution, so thank you very much! Now I am stuck on getting the ESP32 Sketch Data tool installed so I can upload the sounds. I am following the tutorial you linked but for some reason I cannot locate a Tools folder in my Arduino directory. I had to stop and go sit down for Thanksgiving dinner so I will come back in a bit and see if I can get it sorted....

Ricky3Nut, 2021-11-29:
got it all sorted with the software. Thanks

Closed 2021-11-29.

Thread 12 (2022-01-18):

Problematic order

dagwud, 2022-01-18:
Hi

Sorry to backchannel you like this, but I’m not finding any way to contact you…

I have an issue with an order that’s pending and that must be resolved before shipping. Could you please reach out to me by email? Order 217937

Closed 2022-01-18.

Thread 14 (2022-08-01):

Month is possibly off by one when stored to the RTC

realA10001986, 2022-08-01:
If I am not mistaken, the hardware RTC expects the month in the range from 1 to 12, not 0 to 11. TimeInfo, however, uses 0-11, so month needs to incremented before storing in getNTPTime().

Consequently, in clockDisplay::setMonth, the decrement of monthNum must be done regardless of isRTC.

CircuitSetup, 2022-08-03:
This would explain a bug I was seeing with the days of the month not matching at the end of months. I'll have to test this. Thanks for pointing this out!

CircuitSetup, 2022-08-18:
This is fixed in with PR #16

Closed 2022-08-18.

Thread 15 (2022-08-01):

Time Travel: Make PresentTime a real clock

realA10001986, 2022-08-01:
By using a "fake" year, it is pretty straight forward to use presentTime as a normal clock:

In tc_time.cpp, replace timeTravel with the following:

```
/* Time Travel: User enters a destination time.
 *
 *  -) copy present time into departed time (where it freezes)
 *  -) copy destination time  to present time (where it continues to run as a clock)
 *
 *  This is called from tc_keypad.cpp
 */

void timeTravel() {
    int tyr = 0;
    int tyroffs = 0;

    timetravelNow = millis();
    timeTraveled = true;
    beepOn = false;
    play_file("/timetravel.mp3", getVolume());
    allOff();

    // Copy present time to last time departed
    departedTime.setMonth(presentTime.getMonth());
    departedTime.setDay(presentTime.getDay());
    departedTime.setYear(presentTime.getYear());
    departedTime.setHour(presentTime.getHour());
    departedTime.setMinute(presentTime.getMinute());
    departedTime.save();

    // Copy destination time to present time
    // DateTime does not work before 2000 or after 2159
    // so we use yearOffs to fake a year with identical calendar within 2000-2159
    // RTC keeps running on 2000-2159, but display is skewed by yearOffs
    // upper limit 2150 to avoid overflow while clock running

    tyr = destinationTime.getYear();
    if (tyr < 2000) {
        while(tyr < 2000) {
            tyr += 28;
            tyroffs += 28;
        }
    } else if(tyr > 2150) {
        while(tyr > 2150) {
            tyr -= 28;
            tyroffs -= 28;
        }
    }

    if (!presentTime.isRTC()) presentTime.setRTC(true);

    presentTime.setYearOffset(tyroffs);

    rtc.adjust(DateTime(
            tyr,
            destinationTime.getMonth(),
            destinationTime.getDay(),
            destinationTime.getHour(),
            destinationTime.getMinute()
            )
    );

    Serial.println("timeTravel: Success, good luck!");
}
```

In clockdisplay.cpp:

```
void clockDisplay::setYear(uint16_t yearNum) {
    // Place LED pattern in year position in buffer, which is 4 and 5.
    _year = yearNum;
    yearNum -= _yearoffset;
    _displayBuffer[4] = makeNum(yearNum / 100);
    _displayBuffer[5] = makeNum(yearNum % 100);
}

void clockDisplay::setYearDirect(uint16_t yearNum) {
    // Place LED pattern in year position directly, which is 4 and 5.
    // useful for setting the year to the present time
    _year = yearNum;
    yearNum -= _yearoffset;
    directCol(4, makeNum(yearNum / 100));
    directCol(5, makeNum(yearNum % 100));
}

void clockDisplay::setYearOffset(int16_t yearOffs) {
    _yearoffset = yearOffs;
}
```
In clockdisplay.h add the marked lines:

```
    void setYear(uint16_t yearNum);
    void setYearOffset(int16_t yearOffs); // <----
    void setYearDirect(uint16_t yearNum);

[...]

    uint16_t _displayBuffer[8];  // Segments to make current time.

    uint16_t _year = 2021;     // keep track of these
    int16_t  _yearoffset = 0;  // Offset for faking years < 2000 or > 2159 <----

    uint8_t _month = 1;
```

I possibly omitted other definitions/declarations needed, but these are straight forward.

The RTC is loaded with a year with an identical calendar (as apparently happens every 28 years), and the year displayed is faked by _yearoffset.

CircuitSetup, 2022-08-03:
Thanks for the tip! I'll test this soon!

realA10001986, 2022-08-03:
I wrote you an email via the web contact form.

realA10001986, 2022-08-04:
Made a fork with all of my changes, here:
https://github.com/realA10001986/Time-Circuits-Display-A10001986

CircuitSetup, 2022-08-18:
This is fixed in PR #16
Thanks!

Closed 2022-08-18.

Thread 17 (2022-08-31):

unable to load sounds via SD and web portal or save settings in web portal for v2

thecolor, 2022-08-31:
the device either does not recognize the SD card or the web portal is not recognizing the content.
Unable to load sounds via the enter key command instructed either.
unable to save settings in the web portal.  *upon clicking save, nothing changes.

CircuitSetup, 2022-08-31:
I just updated the data directory to remove some files that should not have been there. Please try again with only the files currently in the data directory.

thecolor, 2022-08-31:
I only have the mp3 files on the SD card. Is one of those the wrong file?
I upgraded to v2 yesterday via the web portal and while the web portal loads, the settings don't save anything, so the time is central instead of the PDT I've tried to save and no other changes I make save.

CircuitSetup, 2022-08-31:
beep, and a nmoff2, and nmon2 should not have been in there. 4 ee files were just added.

When you save everything does the TCD reset?

thecolor, 2022-08-31:
I literally only loaded these files to the root of the SD card and tried that (based on how I was understanding the [instructions](https://github.com/CircuitSetup/Time-Circuits-Display/wiki/9.-Programming-&-Upgrading-the-Firmware-(ESP32)).

beep.mp3
Dtmf-0.mp3
Dtmf-1.mp3
Dtmf-2.mp3
Dtmf-3.mp3
Dtmf-4.mp3
Dtmf-5.mp3
Dtmf-6.mp3
Dtmf-7.mp3
Dtmf-8.mp3
Dtmf-9.mp3
enter.mp3
startup.mp3
timetravel.mp3

should I have loaded the entire DIR "src" or "data"?

The v2 .bin has been loaded via the web portal.

thecolor, 2022-08-31:
ok, so it does seem to reset when I click save, although nothing changes.
I've reloaded all the content referenced to the SD, and the audio section to "copy" is still not present, (in addition to no changes being saved.)  - screenshot attached for the portal I'm seeing.

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

CircuitSetup, 2022-08-31:
hum, I'm sorry this is being such a pain to update.

I made a small change in the way it stores data - please try this bin file: https://github.com/CircuitSetup/Time-Circuits-Display/blob/v2/Software/v2.0.0_tcd_firmware_spiffs.bin

Also, do you have a way to view serial output when it is connected to a computer with a USB cable? Via the Arduino IDE or Platformio, maybe?

thecolor, 2022-08-31:
no worries at all... I appreciate the quick updates.

So, the new bin, enabled the web portal to seemingly accept updates, and implied that the audio files were copied, however, upon reboot, only the red, orange and green buttons are lit, the time screens have shut off.

They do seem to work (in that the few times I've rebooted it, the Back To The Future" screen scrolls in, but then all three go blank.

unfortunately, I am not connected to a computer (just power.)

I could, but I may not have the necessary utilities to view things.

If you have instructions, I can try.

thecolor, 2022-08-31:
new discovery...

it was not displaying 'cause I had enabled "Enable fake power switch"
clearly, I was testing and didn't (don't) know how to "power it on"... so I disabled that option.
Now, everything but sound appears to be working.

Rudycub23, 2022-09-01:
> the device either does not recognize the SD card or the web portal is not recognizing the content. Unable to load sounds via the enter key command instructed either. unable to save settings in the web portal. *upon clicking save, nothing changes.

Hello!
I also did an update, both yesterday and today, and had a similar experience to yours with regard to the sound files.  It took me a little bit of time, but I finally figured it out and was successful in loading the sounds. (BTW, I am totally a noob at this; I bought the kit because I thought it was cool, and I only have one other experience with Arduino, so if what I'm telling you here is something that you obviously tried, then please forgive me!)

It would seem that all of the downloaded MP3 files need to be present in the root folder of the SD card with no variations.  I downloaded the files one at a time, and after downloading, apparently all of the files were "renamed", adding their source to the beginning of the file name (Ex: the file "enter" was labeled as "Software_data_src_enter", "startup" was labeled as "Software_data_src_startup", and so forth.).  I figured that after I put the SD card into the slot and not getting it to be recognized was that perhaps the file names were incorrect, so I went back to my computer and removed the source from the name of each file.  After doing this, I put the SD card back into the slot, powered 'er up, and bingo!  (I knew it had worked when I heard the clocks ticking when the opening title showed). Then I was able to access the menu from both the keyboard and the portal, uploaded the sounds, and everything was gold.

Anyway, I hope this helps with your sound issue.

CircuitSetup, 2022-09-01:
@Rudycub23 Sorry it wasn't easier to get working correctly! I'm glad you figured it out though, and thanks for posting your method for getting there.

thecolor, 2022-09-01:
Thanks @Rubycub23  - I will say, the display has stayed lit all night, so that is a good sign... however, I've now noticed that the AM/PM lights are no longer lit - which appears to be related to Enabling "Enable 24-hour clock mode"

I would like the 24-hour clock mode and the AM/PM lit.  I might even prefer the "Present Time" to be 24-hour and the Designation Time and Last Time Departed to not be 24-hour.

As for the sounds, all the files "appear" to be labeled correctly.

Here's a snapshot of the files I'm loading (noting that they are in the root of the SD card.)

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

thecolor, 2022-09-01:
it's also formatted as the instructions indicated.  (despite formatting it on my MAC.)

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

thecolor, 2022-09-01:
so, the most recent try still does not work. I forgot that my MAC adds hidden files to the drive on copying... so, I reformatted on my wife's PC and re-added the same files note above and still no audio.  I will say, it did work prior to the v2 upgrade.

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

realA10001986, 2022-09-01:
Additional files don't make a difference.

**ALL** the files of the "data" folder need to be on the SD, unmodified, including the  txt file.

If you don't see the menu "copy sound files" and there is no such option in the Config Portal, one or more files are missing or have been modified.

realA10001986, 2022-09-01:
If you see the "copy audio files" menu (or the respective option in the Config Portal), the SD is recognized and validated, ie the firmware checked if all files are there and unmodified.

If you can activate the "copy audio files" menu, and there is still no sound, there might be a bug (which I unfortunately can't reproduce here). Will investigate though.

Rudycub23, 2022-09-01:
OK, it looks like you're almost there, but I'm seeing a couple of things in the image above that will need to be corrected (if it hasn't been done already!).

First, those two directories at the top will need to be removed.  Next, it looks to me as if the file names are still not in the correct format; specifically, the dot/period and underscore will need to be removed from the file name of those files.  I think I would do these corrections using the PC if the Mac is adding hidden items, as it would seem that anything extraneous that is added to the root directory will cause it to not work correctly.  Also of note, it looks like you have a couple of duplicate sound files present as well (specifically, "alarm", alarmoff" and "alarmon").  Only one file of each is necessary; duplicates may not make it work, too.
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
CircuitSetup, 2022-09-02:
> It might be possible that your volume control is turned up too much. I recall seeing that it was all dependent upon how your unit is powered. Early on in my build, I powered it using the USB cable with an old phone charger that put out 1000mA. Sometimes, if I had the volume knob turned up too high, it would freeze up during a time travel event. When I finalized my build, I used a wall-wart type transformer that is 5.2 V with 1.6 amps, which worked much better.
>
> Try it again, but turn the volume down to bare minimum, and see how it goes. If it works, then gradually turn up the volume to where you like it and can get successful time travels at the same time.

Yes, this can still happen if you're not connected to a WiFi network, and the sound is nearly all the way up. I'm guessing this is what is happening with @thecolor's display. The only way it would be a problem with the Dest. Time display is if certain characters or LEDs are not lighting up. I can't see the video either, but if the other displays are lit, but the LED's are not blinking for the seconds on the other displays, then the ESP32 "browned out" (because it didn't get enough power) and froze.

CircuitSetup, 2022-09-02:
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

uh, yeah they are! By time I remembered my bitwise operators, and started counting bits, I ran out of time and gave up. haha

thecolor, 2022-09-02:
surprised google is not done processing the video by now.
regardless, I've turned the audio all the way down with the same results.

Does the SW sound act in the background (regardless of the HW sound?)

Since my sound problem was it being switched to SW sound, I wonder if it is to high (even though I changed it back to HW sound.)

realA10001986, 2022-09-02:
No, SW means that the software ignores the pot and sets the volume itself.

The SW volume level does not matter for the known power issue with the pot.

That video could really bring some more light....

thecolor, 2022-09-02:
ok, since the googs is being stupid, I uploaded it to the tube: https://youtu.be/0edFYNtI5Pw

CircuitSetup, 2022-09-02:
> ok, since the googs is being stupid, I uploaded it to the tube: https://youtu.be/0edFYNtI5Pw
>
> so, this happens regardless of audio being on or off.

Thanks for uploading it. I honestly haven't seen that happen before with a display. I noted that it is flickering more than the other displays, like there is something wrong with it. I'll get a new display in the mail to you. Sorry it took so long to diagnose!

thecolor, 2022-09-02:
thanks.

thecolor, 2022-09-02:
oh, no... my "human" eyes can't see the flicker at all... yes, I totally thought that was just the video... and potential angle of filiming.

That said, I am using a Samsung wall-wart:
Adaptive Fast Charging:
Output: 9.0V --- 1.67A or 5.0V --- 2.0A

The hub is for my 'puter(s)... I have seven sitting around my desk.  ;)
I'm a *nix geek... so I tinker a lot.
Plugging it into one of the ports, (which is coming from the Mac port) appears to not be enough power to keep it running... it gets partly through the boot and then reboots.

I'll see if I can find a smaller powered wall-wart

thecolor, 2022-09-02:
well, I found some REALLY old wall-warts in a box...
one is an output of 1A, the other is an output of 805mA and they still end up with the same result(s).  :/

CircuitSetup, 2022-09-02:
I'm betting something is wrong with either the diode (D1) or the main IC on the back of the display PCB. It could be the wire, but I doubt it since it works initially.

thecolor, 2022-09-02:
is it something I can troubleshoot?

CircuitSetup, 2022-09-02:
> I think I set it up correctly... didn't seem that challenging. you tell me. :D

I don't see anything physically wrong in the picture, but it could be as simple as a cold solder joint. You do have displays that I assembled by hand, so that's more than likely part of the issue 😅

thecolor, 2022-09-02:
I'm not an expert, but it was simple to put together and I would say, very well made!
stuff happens.  no human or electronic is perfect.  :)

CircuitSetup, 2022-09-02:
> I'm not an expert, but it was simple to put together and I would say, very well made! stuff happens. no human or electronic is perfect. :)

Thanks for understanding! I try :)

CircuitSetup, 2022-09-05:
Closing this - reopen if necessary

thecolor, 2022-09-06:
The new red board fixed the problem.
Do you want me to send back the old one to try and troubleshoot it?

Closed 2022-09-05.

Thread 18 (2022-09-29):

Guide on how to activate and wire the fake power switch on IO13

WMasterJedi, 2022-09-29:
I would like to know how to wire a switch onto IO13 and how to activate the feature.

CircuitSetup, 2022-09-29:
I will add this to the Wiki shortly

1. On the back of the keypad is a space for IO13 - Install a switch between IO13 and GND so that switching it on connects the two. I would recommend soldering on a 3 pin header (2.54mm spacing)
2. In the settings portal (which is the IP address of the TCD on your network - if you need to connect the TCD to your network, [instructions are here](https://github.com/CircuitSetup/Time-Circuits-Display/wiki/8.-WiFi-Connection-&-TCD-Settings)) enable "_Use fake power switch_"
3. If using this, you'll probably want to disable the intro by turning off "_Play intro_"
4. Click save to save the settings
5. Provide power to the TCD via the USB port on the bottom of the keypad or via the green connector on the back of the keypad - you should see the white light on the keypad flash
6. Switching on the switch will turn on the TCD display immediately - Turning it off will turn off the display, complete with sound

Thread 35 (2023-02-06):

v2.6 Timer sound

doc1011, 2023-02-06:
Hi, using the new v2.6 speedo/sensors firmware.

When setting a timer, it seems to work and shows the correct remaining time when hitting 44Enter, but there is no sound/display once the timer runs out.

Am using an SD card with 3.mp3 and 6.mp3 on it. Although using the speedo/sensors firmware there is none attached yet.

Have I found a bug or is it me?

Cheers

doc1011, 2023-02-06:
Sorry my fault for not reading the instructions closely enough - didn't realise there was a new sound file for the timer to upload :)

CircuitSetup, 2023-02-06:
> Sorry my fault for not reading the instructions closely enough - didn't realise there was a new sound file for the timer to upload :)

yep! one new sound, so if you put **all of the files** from /software/data on an SD card, turn off TCD, put in card, turn TCD back on, it will load on startup.

doc1011, 2023-02-06:
Works perfectly, thanks!

Closed 2023-02-06.

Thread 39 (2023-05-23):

2.8

doc1011, 2023-05-23:
Hi there with version 2.8 my temp/humidity sensor and speedo display are no longer enabled.

The check boxes to enable the sensor and speedo display that were in 2.6 are gone (although the options to select the types of speedo displays are still there). I've got back to 2.6 where you can tick the boxes to enable them and all working again. Apologies if I am missing something obvious.

Cheers

Closed 2023-05-23.

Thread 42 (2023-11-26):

timecircuits.local

Backtothe1943x, 2023-11-26:
timecircuits.local isn't working and I was wondering when it will be back up in working order
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

realA10001986, 2023-11-26:
timecircuits.local is the address under which you can reach the Config Portal of your Time Circuits Display, no public website. Your phone and the TCD must be in the same network. If your TCD is not connected to a WiFi network (which I assume is the case), connect your phone to the WiFi network "TCD-AP".

Backtothe1943x, 2023-12-02:
oh ok thank you so much

Closed 2023-12-02.

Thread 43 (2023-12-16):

Assembling Control Board BTTF TIME CICRCUIT

Gabin37, 2023-12-16:
Hi,

Got problem for the enter button, I don't know if I cut at the right place. Could you please tell me? Maybe I cut too much or is normal this button is more pressed than the other ?
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

realA10001986, 2023-12-16:
It is pushed up by the button (and the little white spacer) when the PCB is mounted.

Gabin37, 2023-12-16:
on the pic, the PCB is mounted... so Did I cut the button too short?

CircuitSetup, 2023-12-16:
> mounted

Is the white spacer in there. It should still be okay with the spacer, even though it's cut a bit short.

Gabin37, 2023-12-16:
Oh ! You re right ! I ´ve forgotten to put it! Now it s perfect ! Thanks for remind me this :)GabinLe 16 déc. 2023 à 19:55, John ***@***.***> a écrit :

mounted

Is the white spacer in there. It should still be okay with the spacer, even though it's cut a bit short.

—Reply to this email directly, view it on GitHub, or unsubscribe.You are receiving this because you authored the thread.Message ID: ***@***.***>

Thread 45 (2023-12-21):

Powering with a DC power supply

Gabin37, 2023-12-21:
Hi,

where do I connect the DC power supply on the Keypad, cause I can't see any hole for plugin it?
Thanks for your help :)

Regards,

Gabin

Gabin37, 2023-12-23:
Nobody? :)

realA10001986, 2023-12-23:
Look at the back, there are two green plugs. One for 5V, one for 12-20V.

Closed 2024-01-05.

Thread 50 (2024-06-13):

do the displays light up when initially powered on?

eric1172, 2024-06-13:

CircuitSetup, 2024-08-16:
I believe your question was answered elsewhere, but they will take a couple seconds to come on when initially getting power. There is a "fake power" feature that allows them to come on with the startup sound via a switch. More details here: https://github.com/CircuitSetup/Time-Circuits-Display?tab=readme-ov-file#fake-power-switch

Closed 2024-08-16.

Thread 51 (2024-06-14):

Enter button is not working.

FluxPower142, 2024-06-14:
Hello, I just received and assembled my time circuits display for the first time. The numbers on the keypad work but the enter button is not working or not even lighting up, is there something I’m missing or forgetting or is it faulty or broken?

CircuitSetup, 2024-06-14:
I'm sorry it's giving you trouble. Is this with the keypad assembled, or when pressing the red button outside of the keypad housing, it does nothing?

CircuitSetup, 2024-06-14:
Please open a support ticket on circuitsetup.us and we'll fix whatever is going on or get you a new control board.

FluxPower142, 2024-06-14:
I submitted one

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

Closed 2024-07-30.

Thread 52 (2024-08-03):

Car mode and BTTFN connection issue

gullwing12, 2024-08-03:
Have several other props in my vehicle with the TCD. TCD has been placed into car mode and BTTFN IP address has been updated to 192.168.4.1for each prop.  Now when displaying the connected devices via the TCD BTTFN clients it shows no connected devices found. If the TCD is connected to my home network then there are no issues connecting the props to each other via the BTTFN. Am I missing anything? Is there something other than the BTTFN IP address that needs to be changed when in car mode?

gullwing12, 2024-08-03:
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

realA10001986, 2024-08-04:
The props need to connect to the TCD-AP WiFi network. I don't know in what WiFi mode the props are, probably in AP mode, so there is probably a SID-AP, FC-AP, DG-AP... WiFI network. Connect your computer/hand-held to the FC-AP (for example) WiFi network, navigate to 192.168.4.1 (which is the props IP address in AP mode), click on WiFi configuration, and connect the prop to the TCD-AP WiFi network.

gullwing12, 2024-08-04:
Thanks working now

Closed 2024-08-04.

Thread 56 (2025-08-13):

3d files and readme consistency

CladStriffe, 2025-08-13:
Hello

It seems the most up to date is circuitsetup_time_circuits_display.3mf (all parts on several plates).
But the last time enclosure 2.5.3 available is not the same (rectangular hole for the keypad connection and 3 screws instead of 4).

What are the preferred versions : keypad body and last time enclosure with 4 screws ?
It seems more robust indeed, can you clarify in readme please ?

Thanks for your hard work.

CircuitSetup, 2025-08-15:
It looks like I forgot to upload the latest versions of the display enclosures. They are now posted: https://github.com/CircuitSetup/Time-Circuits-Display/tree/master/Hardware/3d%20Files

I updated the readme as well.

CladStriffe, 2025-08-21:
Thanks, it looks good now.

Closed 2025-08-21.

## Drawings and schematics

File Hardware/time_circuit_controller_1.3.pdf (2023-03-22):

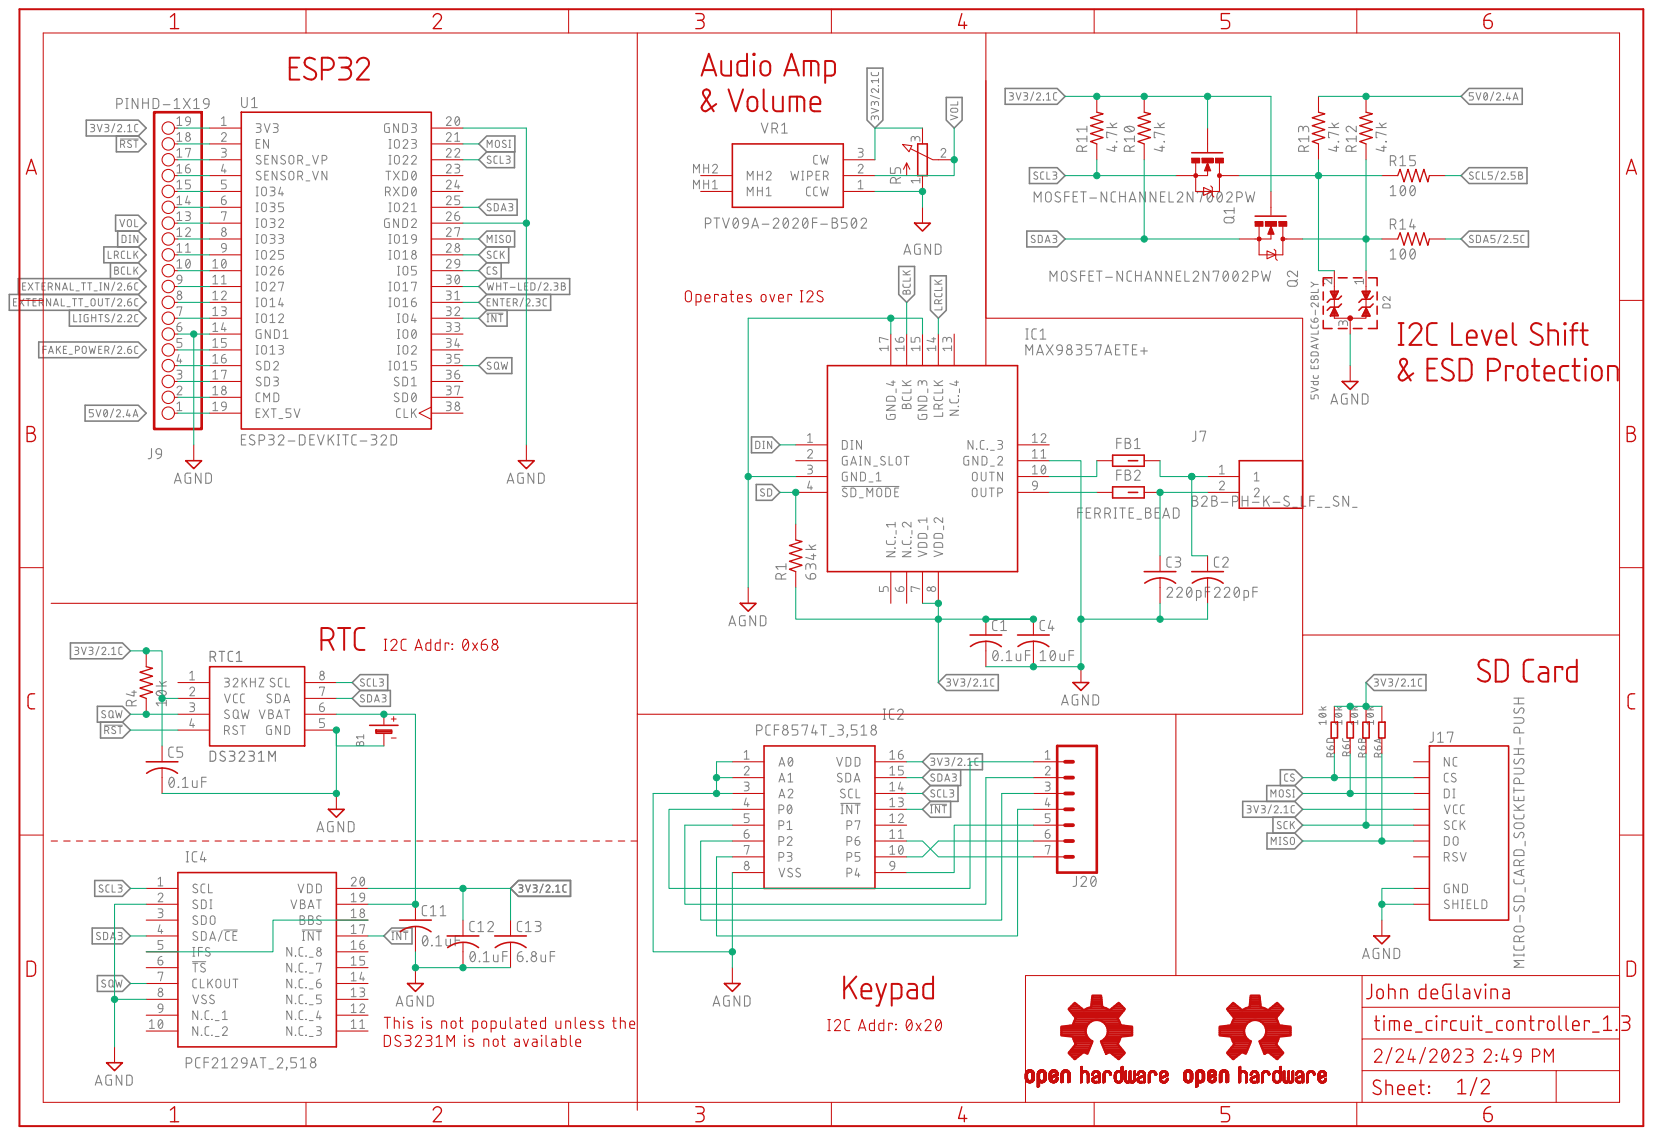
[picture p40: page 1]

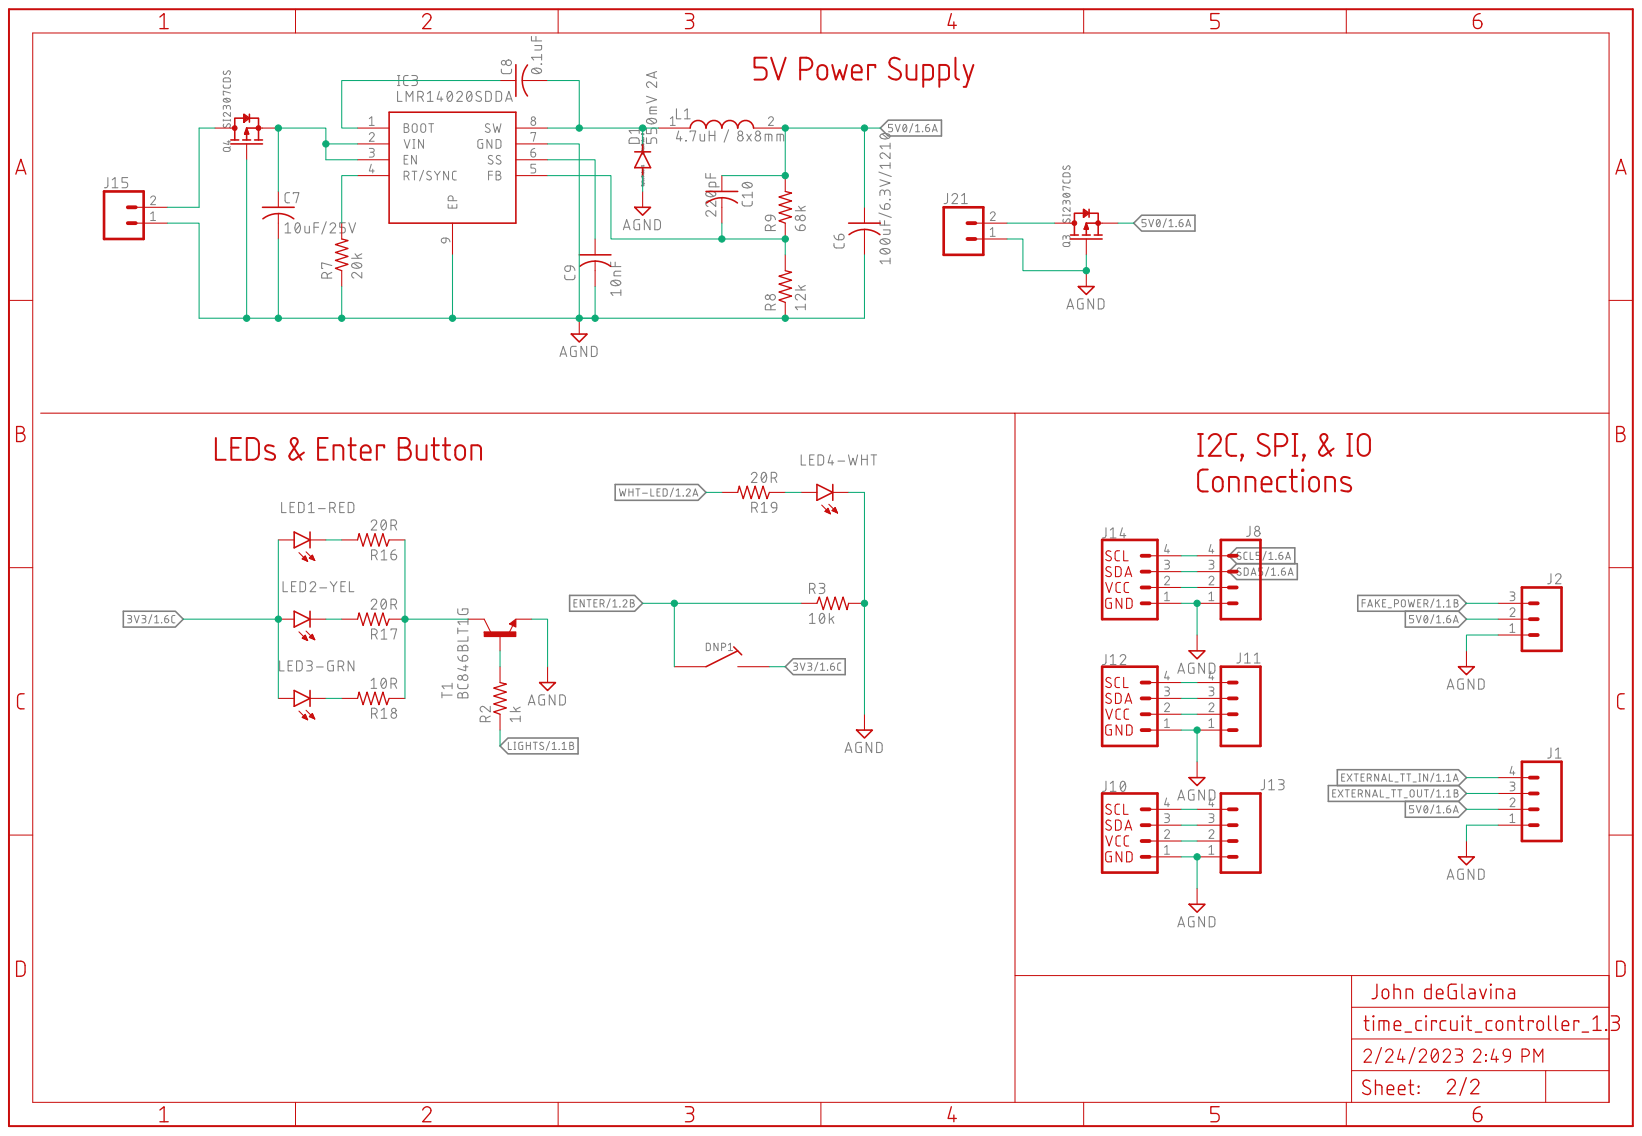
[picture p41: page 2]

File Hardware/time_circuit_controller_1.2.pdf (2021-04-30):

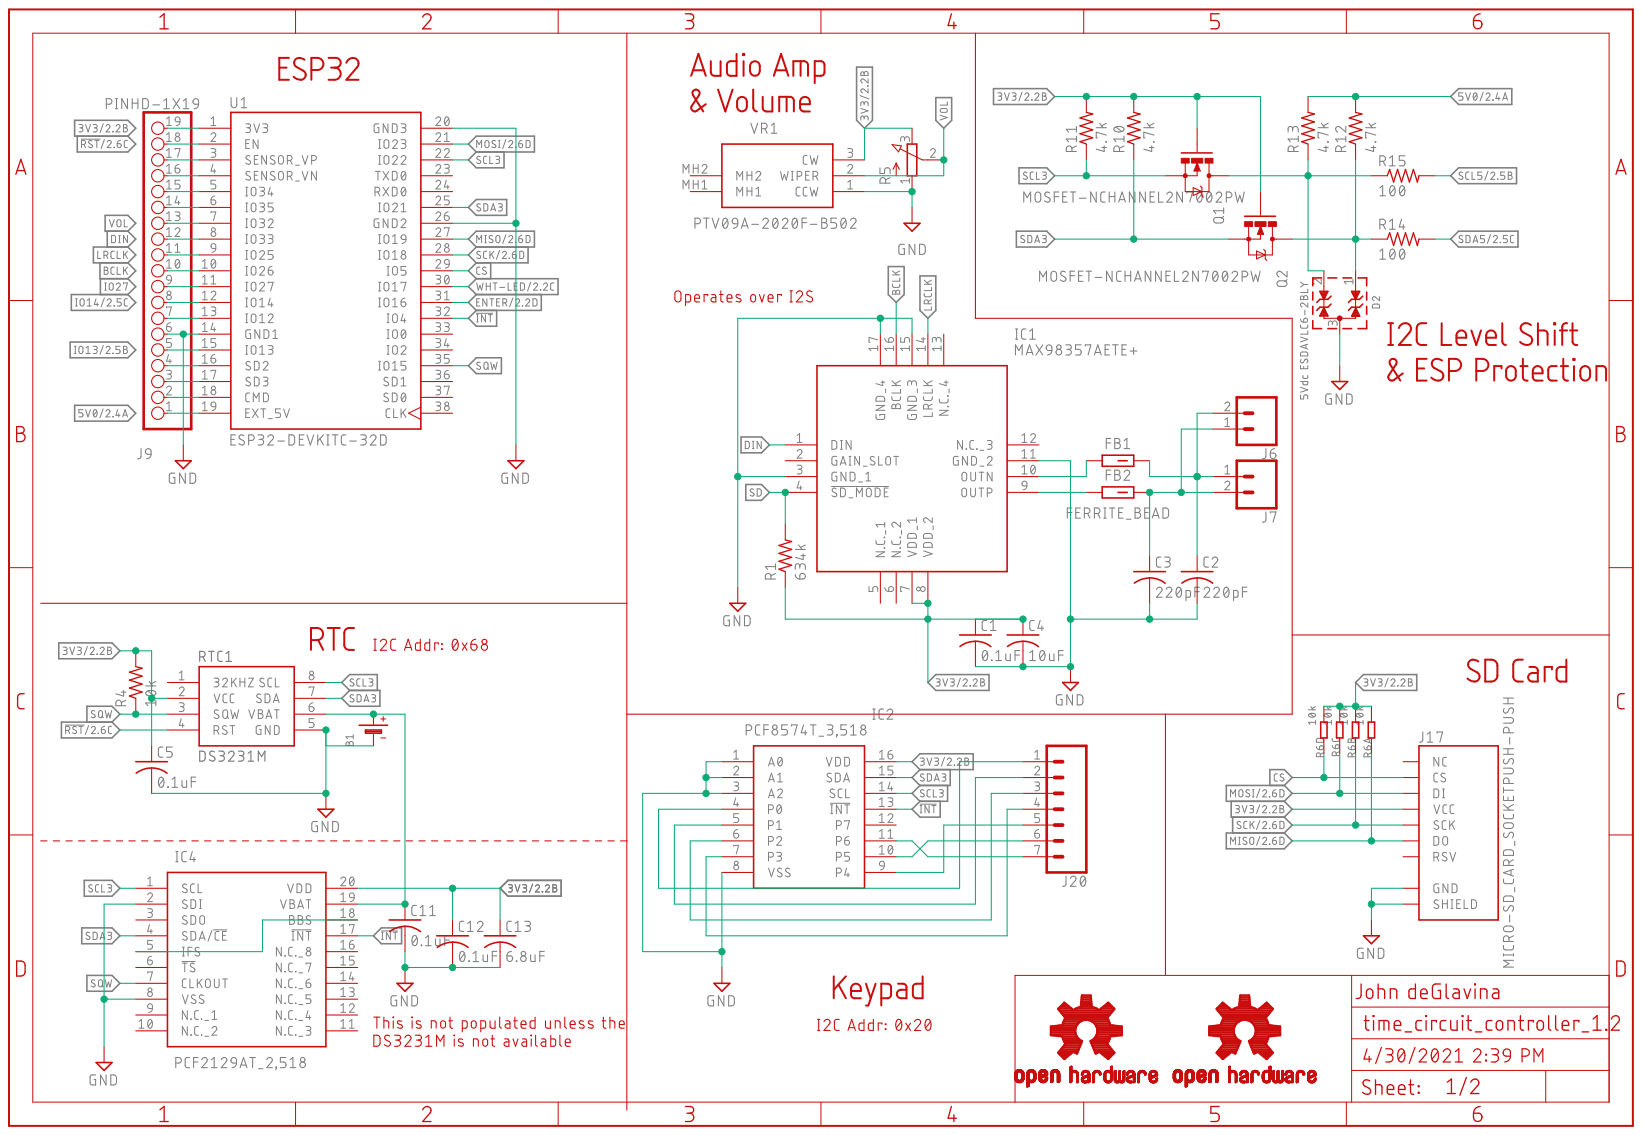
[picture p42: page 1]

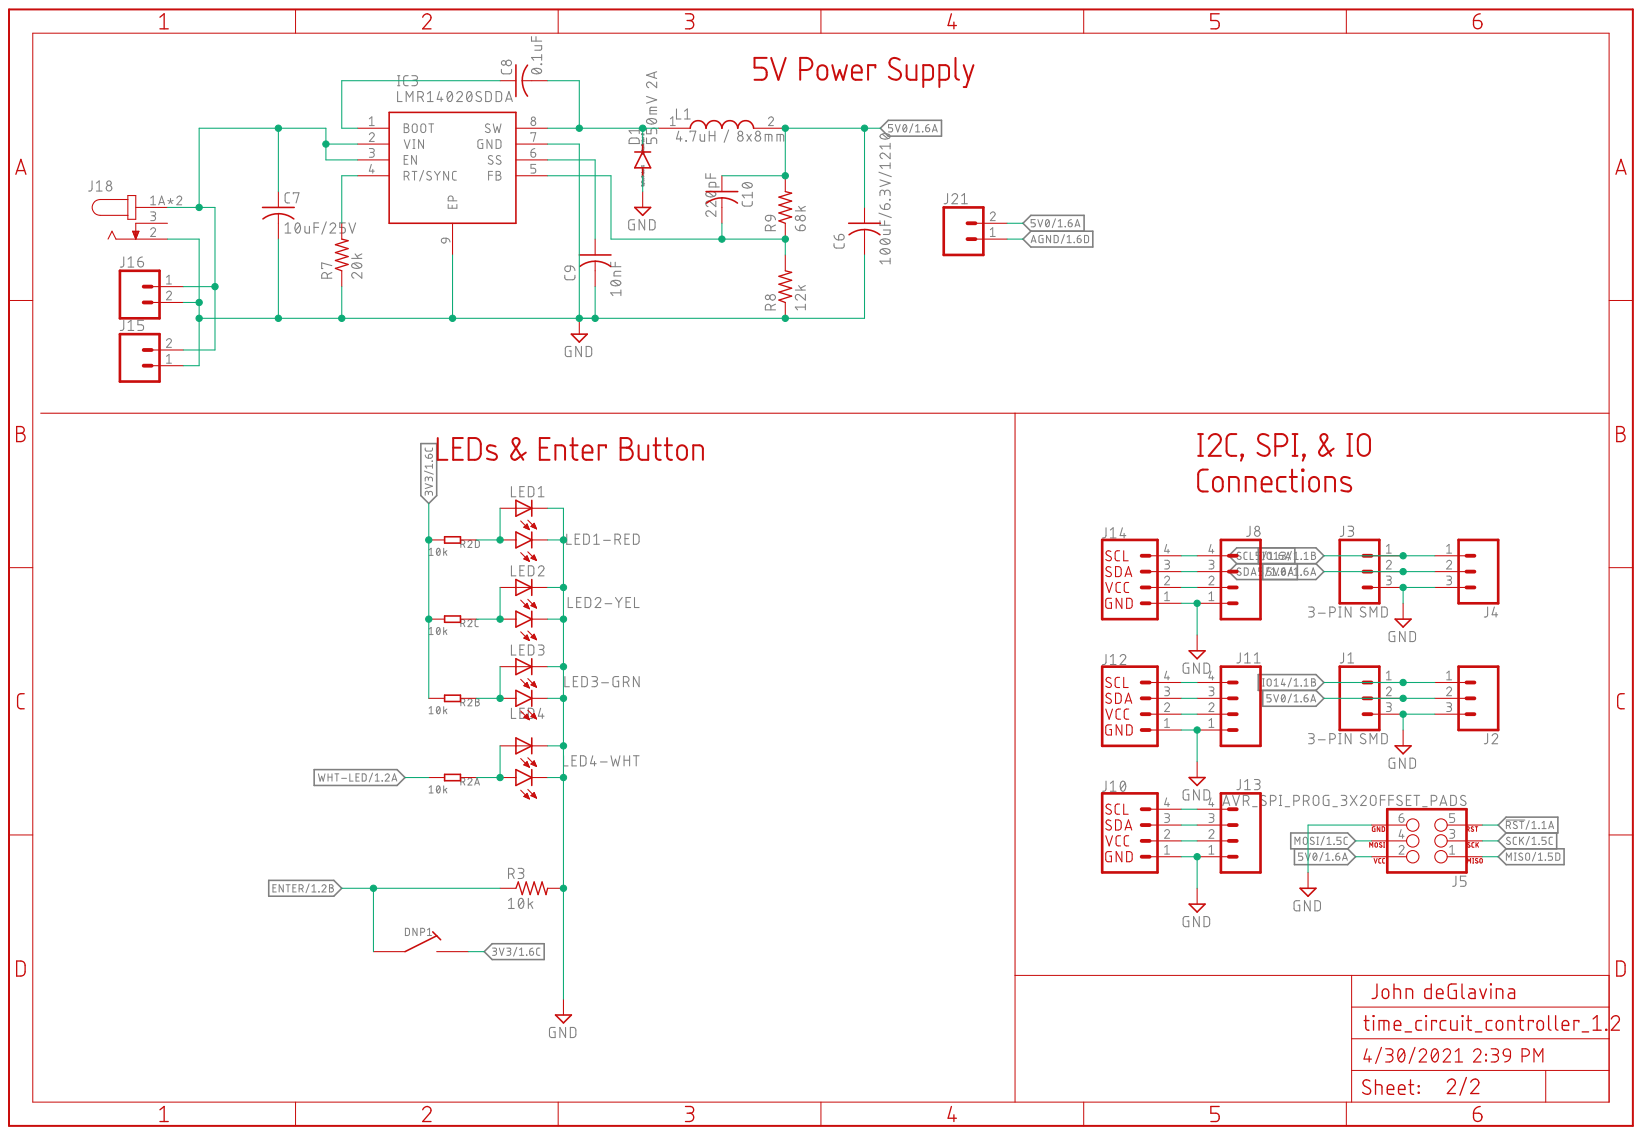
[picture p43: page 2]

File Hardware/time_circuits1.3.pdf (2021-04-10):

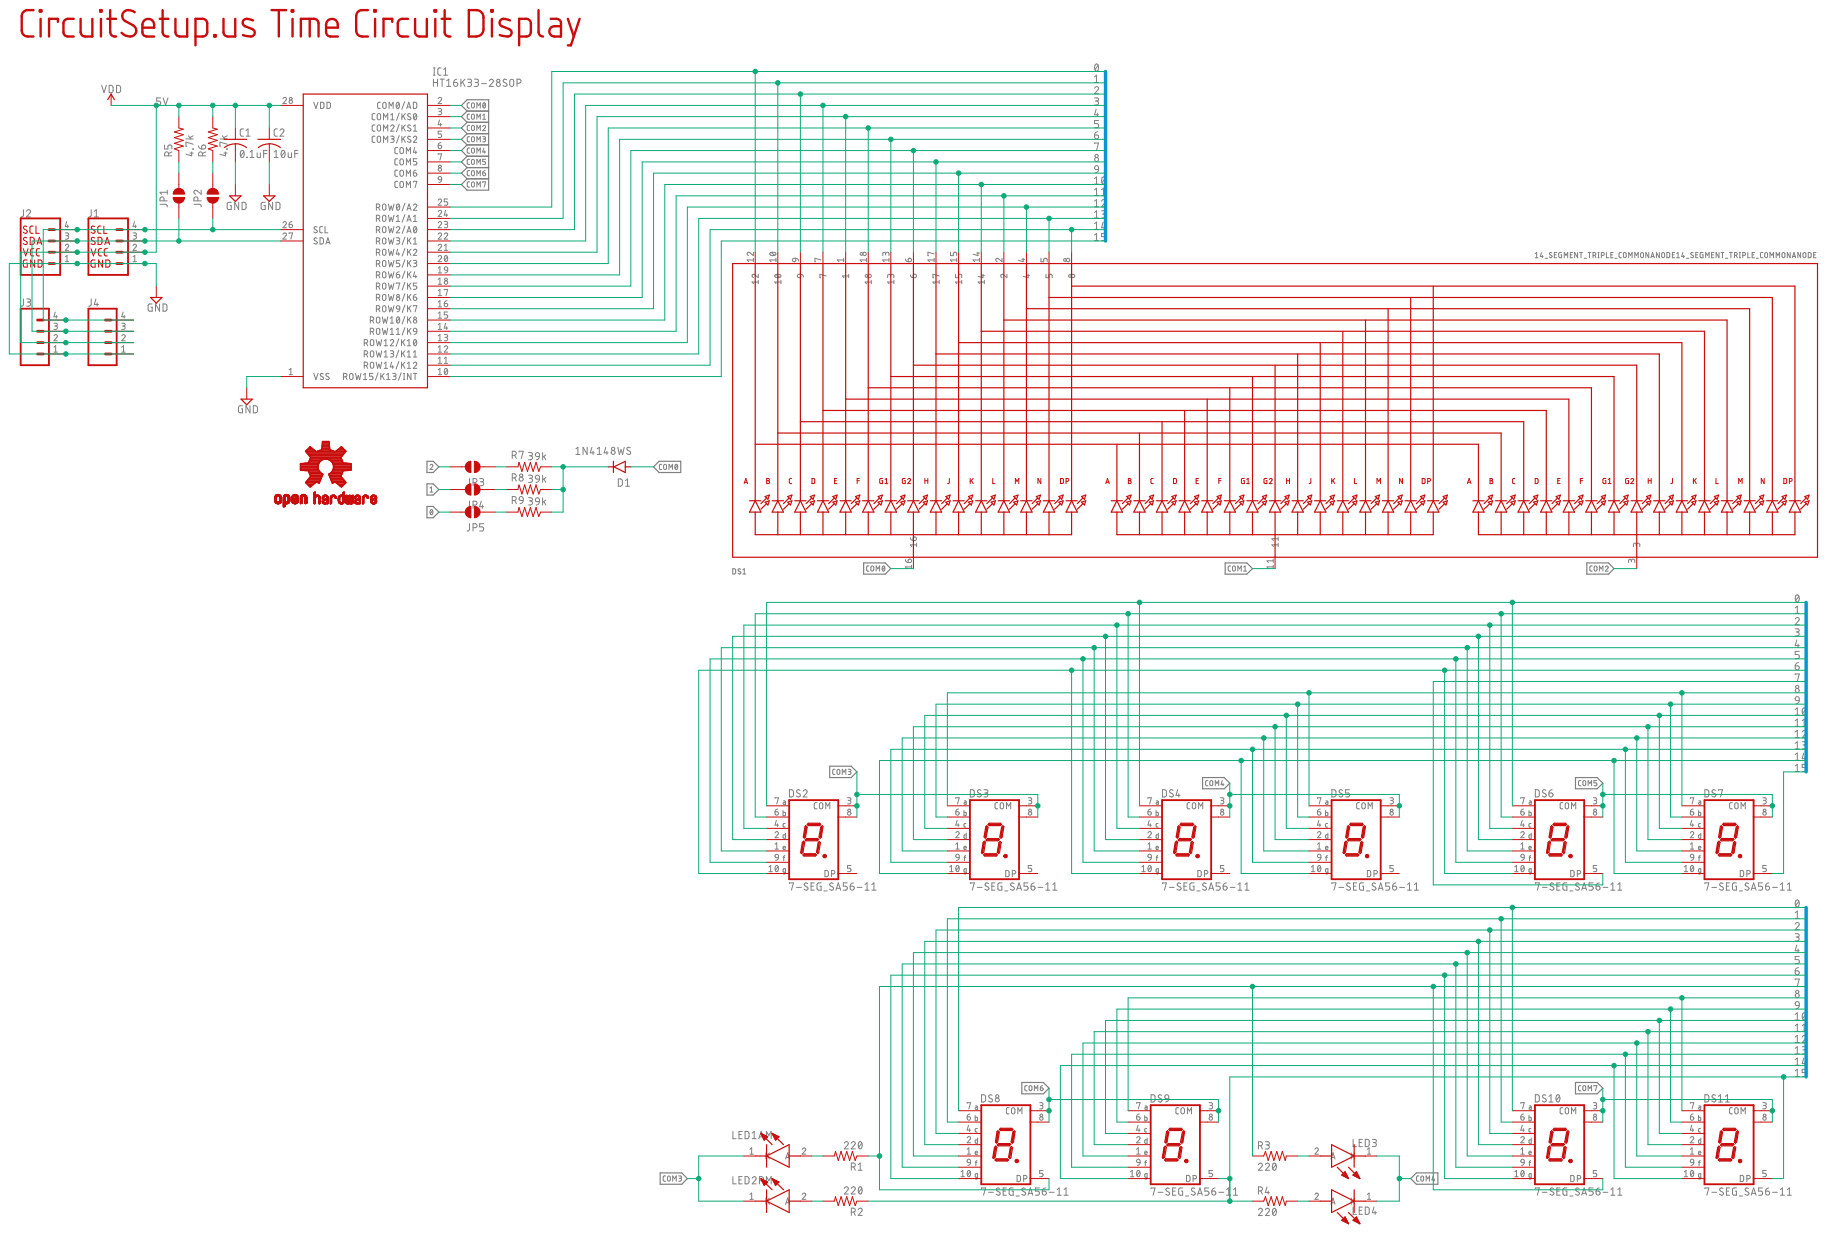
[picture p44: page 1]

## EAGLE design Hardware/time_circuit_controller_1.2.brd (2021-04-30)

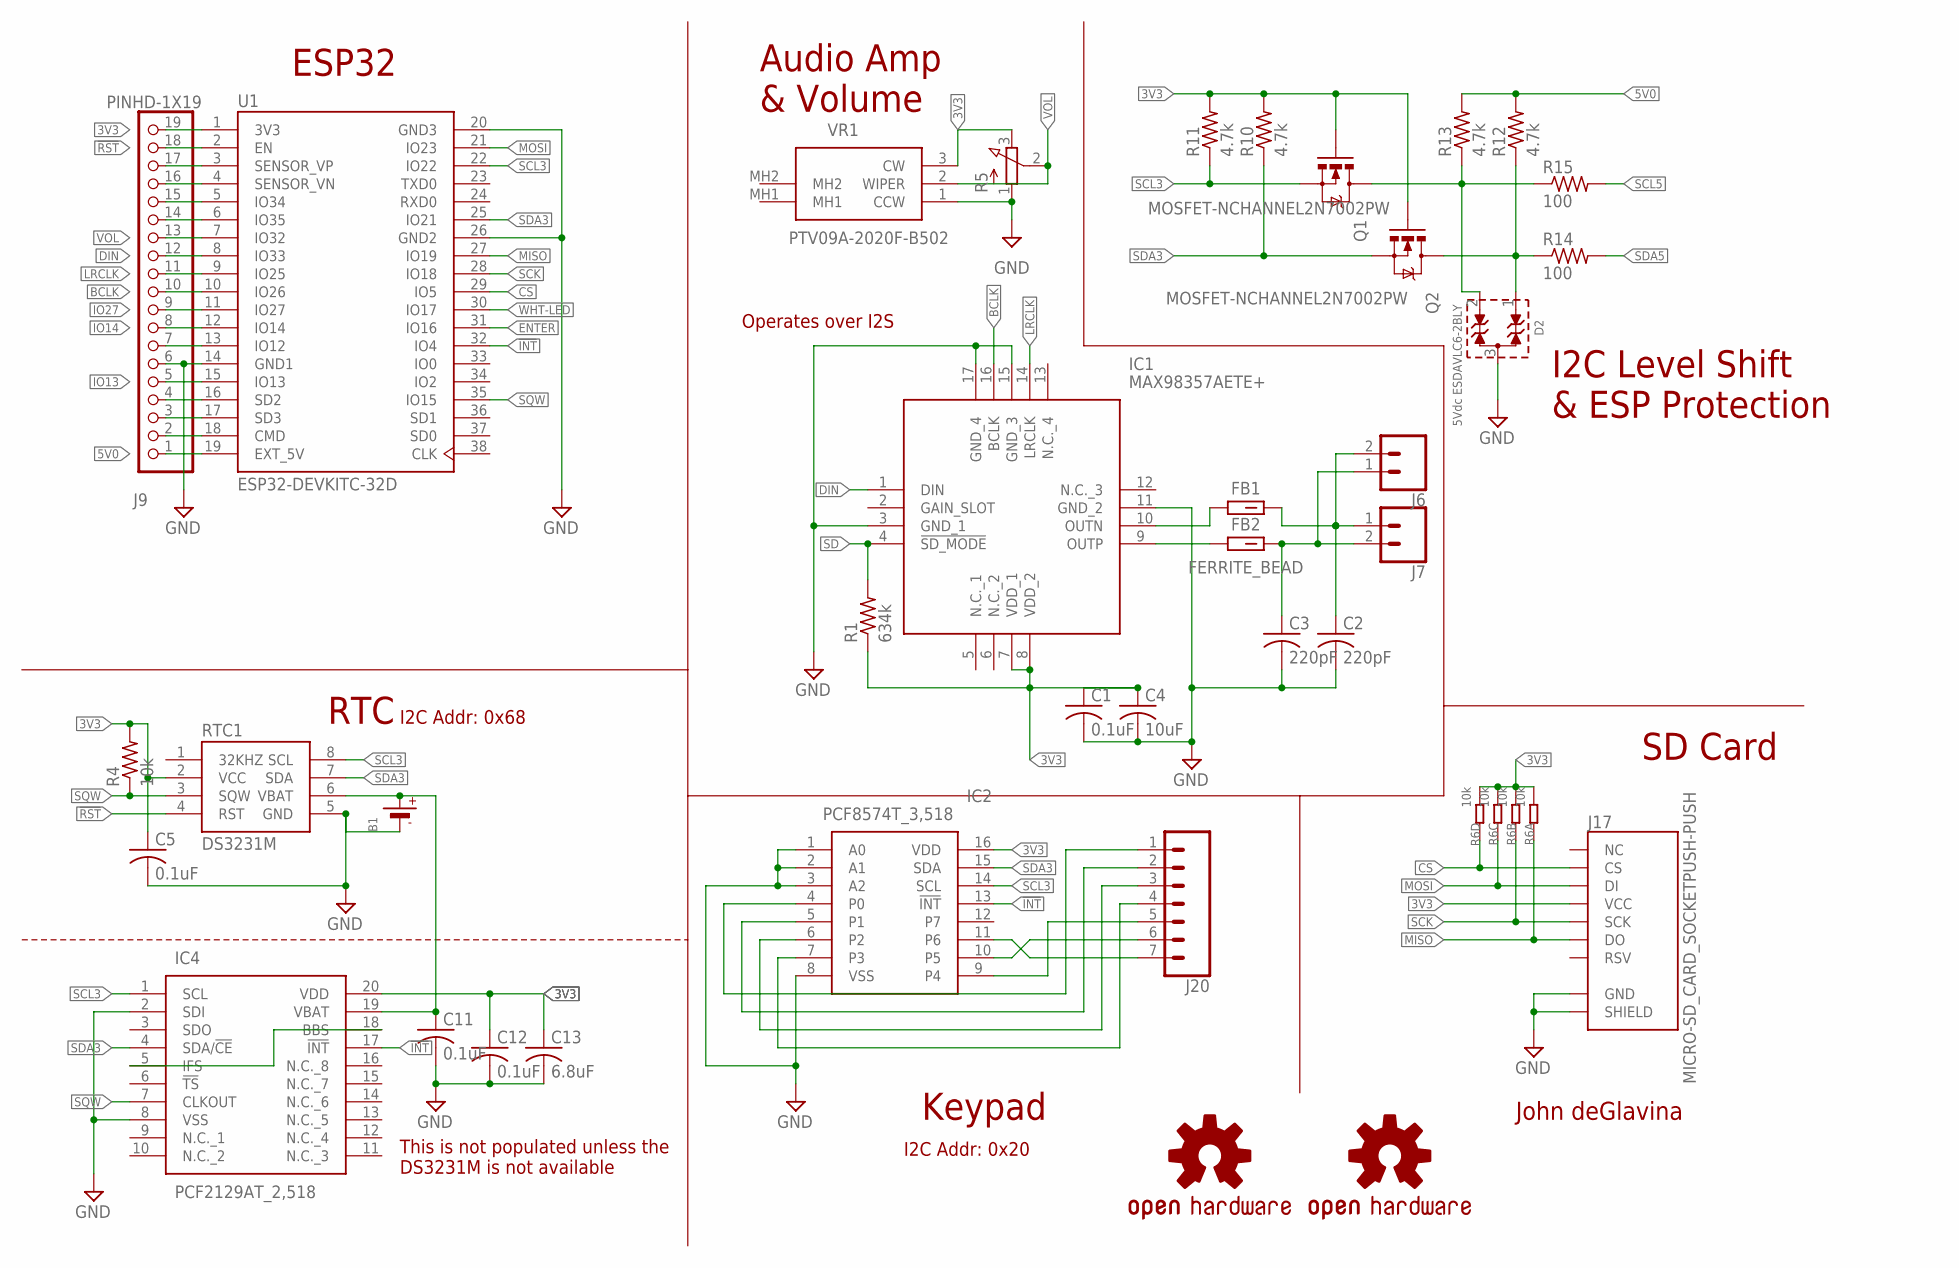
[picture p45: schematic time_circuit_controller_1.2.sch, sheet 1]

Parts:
B1: BATTERYCR2032_BAT-HLD-001; CR2032_SMT_BAT-HLD-001
C1, C5, C11, C12: 0.1uF; C0603
C2, C3: 220pF; C0603
C4: 10uF; C0603
C13: 6.8uF; C0603
D2: 5Vdc ESDAVLC6-2BLY; WE-TVS_SOT23-3L
FB1, FB2: FERRITE_BEAD; BEADC1608X95N
IC1: MAX98357AETE+; QFN50P300X300X80-17N
IC2: PCF8574T_3,518; SOIC127P1032X265-16N
IC4: PCF2129AT_2,518; SOIC127P1032X265-20N
J6: CONN_02-JST-2MM-SMT; JST-2-SMD
J7: CONN_02; 1X02
J9: PINHD-1X19; 1X19
J17: MICRO-SD_CARD_SOCKETPUSH-PUSH; MICRO-SD-SOCKET
J20: CONN_07LOCK; 1X07_LOCK
LOGO1, LOGO2: OSHW-LOGOL; OSHW-LOGO-L
Q1, Q2: MOSFET-NCHANNEL2N7002PW; SOT323
R1: 634k; R0603
R4: 10k; R0603
R5: 3RP/1610N
R6: 10k; RA1206-8
R10, R11, R12, R13: 4.7k; R0603
R14, R15: 100; R0603
RTC1: DS3231M; SO08
U1: ESP32-DEVKITC-32D; MODULE_ESP32-DEVKITC-32D
VR1: PTV09A-2020F-B502; PTV09A2020FB502

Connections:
3V3: C1.1, C4.1, C5.1, C12.1, C13.1, IC1.7 (VDD_1), IC1.8 (VDD_2), IC2.16 (VDD), IC4.20 (VDD), J9.19, J17.VCC, Q1.1 (G), Q2.1 (G), R1.1, R4.2, R5.3 (E), R6.1, R6.2 (1), R6.3 (1), R6.4 (1), R10.2, R11.2, RTC1.2 (VCC), U1.1 (3V3), VR1.3 (CW); also elsewhere on the board
5V0: J9.1, R12.2, R13.2, U1.19 (EXT_5V); also elsewhere on the board
!INT: IC2.13 (!INT), IC4.17 (!INT), U1.32 (IO4)
!RST: J9.18, RTC1.4 (RST), U1.2 (EN); also elsewhere on the board
AGND: B1.-, C1.2, C2.2, C3.2, C4.2, C5.2, C11.2, C12.2, C13.2, D2.3 (GND), IC1.3 (GND_1), IC1.11 (GND_2), IC1.15 (GND_3), IC1.17 (GND_4), IC2.1 (A0), IC2.2 (A1), IC2.3 (A2), IC2.8 (VSS), IC4.2 (SDI), IC4.8 (VSS), J9.6, J17.CD1 (SHIELD), J17.GND, R5.1 (A), RTC1.5 (GND), U1.14 (GND1), U1.20 (GND3), U1.26 (GND2), VR1.1 (CCW); also elsewhere on the board
BCLK: IC1.16 (BCLK), J9.10, U1.10 (IO26)
CS: J17.CS, R6.5 (2), U1.29 (IO5)
DIN: IC1.1 (DIN), J9.12, U1.8 (IO33)
ENTER: U1.31 (IO16); also elsewhere on the board
IO13: J9.5, U1.15 (IO13); also elsewhere on the board
IO14: J9.8, U1.12 (IO14); also elsewhere on the board
IO27: J9.9, U1.11 (IO27)
LRCLK: IC1.14 (LRCLK), J9.11, U1.9 (IO25)
MISO: J17.DO, R6.8 (2), U1.27 (IO19); also elsewhere on the board
MOSI: J17.DI, R6.6 (2), U1.21 (IO23); also elsewhere on the board
unnamed: IC2.11 (P6), J20.7
unnamed: FB1.1, IC1.10 (OUTN)
unnamed: B1.+$1 (+), B1.+$2 (+), C11.1, IC4.19 (VBAT), RTC1.6 (VBAT)
unnamed: IC2.4 (P0), J20.1
unnamed: IC2.9 (P4), J20.5
unnamed: J9.15, U1.5 (IO34)
unnamed: IC4.5 (IFS), IC4.18 (BBS)
unnamed: FB2.1, IC1.9 (OUTP)
unnamed: IC2.5 (P1), J20.2
unnamed: IC2.6 (P2), J20.3
unnamed: IC2.7 (P3), J20.4
unnamed: J9.14, U1.6 (IO35)
unnamed: IC2.10 (P5), J20.6
unnamed: J9.16, U1.4 (SENSOR_VN)
unnamed: J9.17, U1.3 (SENSOR_VP)
unnamed: J9.7, U1.13 (IO12)
unnamed: J9.4, U1.16 (SD2)
unnamed: J9.3, U1.17 (SD3)
unnamed: J9.2, U1.18 (CMD)
OUTN: C2.1, FB1.2, J6.2 (1), J7.1
OUTP: C3.1, FB2.2, J6.1 (2), J7.2
SCK: J17.SCLK (SCK), R6.7 (2), U1.28 (IO18); also elsewhere on the board
SCL3: IC2.14 (SCL), IC4.1 (SCL), Q1.2 (S), R11.1, RTC1.8 (SCL), U1.22 (IO22)
SCL5: R15.2; also elsewhere on the board
SD: IC1.4 (!SD_MODE), R1.2
SDA3: IC2.15 (SDA), IC4.4 (SDA/!CE), Q2.2 (S), R10.1, RTC1.7 (SDA), U1.25 (IO21)
SDA5: R14.2; also elsewhere on the board
SQW: IC4.7 (CLKOUT), R4.1, RTC1.3 (SQW), U1.35 (IO15)
VOL: J9.13, R5.2 (S), U1.7 (IO32), VR1.2 (WIPER)
WHT-LED: U1.30 (IO17); also elsewhere on the board
_SCL5: D2.2 (I/O2), Q1.3 (D), R13.1, R15.1
_SDA5: D2.1 (I/O1), Q2.3 (D), R12.1, R14.1

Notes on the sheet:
RTC
Keypad
SD Card
ESP32
I2C Level Shift & ESP Protection
Audio Amp & Volume
John deGlavina
This is not populated unless the DS3231M is not available
I2C Addr: 0x68
Operates over I2S
I2C Addr: 0x20

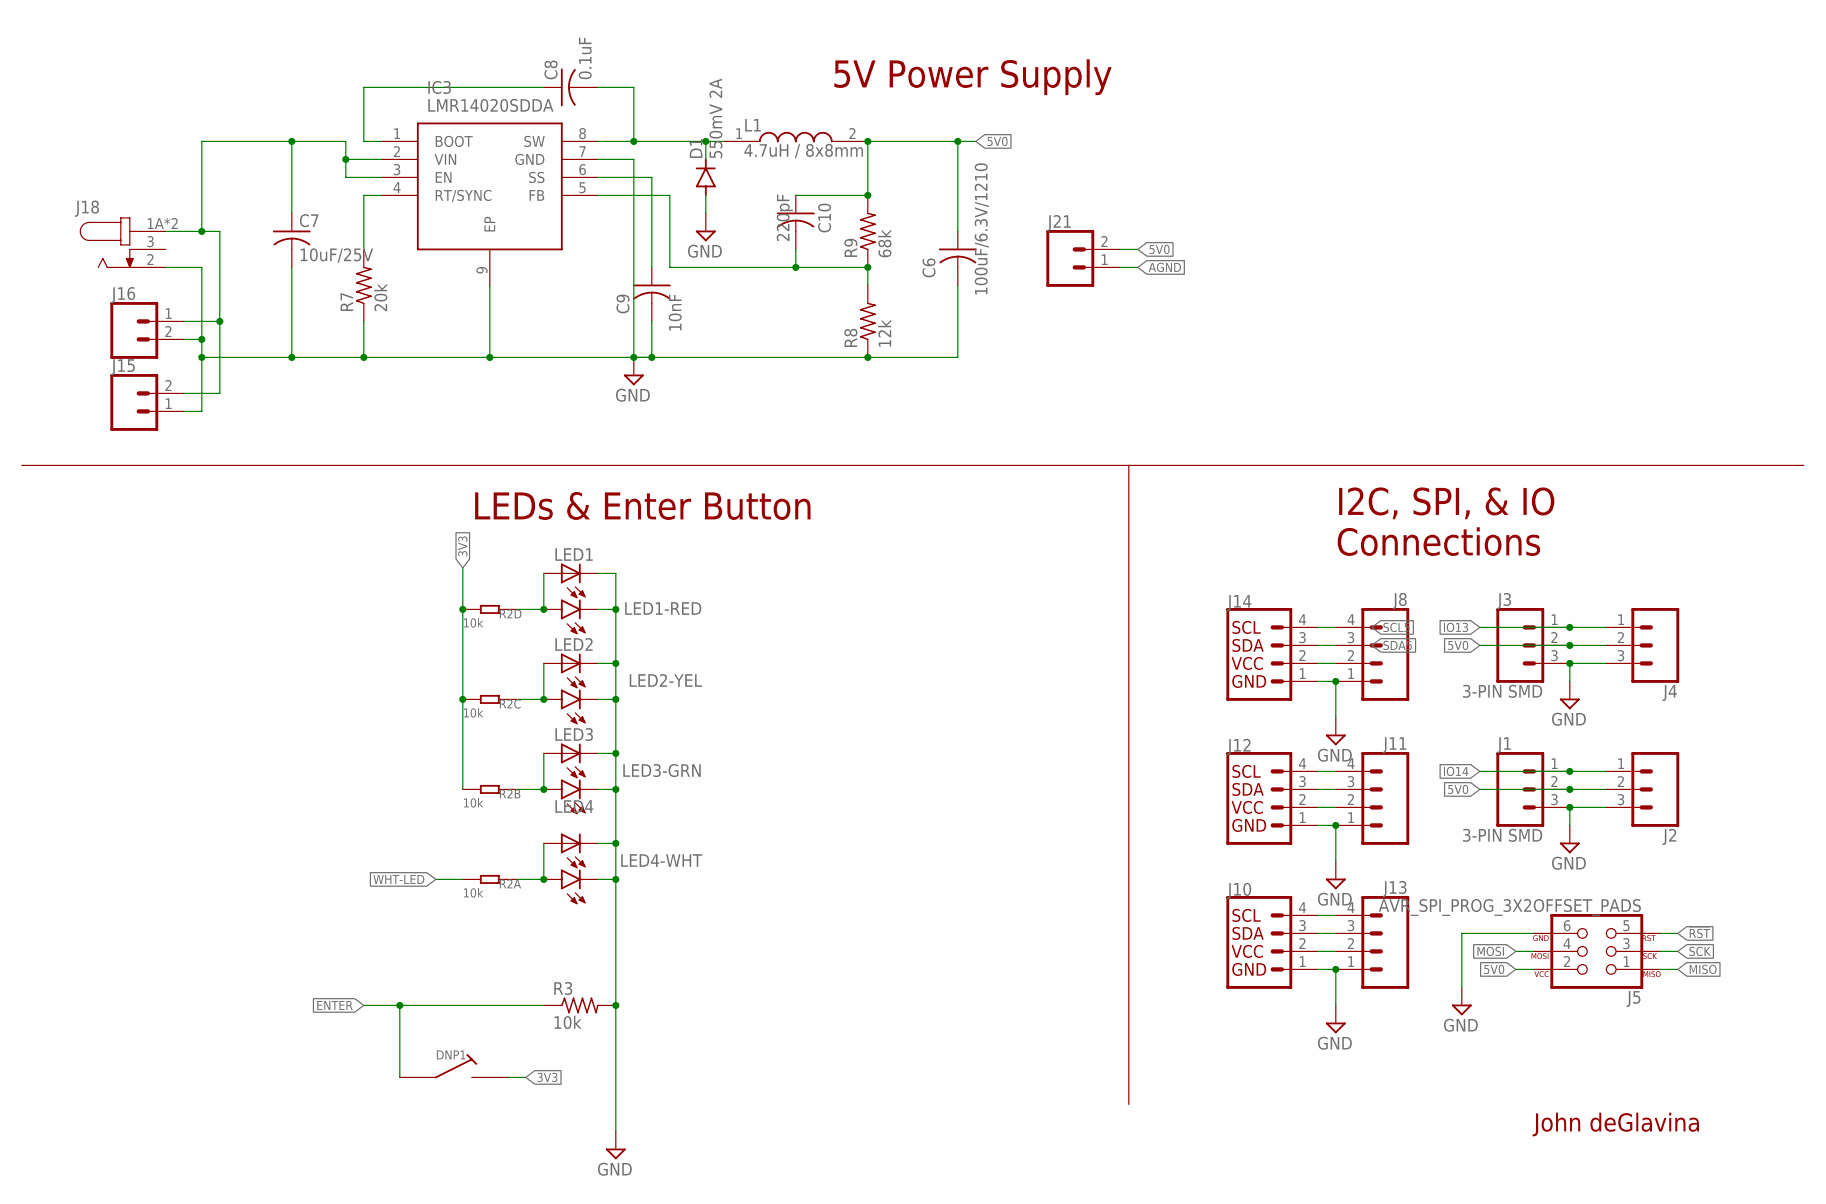
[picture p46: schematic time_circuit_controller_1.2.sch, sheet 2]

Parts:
C6: 100uF/6.3V/1210; C1210
C7: 10uF/25V; C0805
C8: 0.1uF; C0603
C9: 10nF; C0603
C10: 220pF; C0603
D1: 550mV 2A; DO214AC
DNP1: SWITCH-PINHEAD; PIN-1X2-3.5MM
IC3: LMR14020SDDA; SOIC127P600X170-9N
J1, J3: 3-PIN SMD; JST-3-SMD
J2, J4: CONN_03LOCK_LONGPADS; 1X03_LOCK_LONGPADS
J5: AVR_SPI_PROG_3X2OFFSET_PADS; 2X3_OFFSET
J8, J11, J13: CONN_04SMD_2.54; 1X04_5.5MM_STRAIGHT
J10, J12, J14: I2C_STANDARD; 1X04
J15, J21: CONN_023.5MM; SCREWTERMINAL-3.5MM-2
J16: CONN_02-JST-2MM-SMT; JST-2-SMD
J18: 9-12VAC; CUI_PJ-002AH-SMT-TR
L1: 4.7uH / 8x8mm; INDPM8082X300N
LED1, LED2, LED3, LED4: LEDCHIPLED_1206; CHIPLED_1206
LED1-RED, LED2-YEL, LED3-GRN, LED4-WHT: LED5MM
R2: 10k; RA1206-8
R3: 10k; R0603
R7: 20k; R0603
R8: 12k; R0603
R9: 68k; R0603

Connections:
3V3: DNP1.P$2 (2), R2.2 (1), R2.3 (1), R2.4 (1); also elsewhere on the board
5V0: C6.1, C10.1, J1.2, J2.2, J3.2, J4.2, J5.2, J8.2, J10.2, J11.2, J12.2, J13.2, J14.2, J21.2, L1.2, R9.2; also elsewhere on the board
!RST: J5.5; also elsewhere on the board
AGND: C6.2, C7.2, C9.2, D1.A, IC3.7 (GND), IC3.9 (EP), J1.3 (1), J2.3, J3.3 (1), J4.3, J5.6, J8.1, J10.1, J11.1, J12.1, J13.1, J14.1, J15.1, J16.2 (1), J18.2, J21.1, LED1.C, LED1-RED.K (C), LED2.C, LED2-YEL.K (C), LED3.C, LED3-GRN.K (C), LED4.C, LED4-WHT.K (C), R3.2, R7.1, R8.1; also elsewhere on the board
BOOT1: C8.1, IC3.1 (BOOT)
ENTER: DNP1.P$1 (1), R3.1; also elsewhere on the board
FB1: C10.2, IC3.5 (FB), R8.2, R9.1
IO13: J3.1 (3), J4.1; also elsewhere on the board
IO14: J1.1 (3), J2.1; also elsewhere on the board
MISO: J5.1; also elsewhere on the board
MOSI: J5.4; also elsewhere on the board
unnamed: LED1.A, LED1-RED.A, R2.5 (2)
unnamed: LED2.A, LED2-YEL.A, R2.6 (2)
unnamed: LED3.A, LED3-GRN.A, R2.7 (2)
unnamed: LED4.A, LED4-WHT.A, R2.8 (2)
RT1: IC3.4 (RT/SYNC), R7.2
SCK: J5.3; also elsewhere on the board
SCL5: J8.4, J10.4, J11.4, J12.4, J13.4, J14.4; also elsewhere on the board
SDA5: J8.3, J10.3, J11.3, J12.3, J13.3, J14.3; also elsewhere on the board
SS1: C9.1, IC3.6 (SS)
SW1: C8.2, D1.C, IC3.8 (SW), L1.1
VIN1: C7.1, IC3.2 (VIN), IC3.3 (EN), J15.2, J16.1 (2), J18.1A (1), J18.1B (1)
WHT-LED: R2.1; also elsewhere on the board

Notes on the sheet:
5V Power Supply
LEDs & Enter Button
I2C, SPI, & IO Connections
John deGlavina

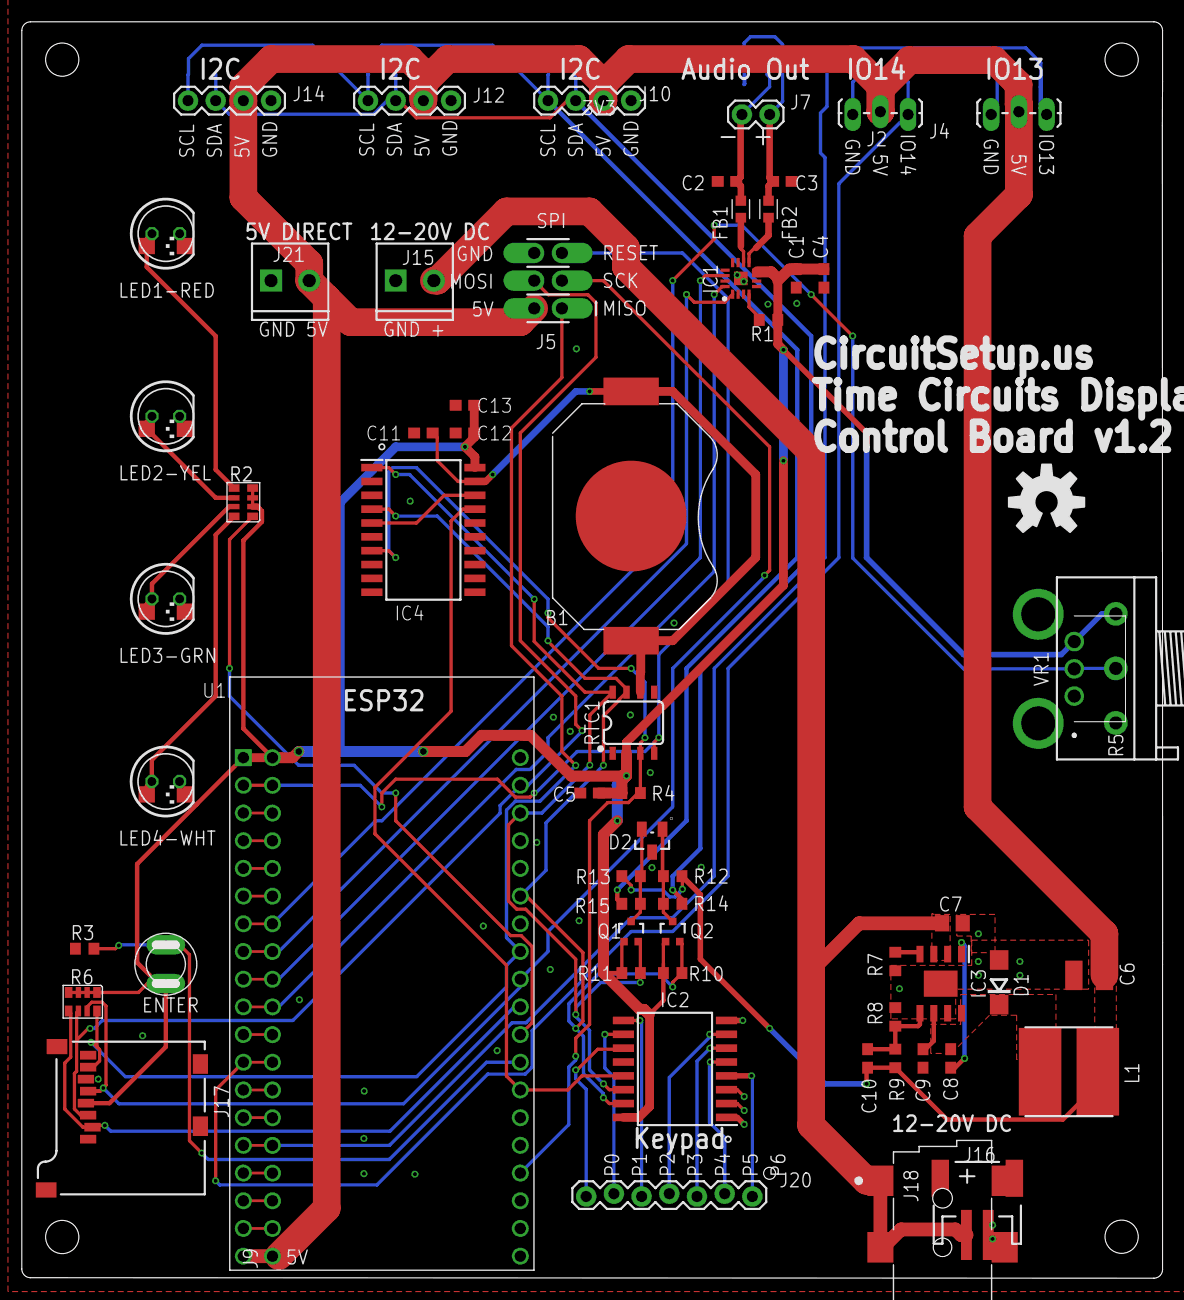
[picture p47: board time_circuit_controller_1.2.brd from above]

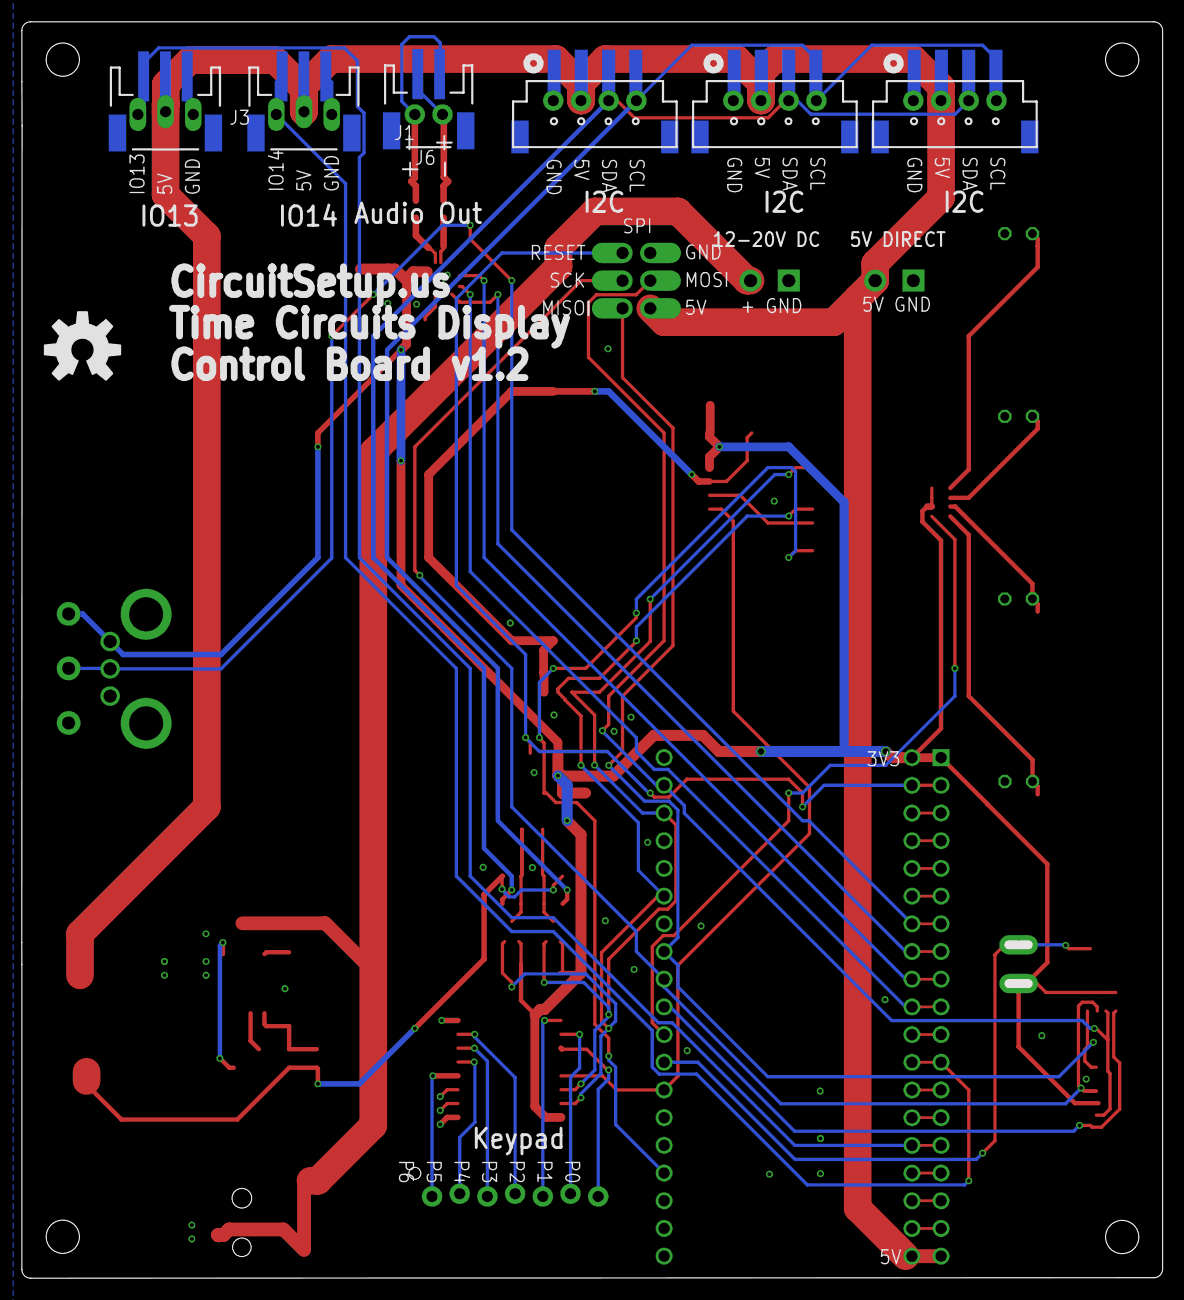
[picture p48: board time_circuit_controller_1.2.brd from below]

Board: 2 copper layers, 104.6 x 115.2 mm, 74 parts (7 on the bottom side), 57 nets.

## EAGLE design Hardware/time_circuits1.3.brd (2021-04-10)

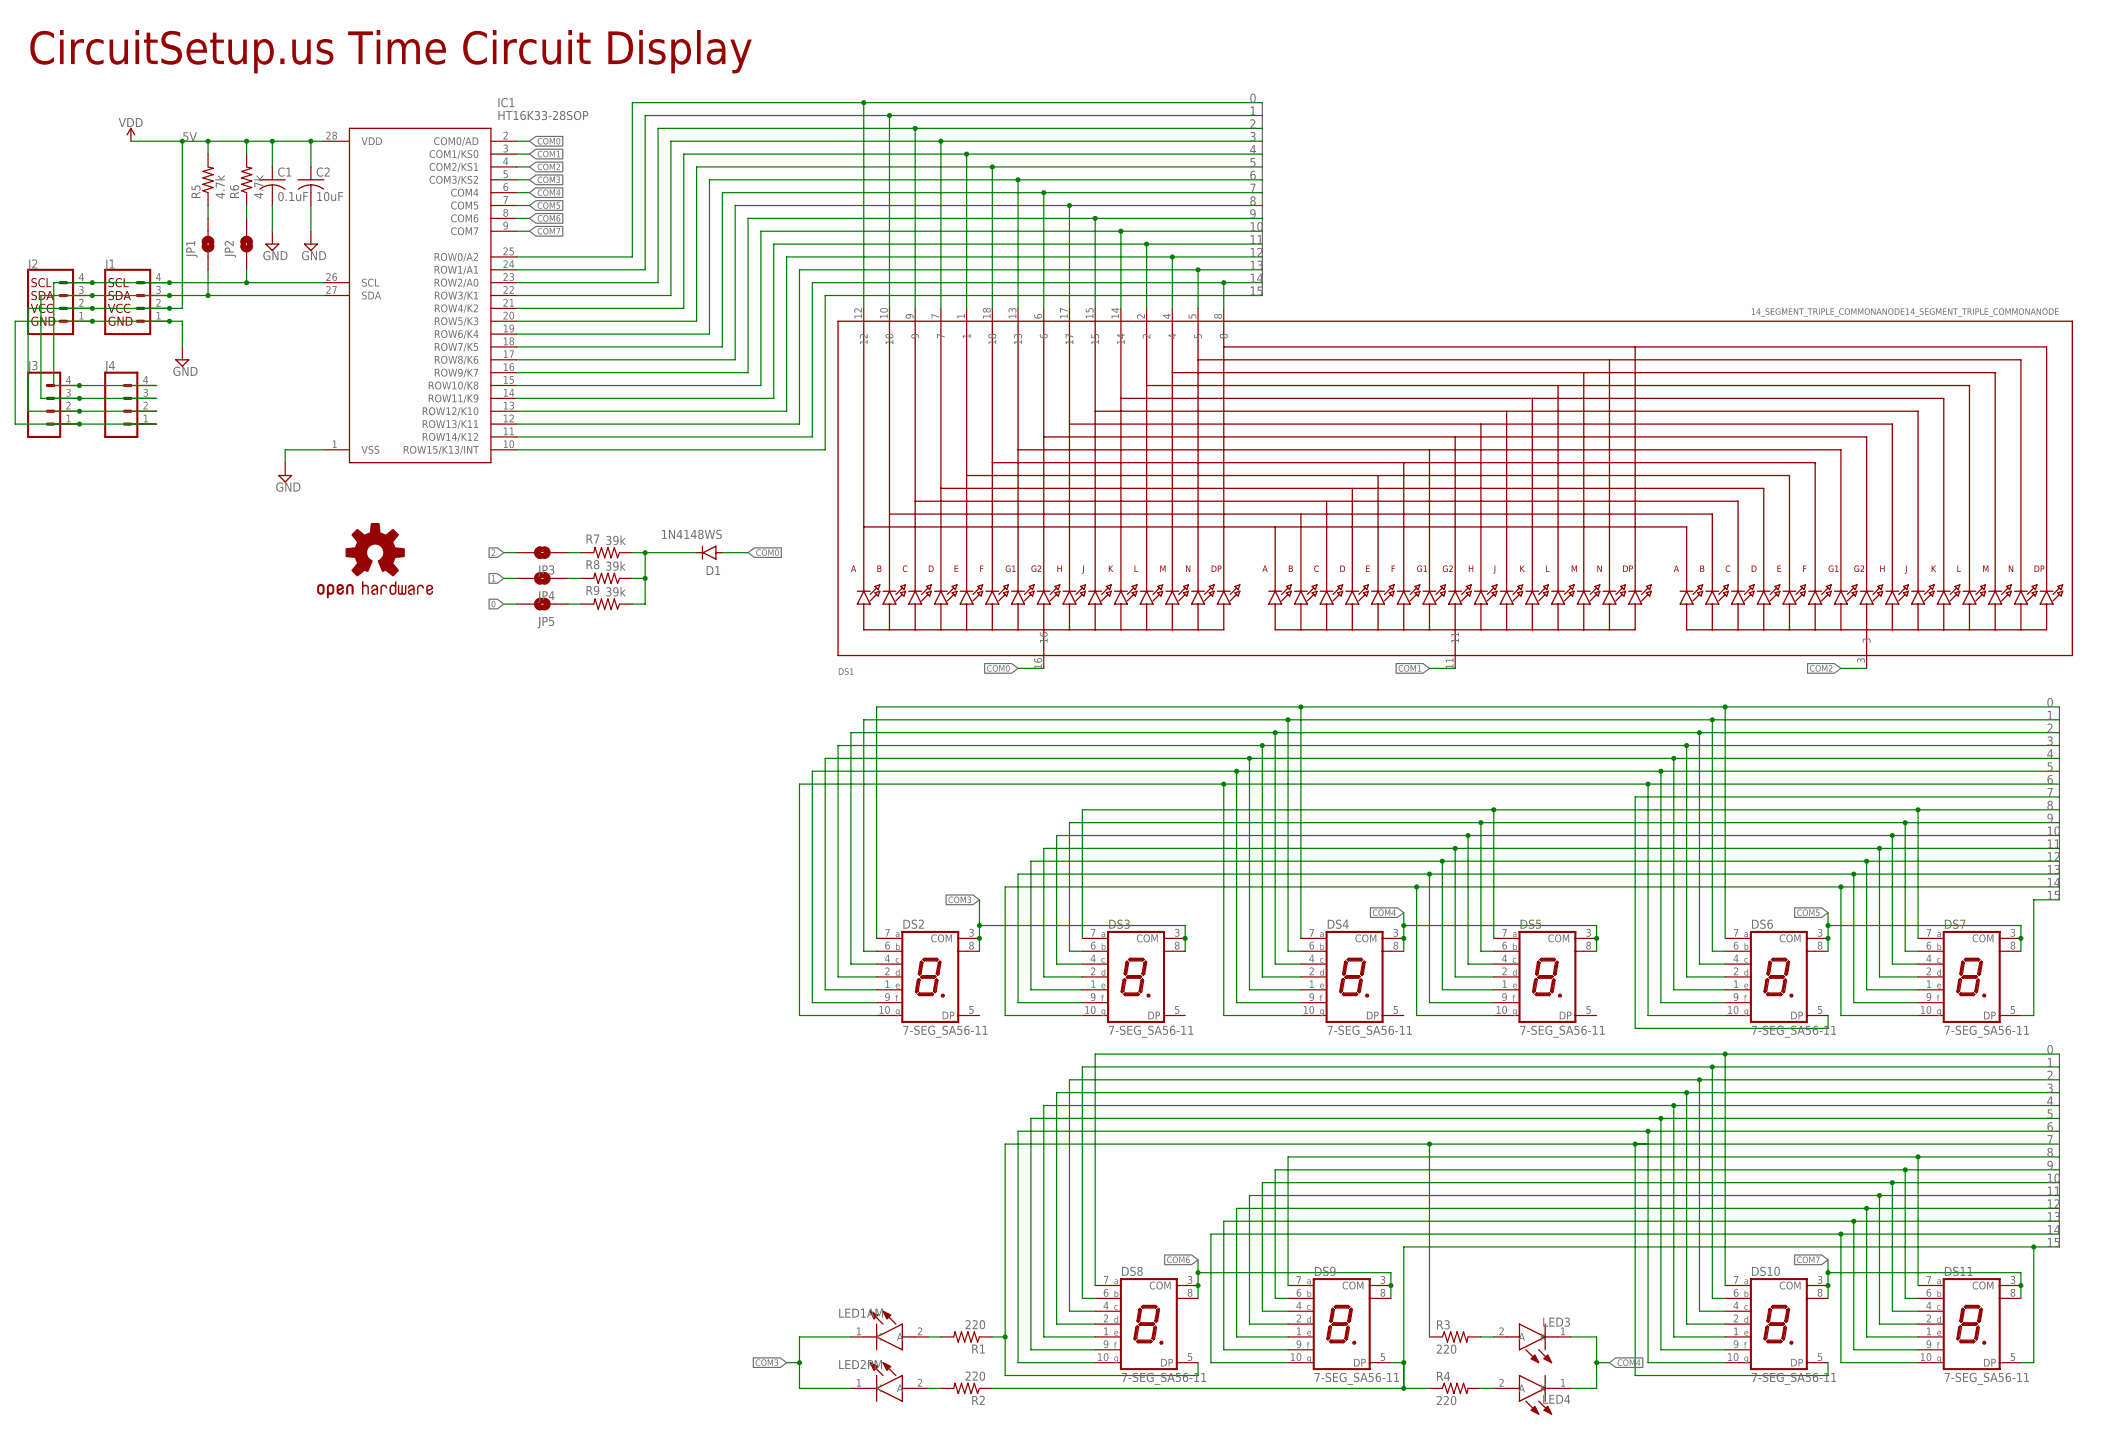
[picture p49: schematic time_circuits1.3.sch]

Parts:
C1: 0.1uF; C0603
C2: 10uF; C0603
D1: 1N4148WS; SOD-323
DS1: 14_SEGMENT_TRIPLE_COMMONANODE14_SEGMENT_TRIPLE_CO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; SEGMENT_TRIPLE_14
DS2, DS3, DS4, DS5, DS6, DS7, DS8, DS9, DS10, DS11: 7-SEG_SA56-11; SA56-11
IC1: HT16K33-28SOP; SOIC127P1031X264-28N
J1, J2: I2C_STANDARD; 1X04
J3, J4: CONN_04SMD_2.54; 1X04_5.5MM_STRAIGHT
JP1, JP2, JP3, JP4, JP5: JUMPER-SMT_2_NO_SILK; SMT-JUMPER_2_NO_SILK
LED1AM, LED2PM, LED3, LED4: WP132XGD
LOGO1: OSHW-LOGOL; OSHW-LOGO-L
R1, R2, R3, R4: 220; R0603
R5, R6: 4.7k; R0603
R7, R8, R9: 39k; R0603

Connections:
0: DS1.12, DS2.7 (A), DS4.7 (A), DS6.7 (A), DS8.7 (A), DS10.7 (A), IC1.25 (ROW0/A2), JP5.2
1: DS1.10, DS2.6 (B), DS4.6 (B), DS6.6 (B), DS8.6 (B), DS10.6 (B), IC1.24 (ROW1/A1), JP4.2
2: DS1.9, DS2.4 (C), DS4.4 (C), DS6.4 (C), DS8.4 (C), DS10.4 (C), IC1.23 (ROW2/A0), JP3.2
3: DS1.7, DS2.2 (D), DS4.2 (D), DS6.2 (D), DS8.2 (D), DS10.2 (D), IC1.22 (ROW3/K1)
4: DS1.1, DS2.1 (E), DS4.1 (E), DS6.1 (E), DS8.1 (E), DS10.1 (E), IC1.21 (ROW4/K2)
5: DS1.18, DS2.9 (F), DS4.9 (F), DS6.9 (F), DS8.9 (F), DS10.9 (F), IC1.20 (ROW5/K3)
5V: C1.1, C2.1, IC1.28 (VDD), J1.2, J2.2, J3.2, J4.2, R5.2, R6.2
6: DS1.13, DS2.10 (G), DS4.10 (G), DS6.10 (G), DS8.10 (G), DS10.10 (G), IC1.19 (ROW6/K4)
7: DS1.6, DS6.5 (DP), DS8.5 (DP), DS10.5 (DP), IC1.18 (ROW7/K5), R1.1, R3.1
8: DS1.17, DS3.7 (A), DS5.7 (A), DS7.7 (A), DS9.7 (A), DS11.7 (A), IC1.17 (ROW8/K6)
9: DS1.15, DS3.6 (B), DS5.6 (B), DS7.6 (B), DS9.6 (B), DS11.6 (B), IC1.16 (ROW9/K7)
10: DS1.14, DS3.4 (C), DS5.4 (C), DS7.4 (C), DS9.4 (C), DS11.4 (C), IC1.15 (ROW10/K8)
11: DS1.2, DS3.2 (D), DS5.2 (D), DS7.2 (D), DS9.2 (D), DS11.2 (D), IC1.14 (ROW11/K9)
12: DS1.4, DS3.1 (E), DS5.1 (E), DS7.1 (E), DS9.1 (E), DS11.1 (E), IC1.13 (ROW12/K10)
13: DS1.5, DS3.9 (F), DS5.9 (F), DS7.9 (F), DS9.9 (F), DS11.9 (F), IC1.12 (ROW13/K11)
14: DS1.8, DS3.10 (G), DS5.10 (G), DS7.10 (G), DS9.10 (G), DS11.10 (G), IC1.11 (ROW14/K12)
15: DS7.5 (DP), DS9.5 (DP), DS11.5 (DP), IC1.10 (ROW15/K13/INT), R2.1, R4.1
COM0: D1.A, DS1.16, IC1.2 (COM0/AD)
COM1: DS1.11, IC1.3 (COM1/KS0)
COM2: DS1.3, IC1.4 (COM2/KS1)
COM3: DS2.3 (COM), DS2.8 (COM), DS3.3 (COM), DS3.8 (COM), IC1.5 (COM3/KS2), LED1AM.1 (K), LED2PM.1 (K)
COM4: DS4.3 (COM), DS4.8 (COM), DS5.3 (COM), DS5.8 (COM), IC1.6 (COM4), LED3.1 (K), LED4.1 (K)
COM5: DS6.3 (COM), DS6.8 (COM), DS7.3 (COM), DS7.8 (COM), IC1.7 (COM5)
COM6: DS8.3 (COM), DS8.8 (COM), DS9.3 (COM), DS9.8 (COM), IC1.8 (COM6)
COM7: DS10.3 (COM), DS10.8 (COM), DS11.3 (COM), DS11.8 (COM), IC1.9 (COM7)
GND: C1.2, C2.2, IC1.1 (VSS), J1.1, J2.1, J3.1, J4.1
LED2: LED2PM.2 (A), R2.2
unnamed: JP1.2, R5.1
unnamed: JP2.2, R6.1
unnamed: JP3.1, R7.2
unnamed: JP4.1, R8.2
unnamed: JP5.1, R9.2
unnamed: D1.C, R7.1, R8.1, R9.1
unnamed: LED3.2 (A), R3.2
unnamed: LED4.2 (A), R4.2
unnamed: LED1AM.2 (A), R1.2
SCL: IC1.26 (SCL), J1.4, J2.4, J3.4, J4.4, JP2.1
SDA: IC1.27 (SDA), J1.3, J2.3, J3.3, J4.3, JP1.1

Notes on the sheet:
CircuitSetup.us Time Circuit Display

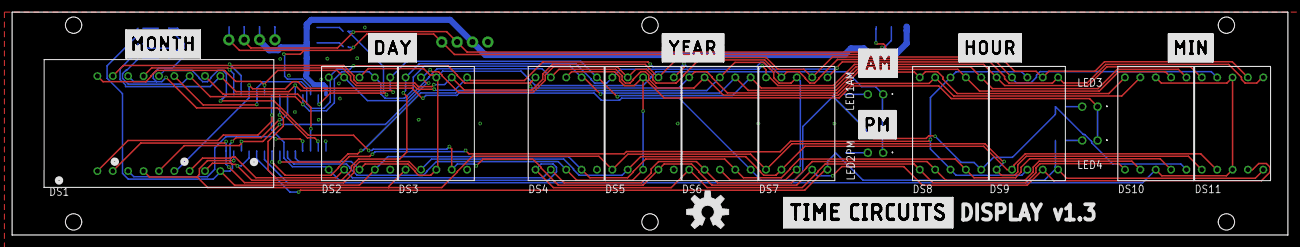
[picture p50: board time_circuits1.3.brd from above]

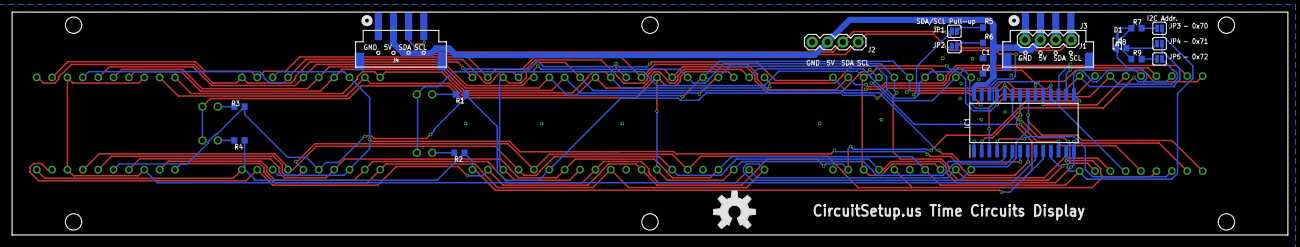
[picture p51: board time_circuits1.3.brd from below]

Board: 2 copper layers, 210.8 x 36.8 mm, 46 parts (23 on the bottom side), 38 nets.

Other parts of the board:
LOGO2: OSHW-LOGOL; OSHW-LOGO-L
U$1: MONTH
U$2: DAY
U$3: YEAR
U$4: HOUR
U$5: MIN
U$6: AM
U$7: PM

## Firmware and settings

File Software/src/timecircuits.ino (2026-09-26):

/*
 * -------------------------------------------------------------------
 * CircuitSetup.us Time Circuits Display
 * (C) 2021-2022 John deGlavina https://circuitsetup.us
 * (C) 2022-2026 Thomas Winischhofer (A10001986)
 * https://github.com/realA10001986/Time-Circuits-Display
 * https://tcd.out-a-ti.me
 *
 * -------------------------------------------------------------------
 * License: Modified MIT NON-AI
 * 
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
 * Links inside the Software pointing to the original source must not
 * be changed or removed.
 * 
 * In addition, the following restrictions apply:
 *
 * 1. The Software and any modifications made to it may not be used 
 * for the purpose of training or improving machine learning algorithms, 
 * including but not limited to artificial intelligence, natural 
 * language processing, or data mining. This condition applies to any 
 * derivatives, modifications, or updates based on the Software code. 
 * Any usage of the Software in an AI-training dataset is considered a 
 * breach of this License.
 *
 * 2. The Software may not be included in any dataset used for 
 * training or improving machine learning algorithms, including but 
 * not limited to artificial intelligence, natural language processing, 
 * or data mining.
 *
 * 3. Any person or organization found to be in violation of these 
 * restrictions will be subject to legal action and may be held liable 
 * for any damages resulting from such use.
 *
 * THE SOFTWARE IS PROVIDED "AS IS", WITHOUT WARRANTY OF ANY KIND, 
 * EXPRESS OR IMPLIED, INCLUDING BUT NOT LIMITED TO THE WARRANTIES OF 
 * MERCHANTABILITY, FITNESS FOR A PARTICULAR PURPOSE AND NONINFRINGEMENT. 
 * IN NO EVENT SHALL THE AUTHORS OR COPYRIGHT HOLDERS BE LIABLE FOR ANY 
 * CLAIM, DAMAGES OR OTHER LIABILITY, WHETHER IN AN ACTION OF CONTRACT, 
 * TORT OR OTHERWISE, ARISING FROM, OUT OF OR IN CONNECTION WITH THE 
 * SOFTWARE OR THE USE OR OTHER DEALINGS IN THE SOFTWARE.
 */

/*
 * Build instructions (for Arduino IDE)
 * 
 * - Install the Arduino IDE
 *   https://www.arduino.cc/en/software
 *    
 * - This firmware requires the "ESP32-Arduino" framework. To install this framework, 
 *   in the Arduino IDE, go to "File" > "Preferences" and add the URL   
 *   https://raw.githubusercontent.com/espressif/arduino-esp32/gh-pages/package_esp32_index.json
 *   - or (if the URL above does not work) -
 *   https://espressif.github.io/arduino-esp32/package_esp32_index.json
 *   to "Additional Boards Manager URLs". The list is comma-separated.
 *   
 * - Go to "Tools" > "Board" > "Boards Manager", then search for "esp32", and install 
 *   the latest 2.x version by Espressif Systems. Versions >=3.x are not supported.
 *   Detailed instructions for this step:
 *   https://docs.espressif.com/projects/arduino-esp32/en/latest/installing.html
 *   
 * - Go to "Tools" > "Board: ..." -> "ESP32 Arduino" and select your board model. For
 *   CircuitSetup original boards, select "NodeMCU-32S".
 *   
 * - If you want Arduino IDE to upload the firmware via USB (which is only required for
 *   fresh ESP32 boards; if a previous version of the firmware is installed on your
 *   board, you can update through the Config Portal and don't need an USB connection):
 *   
 *   Connect your ESP32 board using a suitable USB cable.
 *   
 *   Note that ESP32 boards come in two flavors that differ in which serial communications 
 *   chip is used: Either SiLabs CP210x or WCH CH340. CircuitSetup uses the CP210x.
 * 
 *   Mac:
 *   * CP210x: Since ca. 10.15.7, MacOS comes with a driver for the CP210x. For earlier 
 *     versions of MacOS, installing a driver is required:
 *     https://www.silabs.com/developers/usb-to-uart-bridge-vcp-drivers?tab=downloads
 *     The port ("Tools -> "Port" in Arduino IDE) is named 
 *     - /dev/cu.usbserial-xxxx when using the Apple driver, 
 *     - /dev/cu.SLAB_USBtoUART when using the SiLabs driver. 
 *     The maximum upload speed ("Tools" -> "Upload Speed" in Arduino IDE) can be used.
 *     Note: The SiLabs driver has a bug that affects TCD Control Boards V1.4 and later.
 *     Firmware uploads will fail ("No data received"). Use the Apple driver for those 
 *     boards.
 *   * CH340: This chip is supported out-of-the-box since Mojave. 
 *     The port ("Tools -> "Port" in Arduino IDE) is named /dev/cu.usbserial-XXXX, and 
 *     the maximum upload speed is 460800.
 * 
 *   Windows:
 *   * CP210x: Current Windows versions may come with a suitable driver. If the chip 
 *     is not recognized (ie no Port is created), a driver needs to be installed:
 *     https://www.silabs.com/developers/usb-to-uart-bridge-vcp-drivers?tab=downloads
 *   * CH340: Windows will install a driver when connecting the board; in case it 
 *     doesn't or it fails doing so, please install this driver:
 *     http://www.wch-ic.com/downloads/CH341SER_ZIP.html
 *     Note that the maximum upload speed for the CH340 is apparently 460800.
 *   After driver installation, connect your ESP32, start the Device Manager, expand 
 *   the "Ports (COM & LPT)" list and look for the port with the ESP32 name. Choose 
 *   this port under "Tools" -> "Port" in Arduino IDE.
 *
 * - Install required libraries. In the Arduino IDE, go to "Tools" -> "Manage Libraries" 
 *   and install the following library:
 *   - ArduinoJSON (>= 6.19): https://arduinojson.org/v6/doc/installation/
 *     (Versions 7 and on of this lib are much bigger, so it might happen that the 
 *     binary does not fit the ESP32's flash memory. Use v6 instead.)
 *
 * - Download the complete firmware source code:
 *   https://github.com/realA10001986/Time-Circuits-Display/archive/refs/heads/main.zip
 *   Extract this file somewhere. Enter the "timecircuits-A10001986" folder and 
 *   double-click on "timecircuits-A10001986.ino". This opens the firmware in the
 *   Arduino IDE.
 *
 * - For USB connected ESP32 boards: 
 *   Go to "Sketch" -> "Upload" to compile and upload the firmware to your ESP32 board.
 * - For OTA updates via the Config Portal:
 *   Go to "Sketch" -> "Export compiled Binary" to compile the firmware; a ".bin" file 
 *   is created in the source directory, which can then be uploaded through the Config
 *   Portal.
 *   
 * - Install the sound-pack: 
 *   - Go to Config Portal, click "Update & Upload" and upload the sound-pack (TCDA.bin,
 *     extracted from install/sound-pack-twXX.zip) through the bottom file selector.
 *     A FAT32 (not ExFAT!) formatted SD card must be present in the slot during this 
 *     operation.
 *   Alternatively:
 *   - Copy TCDA.bin to the top folder of a FAT32 (not ExFAT!) formatted SD card (max 
 *     32GB) and put this card into the slot while the TCD is powered down. 
 *   - Now power-up. The sound-pack will now be installed. When finished, the TCD will 
 *     reboot.
 */

/*  Changelog
 *          
 *  2026/09/18 (A10001986) [3.27]
 *    **********************************************************************************
 *    ** If updating from below 3.20, please see boxed note at version 3.21 below     **
 *    **********************************************************************************
 *    - New sound-pack (TW09/CS09)
 *    - Add option to play a default sound-on-the-hour (clock tower bell plus spoken
 *      time; requires fully installed sound-pack; only played if not user-overridden by 
 *      "hour[-xx].mp3" sounds on SD card)
 *    - MQTT: Split "Publish time travel and alarm events" option into two options, 
 *      "Time Travel" and "Alarm".can now go different MQTT/BTTFN routes.
 *    - Keypad command "9" sends "refill" command to Dash Gauges ("009" is also still
 *      supported).
 *    - Add support for forwarding "refill" command from FC's and SID's IR remote control
 *      to the Dash Gauges. (FC 1.107+, SID 1.76+)
 *    - Fix minor issues with ID3v1 and ID3v2.4-UTF8 tags.
 *    - Speed up booting with music folders containing many files
 *    - Music Player: The "TCD_DONE.TXT" file is now obsolete. The firmware instead uses
 *      a cache file in the top-most folder of the SD card ("musicXc") which needs to be
 *      deleted when files are added to the respective folder.
 *    - Protect the TCD from uploading a wrong firmware by accident. The filename of
 *      the firmware binary now must contain the word "circuits". The check is case-
 *      insensitive.
 *    - Add option to configure speedo as briefly shown in part 3 with the left-most
 *      digit covered by gaffer tape. Only supported on upcoming CircuitSetup speedo v2 
 *      (featuring a complete third digit).
 *    - Bonjour/mDNS: Send good-bye packet on controlled reboots
 *    - Minor tweaks and fixes
 *  2026/08/19 (A10001986) [3.26]
 *    **********************************************************************************
 *    ** If updating from below 3.20, please see boxed note at version 3.21 below     **
 *    **********************************************************************************
 *    - New sound-pack (TW08/CS08)
 *    - WC/RC-hybrid display mode: Show both temperature and humidity on same display
 *    - Door sound playback: Fix regression introduced in 3.25 
 *    - More robust error handling in case of malformed config files
 *    - SD: More compatibility fixes
 *    - Fix typos in Config Portal: TT_OUT is switched by 900/901 (not 990/991).
 *    - "Time Cycling": Correct some times of tt
 *    - Internal BTTFN enhancements
 *    - Code optimizations
 *  2026/07/16 (A10001986) [3.25]
 *    **********************************************************************************
 *    ** If updating from below 3.20, please see boxed note at version 3.21 below     **
 *    **********************************************************************************
 *    - Bugfix: Year in BTTFN-broadcast time stamp was truncated
 *    - Bugfix: Fix SD initialization in ESP32-Arduino to conform to specs.
 *      Sandisk Ultra 32GB cards (and possibly others that previously were not usable) 
 *      are now recognized.
 *    - Internal BTTFN changes
 *  2026/06/25 (A10001986) [3.24]
 *    **********************************************************************************
 *    ** If updating from below 3.20, please see boxed note at version 3.21 below     **
 *    **********************************************************************************
 *    - MQTT: Add "VOLUME_UP"/"VOLUME_DOWN"/"VOLUME_SET_xxx" commands
 *    - MQTT: Add publishing Music Player status to bttf/tcd/mpstatus
 *    - Music Player: Use new sorting algorithm as the old one caused a crash on a 
 *      large number of already sorted files (due to excessive recursion).
 *  2026/05/21 (A10001986) [3.23]
 *    **********************************************************************************
 *    ** If updating from below 3.20, please see boxed note at version 3.21 below     **
 *    **********************************************************************************
 *    - New Sound-Pack (TW07/CS07). Marty will tell you the displayed time whenever
 *      pressing ENTER without entering a command.
 *    - Add keypad commands 30-33 to set relative beep volume level
 *    - Remap keypad command 33 (show weekday) to 39
 *    - Remap keypad commands 000/001/002/003 to 20/21/22/23 to match FC's flux mode
 *      (000-003 still supported)
 *    - Refactor logic when toggling world clock & room condition hybrid mode
 *    - Display TCD-AP BSSID on WiFi Settings page in Config Portal
 *    - Internal BTTFN enhancements
 *  2026/04/19 (A10001986) [3.22]
 *    **********************************************************************************
 *    ** If updating from below 3.20, please see boxed note at version 3.21 below     **
 *    **********************************************************************************
 *    - "Persistent" time travels no longer overwrite stored user-programmed dates
 *      for red and yellow displays. User times can be brought back by 998 at any time.
 *    - Keypad menu: Navigation is now only through 2 (up/+), 5 (select), 8 (down/-),
 *      9 (cancel). Pressing Enter is now equal to "select", no longer used to cycle
 *      through items. Holding the Enter key is no longer part of any menu navigation,
 *      apart from initially entering the keypad menu. When digits are expected to be
 *      entered, ENTER must now be pressed to proceed. Entering the expected number of 
 *      digits no longer automatically proceeds to the next field.
 *    - Alarm: Add "user days" option to select any combination of weekdays.
 *      Pressing 1-7 toggles days, ENTER proceeds, 9 cancels.
 *    - World Clock: Add option to keep location name permanently; only honored if
 *      location name is short enough to fit next to time (9 chars; 8 chars for A-Car)
 *    - Extend MQTT message display feature to all three displays, with separate
 *      topics for each display
 *    - New nightmode schedule preset "Night Owl" (aka "Mancave"). Operating times:
 *      Sun-Thu 8pm-1am, Fri/Sat 8pm-4am.
 *    - Forward Remote's new "REFILL" command from the Remote to the Dash Gauges 
 *      (Remote 1.22)
 *    - Refactor alarm/reminder/timer/SotH logic regarding priorities, concurrency,
 *      locking sequences, etc.
 *    - Fix nightmode weekday selection
 *    - Code optimizations and fixes
 *  2026/03/27 (A10001986) [3.21]
 *    **********************************************************************************
 *    ** If updating from below 3.20, please install 3.20 or 3.20.1 first to have     **
 *    ** your settings converted. If 3.20(.1) is skipped, many of your settings       **
 *    ** will be restored to default values. It suffices to install 3.20 or 3.20.1    **
 *    ** and boot once; you can then immediately update to a later version.           **
 *    ** https://github.com/realA10001986/Time-Circuits-Display/releases/tag/V3.20.1  **
 *    **********************************************************************************
 *    - New sound-pack (TW06/CS06)
 *    - New "extended" alarm function: Pressing ENTER optionally snoozes, holding 
 *      ENTER stop the alarm. User-provided sound can be looped. Old legacy mode
 *      still supported.
 *    - 117 toggles new "minimal mode": Present time shows weekday instead of year
 *      when displaying actual present time, red and yellow displays are off.
 *    - 110 restores display mode to default (disables RC, WC, Geo, mini modes)
 *    - 91mmddyyyyhhMM/92mmddyyyyhhMM are short-cuts to enter and save user-defined
 *      dates for the Destination Time/Last Time Departed displays, just like using
 *      the keypad menu. Time-cycling is paused for 30 mins.
 *    - Programming the Destination Time/Last Time Departed displays through the 
 *      keypad menu no longer disables time cycling, it only pauses it for 30 mins.
 *    - MQTT: Add 10 user defined topics and messages for publishing through keypad 
 *      commands 600-609.
 *    - WiFi: Allow defining a BSSID (AP MAC address) to connect to a specific AP
 *      if multiple APs with identical SSID are available.
 *    - A-Car version can now swap red and yellow displays to emulate B-Car as seen
 *      in part 3.
 *    - New Easter Egg
 *    - Music player: Fix off-by-one bug in ID3 decoding
 *    - MQTT: Disable if server can't be resolved
 *    - WiFi: Do not power down AP long as a client is connected
 *    - Brush up Config Portal a bit
 *    - Code optimizations and fixes
 *  2026/03/04 (A10001986) [3.20.1]
 *    - Fix saving display times
 *  2026/02/16 (A10001986) [3.20]
 *    - New file format for secondary and IP settings. This version of the firmware 
 *      converts old to new.
 *    - Add geolocation: Display GPS coordinates in Destination and Last Time Dep
 *      displays. 114(DD notation)/115(DMS)/116(DMD) to enable/disable this mode.
 *    - Display mode (Room condition, World Clock, Geolocation) is now persistent
 *      (SD card required). Current mode is saved 10 seconds after activation (or 
 *      upon fake-power-down or a controlled reboot such as when changing settings 
 *      in Config Portal)
 *    - "Shuffle" setting changes are now saved (SD card required), "Shuffle" option
 *      removed from Config Portal.
 *    - Add option to *not* use GPS time; no one knows what happens after 2034/2038
 *      when the GPS week counter rolls over, so although the firmware tries to
 *      correct wrong times, given I cannot test this in any way, it might fail
 *      and sync to wrong date/time.
 *    - Display MAC address (STA) on WiFi Configuration Page
 *    - Fiddle with timing for smoother Remote speed updates
 *    - World Clock mode: Display location name with time if both fit
 *    - Config files are now only written if actually changed which prolongs
 *      Flash life-span.
 *    - Add NO_MONTH_ANIM compile-time option to skip the date-entry animation.
 *      Might be desirable when using A-car displays: Given the "month" is just
 *      an ordinary 2-digit number (and no back-lit gel) the real thing probably
 *      switched on the entire line at once.
 *    - Code optimizations and fixes
 *  2026/01/11 (A10001986) [3.11]
 *    - New sound pack (TW05/CS05)
 *    - Keypad menu: Add navigation using keypad keys 2 (up), 5 (select), 8 (down), 
 *      9 (cancel). Old "ENTER" method still supported.
 *    - Add MQTT commands "PLAY_DOOR_OPEN", "PLAY_DOOR_CLOSE" (with optional
 *      appendices "_L"/"_R" for playing it on one stereo channel only).
 *    - Add way for Dash Gauges to play door open/close sounds through TCD
 *      (Gauges >= 1.29)
 *    - Fix float settings (temp offset, accel figure factor; broken since 3.6)
 *    - Add new notification, which eliminates the need for clients to poll for
 *      data and helps to reduce network traffic.
 *      (For full effect, other props need updates, too: FC >= 1.91, SID >= 1.63, 
 *      Gauges >= 1.30, VSR >= 1.25, Remote >= 1.16)
 *    - Eliminate DNS lookups in loop() (which were a possible reason for sound-
 *      stutter sometimes)
 *    - NTP/GPS time sync logic enhancements
 *    - Various code optimizations (audio, GPS, network, etc)
 *  2025/11/29 (A10001986) [3.10]
 *    - Play user-provided "ttcancel.mp3" if TT is cancelled through brake on
 *      Remote
 *    - Make TCD<->Remote communication more robust
 *    * Requires Remote 1.14 for proper operation in combination with Remote
 *  2025/11/28 (A10001986)
 *    - P0: Fix speed-jumps on Remote when hitting brake (Remote and TCD firmware)
 *  2025/11/27 (A10001986)
 *    - Speedo-less operation with Remote: Set TCD speed to 0 as long as brake 
 *      is on. This prevents a time travel at 88 on the Remote with brake on.
 *  2025/11/25 (A10001986)
 *    - Modify speedo-less time travel sequence if bttf clients are present or
 *      mqtt "publish" (regardless of enhanced TIMETRAVEL message) is enabled,
 *      and the tt is triggered by '0', BTTFN or MQTT (NOT: button): 
 *      Now the sequence takes 5 seconds (as opposed to 1.4 seconds in prior 
 *      versions) to give the props enough time for a proper acceleration sequence, 
 *      and in case there is a ttaccel sound, it is played. 
 *      As before, if the time travel is triggered by external button, it starts
 *      immediately and there is no acceleration-time whatsoever.
 *  2025/11/24 (A10001986)
 *    - If a Futaba Remote control is present, it requires proper acceleration/
 *      deceleration and, in essence, acts like a speedo display; therefore, do
 *      TCD-triggered TT sequence as if speedo is present even if there is none.
 *      If the Remote is fake-off, only do that if it wants to display speed 
 *      while off.
 *  2025/11/23 (A10001986)
 *    - Add "Wireless (BTTFN)" speedo type. Allows using a simple BTTFN-listener 
 *      as speedo.
 *    - Initialize everything speedo-related independent of speedo presence; if
 *      Remote is connected (later), it will require proper accel/deceleration 
 *      sequence. See also changes of 11/24.
 *  2025/11/22 (A10001986)
 *    - TCD-controlled TT while Remote is speedMaster: No TT while brake is on.
 *      If brake is hit while accelerating, TT(P0) is cancelled.
 *  2025/11/21 (A10001986) [3.9]
 *    - WM: Minor HTML tweaks; make page width dynamic for better display on
 *      handheld devices
 *  2025/11/19 (A10001986)
 *    - Add support for MQTT v5.0 (tested with mosquitto only). Has no
 *      advantages over 3.1.1 (but more overhead), only there to use brokers
 *      that lack support for 3.1.1.
 *    - Add connection state info on HA/MQTT Settings page
 *  2025/11/17 (A10001986)
 *    - Clear keypad input buffer when/after holding a key
 *  2025/11/16 (A10001986)
 *    - Delete Remote/KPRemote upon forbidding remote (KP) control 
 *    - WM: Require HTTP_POST for params save pages. Also, check if request 
 *      has parameter, do not overwrite current value with null (protects from 
 *      overwriting settings by errorneous page reloads)
 *  2025/11/15 (A10001986)
 *    - Offer three purposes for TT-OUT (IO14): Time travel (as before), alarm,
 *      and control through keypad command; selectable in Config Portal.
 *  2025/11/13 (A10001986)
 *    - Remove various compilation conditionals (FAKE_POWER_ON, TC_HAVELINEOUT,
 *      EXTERNAL_TIMETRAVEL_IN, EXTERNAL_TIMETRAVEL_OUT, HAVE_STALE_PRESENT,
 *      TC_HAVESPEEDO, TC_BTTFN_MC)
 *  2025/11/11 (A10001986)
 *    - Add "stalled P0" feature for speed notification (used by Remote)
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
void loop()
{
    keypad_loop();
    audio_loop();
    scanKeypad();
    ntp_loop();
    audio_loop();
    bttfn_loop(BNLP_SK_MC|BNLP_SK_NOTDATA|BNLP_SK_EXPIRE);
    audio_loop();
    main_loop();
    audio_loop();
    wifi_loop();
    audio_loop();
    bttfn_loop();
    bttfn_loop_ex();
    audio_loop();
}
#endif

#if defined(TC_DBG_TIME) || defined(TC_DBG_NET) || defined(TC_DBG_GPS) || defined(TC_DBG_GEN)
#warning "Debug output is enabled. Binary not suitable for release."
#endif

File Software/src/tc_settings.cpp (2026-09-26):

/*
 * -------------------------------------------------------------------
 * CircuitSetup.us Time Circuits Display
 * (C) 2021-2022 John deGlavina https://circuitsetup.us
 * (C) 2022-2026 Thomas Winischhofer (A10001986)
 * https://github.com/realA10001986/Time-Circuits-Display
 * https://tcd.out-a-ti.me
 *
 * Settings & file handling
 *
 * -------------------------------------------------------------------
 * License: Modified MIT NON-AI
 * 
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
 * Links inside the Software pointing to the original source must not 
 * be changed or removed.
 *
 * In addition, the following restrictions apply:
 * 
 * 1. The Software and any modifications made to it may not be used 
 * for the purpose of training or improving machine learning algorithms, 
 * including but not limited to artificial intelligence, natural 
 * language processing, or data mining. This condition applies to any 
 * derivatives, modifications, or updates based on the Software code. 
 * Any usage of the Software in an AI-training dataset is considered a 
 * breach of this License.
 *
 * 2. The Software may not be included in any dataset used for 
 * training or improving machine learning algorithms, including but 
 * not limited to artificial intelligence, natural language processing, 
 * or data mining.
 *
 * 3. Any person or organization found to be in violation of these 
 * restrictions will be subject to legal action and may be held liable 
 * for any damages resulting from such use.
 *
 * THE SOFTWARE IS PROVIDED "AS IS", WITHOUT WARRANTY OF ANY KIND, 
 * EXPRESS OR IMPLIED, INCLUDING BUT NOT LIMITED TO THE WARRANTIES OF 
 * MERCHANTABILITY, FITNESS FOR A PARTICULAR PURPOSE AND NONINFRINGEMENT. 
 * IN NO EVENT SHALL THE AUTHORS OR COPYRIGHT HOLDERS BE LIABLE FOR ANY 
 * CLAIM, DAMAGES OR OTHER LIABILITY, WHETHER IN AN ACTION OF CONTRACT, 
 * TORT OR OTHERWISE, ARISING FROM, OUT OF OR IN CONNECTION WITH THE 
 * SOFTWARE OR THE USE OR OTHER DEALINGS IN THE SOFTWARE.
 */

#include "tc_global.h"

#define ARDUINOJSON_USE_LONG_LONG 0
#define ARDUINOJSON_USE_DOUBLE 0
#define ARDUINOJSON_ENABLE_ARDUINO_STRING 0
#define ARDUINOJSON_ENABLE_ARDUINO_STREAM 0
#define ARDUINOJSON_ENABLE_ARDUINO_PRINT 0
#define ARDUINOJSON_DECODE_UNICODE 0
#define ARDUINOJSON_ENABLE_STD_STREAM 0
#define ARDUINOJSON_ENABLE_STD_STRING 0
#define ARDUINOJSON_ENABLE_NAN 0
#define ARDUINOJSON_ENABLE_INFINITY 0
#include <ArduinoJson.h>  // https://github.com/bblanchon/ArduinoJson
#include "src/SD/SD.h"
#include <SPI.h>
#include <FS.h>
#define MYNVS LittleFS
#include <LittleFS.h>
#include <Update.h>

#include "tc_settings.h"
#include "tc_audio.h"
#include "tc_main.h"
#include "tc_wifi.h"

// SPI speed for SD. We used 16000000 in the past,
// but since we have short traces and likely no
// extender, we go a bit higher now.
// 25000000 is max for SD, 20000000 is max for MMC
// SD-code automatically limits according to card type
#define SD_SPI_FREQ 20000000

// Settings upgrade, stage 2: Assume new settings
//  are present, but still delete obsolete files.
#define SETTINGS_TRANSITION_2

// Size of main config JSON
// Needs to be adapted when config grows
#define JSON_SIZE 5000
#if ARDUINOJSON_VERSION_MAJOR >= 7
#define DECLARE_S_JSON(x,n) JsonDocument n;
#define DECLARE_D_JSON(x,n) JsonDocument n;
#else
#define DECLARE_S_JSON(x,n) StaticJsonDocument<x> n;
#define DECLARE_D_JSON(x,n) DynamicJsonDocument n(x);
#endif

#define NUM_AUDIOFILES 26
#define AC_FMTV 2
#define AC_OHSZ (14 + ((NUM_AUDIOFILES+1)*(32+4)))
#ifdef CS_EDITION
#define SND_REQ_VERSION "CS09"
#define AC_TS 17687967
#define SND_NON_ALIEN "TW"
#else
#define SND_REQ_VERSION "TW09"
#define AC_TS 17682952
#define SND_NON_ALIEN "CS"
#endif

// Secondary settings
// Do not change or insert new values, this
// struct is saved as such. Append new stuff.
static struct [[gnu::packed]] {
    uint8_t brightness[3]   = { DEF_BRIGHT_DEST, DEF_BRIGHT_PRES, DEF_BRIGHT_DEPA };
    uint8_t autoInterval    = DEF_AUTOROTTIMES;
    uint8_t beepMode        = DEF_BEEP;
    uint8_t curVolume       = DEFAULT_VOLUME;
    uint8_t alarmOnOff      = DEF_ALARM_ONOFF;
    uint8_t alarmHour       = DEF_ALARM_HOUR;
    uint8_t alarmMinute     = DEF_ALARM_MINUTE;
    uint8_t alarmWeekday    = DEF_ALARM_WD;
    uint8_t remMonth        = 0;
    uint8_t remDay          = 0;
    uint8_t remHour         = 0;
    uint8_t remMin          = 0;
    uint8_t carMode         = 0;
    uint8_t useLineOut      = 0;
    uint8_t remoteAllowed   = 0;
    uint8_t remoteKPAllowed = 0;
    int8_t  scorr           = 0;
    int8_t  tcorr           = 0;
    uint8_t exhOnOff        = 0;
    uint8_t showUpdAvail    = 1;
    dateStruct exhDates[2]; // initialized to default in main_boot()
    uint8_t updateV         = 0;
    uint8_t updateR         = 0;
    uint8_t beepLvlIdx      = 2;
} secSettings;
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

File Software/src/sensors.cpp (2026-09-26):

/*
 * -------------------------------------------------------------------
 * CircuitSetup.us Time Circuits Display
 * (C) 2022-2026 Thomas Winischhofer (A10001986)
 * https://github.com/realA10001986/Time-Circuits-Display
 * https://tcd.out-a-ti.me
 *
 * Sensor Class: Temperature/humidty and Light Sensor handling
 *
 * This is designed for 
 * - MCP9808, TMP117, BMx280, SHT4x-Ax, SI7012, AHT20/AM2315C, HTU31D, 
 *   MS8607, HDC302X temperature/humidity sensors,
 * - BH1750, TSL2561, TSL2591, LTR303/329 and VEML7700/VEML6030 light 
 *   sensors.
 *                             
 * The i2c slave addresses need to be:
 * MCP9808:       0x18                [temperature only]
 * TMP117:        0x49 [non-default]  [temperature only]
 * BMx280:        0x77                ['P' t only, 'E' t+h]
 * SHT4x-Axxx:    0x44                [temperature, humidity]
 * SI7021:        0x40                [temperature, humidity]
 * AHT20/AM2315C: 0x38                [temperature, humidity]
 * HTU31D:        0x41 [non-default]  [temperature, humidity]
 * MS8607:        0x76+0x40           [temperature, humidity]
 * HDC302x:       0x45 [non-default]  [temperature, humidity]
 * 
 * TSL2561:       0x29
 * TSL2591:       0x29
 * LTR303/329:    0x29
 * BH1750:        0x23
 * VEML6030:      0x10, 0x48 [non-default]
 * VEML7700:      0x10
 * 
 * If a MT(K)333x-based GPS receiver or the CircuitSetup speedo is 
 * connected, 
 * - VEML7700 cannot be used;
 * - VEML6030 needs to be set to address 0x48.
 * -------------------------------------------------------------------
 * License: Modified MIT NON-AI
 * 
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
 * Links inside the Software pointing to the original source must not 
 * be changed or removed.
 *
 * In addition, the following restrictions apply:
 * 
 * 1. The Software and any modifications made to it may not be used 
 * for the purpose of training or improving machine learning algorithms, 
 * including but not limited to artificial intelligence, natural 
 * language processing, or data mining. This condition applies to any 
 * derivatives, modifications, or updates based on the Software code. 
 * Any usage of the Software in an AI-training dataset is considered a 
 * breach of this License.
 *
 * 2. The Software may not be included in any dataset used for 
 * training or improving machine learning algorithms, including but 
 * not limited to artificial intelligence, natural language processing, 
 * or data mining.
 *
 * 3. Any person or organization found to be in violation of these 
 * restrictions will be subject to legal action and may be held liable 
 * for any damages resulting from such use.
 *
 * THE SOFTWARE IS PROVIDED "AS IS", WITHOUT WARRANTY OF ANY KIND, 
 * EXPRESS OR IMPLIED, INCLUDING BUT NOT LIMITED TO THE WARRANTIES OF 
 * MERCHANTABILITY, FITNESS FOR A PARTICULAR PURPOSE AND NONINFRINGEMENT. 
 * IN NO EVENT SHALL THE AUTHORS OR COPYRIGHT HOLDERS BE LIABLE FOR ANY 
 * CLAIM, DAMAGES OR OTHER LIABILITY, WHETHER IN AN ACTION OF CONTRACT, 
 * TORT OR OTHERWISE, ARISING FROM, OUT OF OR IN CONNECTION WITH THE 
 * SOFTWARE OR THE USE OR OTHER DEALINGS IN THE SOFTWARE.
 */

#include "tc_global.h"

#if defined(HAVE_TEMP) || defined(HAVE_LIGHT)

#include <Arduino.h>
#include <Wire.h>
#include "sensors.h"

static void defaultDelay(unsigned long mydelay)
{
    delay(mydelay);
}

static uint8_t crc8(uint8_t initVal, uint8_t poly, uint8_t len, uint8_t *buf)
{
    uint8_t crc = initVal;
 
    while(len--) {
        crc ^= *buf++;
 
        for(int i = 0; i < 8; i++) {
            crc = (crc & 0x80) ? (crc << 1) ^ poly : (crc << 1);
        }
    }
 
    return crc;
}

void tcSensor::prepareRead(uint16_t regno)
{
    Wire.beginTransmission(_address);
    Wire.write((uint8_t)(regno));
    Wire.endTransmission(false);
}

uint16_t tcSensor::read16(uint16_t regno, bool LSBfirst)
{
    uint16_t value = 0;
    size_t i2clen = 0;

    if(regno <= 0xff) {
        prepareRead(regno);
    }

    i2clen = Wire.requestFrom(_address, (uint8_t)2);

    if(i2clen > 0) {
        value = (Wire.read() << 8);
        value |= Wire.read();
    }
    
    if(LSBfirst) {
        value = (value >> 8) | (value << 8);
    }

    return value;
}

void tcSensor::read16x2(uint16_t regno, uint16_t& t1, uint16_t& t2)
{
    size_t i2clen = 0;

    prepareRead(regno);

    i2clen = Wire.requestFrom(_address, (uint8_t)4);

    if(i2clen > 0) {
        t1 = Wire.read();
        t1 |= (Wire.read() << 8);
        t2 = Wire.read();
        t2 |= (Wire.read() << 8);
    } else {
        t1 = t2 = 0;
    }
}

uint8_t tcSensor::read8(uint16_t regno)
{
    uint16_t value = 0;

    prepareRead(regno);

    Wire.requestFrom(_address, (uint8_t)1);

    value = Wire.read();

    return value;
}

void tcSensor::write16(uint16_t regno, uint16_t value, bool LSBfirst)
{
    Wire.beginTransmission(_address);
    if(regno <= 0xff) {
        Wire.write((uint8_t)(regno));
    }
    if(LSBfirst) {
        value = (value >> 8) | (value << 8);
    } 
    Wire.write((uint8_t)(value >> 8));
    Wire.write((uint8_t)(value & 0xff));
    Wire.endTransmission();
}
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

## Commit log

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2021-04-02 replaced eeprom with preferences for esp32
    [tc_keypad.cpp, tc_time.cpp, timecircuits.ino]
2021-04-10 added stl files
    [button_lens_bracket.stl, display_faceplate.stl, enclosure_left.stl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]
2021-04-10 added gerbers and eagle files
    [time_circuit_controller_1.1.brd, time_circuit_controller_1.1.sch, time_circuits1.3.brd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]
2021-04-13 fixed time travel present time
    - fixed time travel present time year
    - added delay to turning display back on after time travel
    [tc_time.cpp, timecircuits.ino]
2021-04-13 fixed check for month & day
    also made it impossible to not enter a month via clockdisplay - previously if month was wrong display would read I I I
    [tc_keypad.cpp]
2021-04-13 fixed enclosure to not include faceplate
    [present_dest_enclosure.stl]
2021-04-17 moved wire hole back
    [keypad_body.stl, last_time_bottom.stl]
2021-04-29 menu with enter button
    - holding enter button now goes into menu
    - using enter to update fields still needs to be handled by the keypad and not just the enter button
    - still need to go to brightness, after min is set
    - need to add settings for beep sound on/off, and volume
2021-04-30 v1.2 of control board
    - Fixed footprint for enter button
    - added level shifter and ESP protection for I2C lines. This will prevent random glitches in the I2C.
    - Added footprint for PCF2129AT RTC in case DS3231 becomes unavailable or too expensive. Both should not be populated at the same time.
    - Changed volume to connect to GPIO32 on ESP32 instead of amp GAIN_SLOT
    - Updated schematic to include some notes
    [time_circuit_controller_1.2.brd, time_circuit_controller_1.2.sch]
2021-05-04 Increased mounting hole size
    [enclosure_left.stl, enclosure_one_piece.stl, enclosure_right.stl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]
2021-05-04 Update keypad_body.stl
    - made mounting holes larger
    - added slots for esp32 usb port and sdcard
    [keypad_body.stl]
2021-05-04 Update last_time_bottom.stl
    made mounting holes for keypad larger
    [last_time_bottom.stl]
2021-05-11 settings menu updates
    Some progress towards getting keypad input on settings menu. Not working correctly yet.
    [tc_keypad.cpp, timecircuits.ino]
2021-05-17 added speaker mount
    [last_time_bottom.stl]
2021-05-17 made pcb mounting holes larger
    [present_dest_enclosure.stl]
2021-05-18 moved speaker holes a bit & added support
    [last_time_bottom.stl]
2021-05-20 added keypad 3mf file
    [keypad_body.3mf]
2021-05-24 added 3mf files
    [keypad_bezel.3mf, keypad_body.3mf]
2021-05-26 oriented stl files & fixed some manifolds
    [button_lens_bracket.stl, enclosure_left.stl, enclosure_one_piece.stl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]
2021-06-06 temp fix for brightness
    [tc_time.cpp]
2021-06-15 Saving dates, "RE SET", & auto rotating preset dates
    Reverted from Preferences back to EEPROM since Preferences was not working properly.
    This fixes:
    - The "RE SET" that was being displayed on startup every time
    - Storing dates for Destination Time and Last Time Departed
    - Auto rotating through preset dates as displayed in the movie
    - Faster startup
    [tc_time.cpp, tc_wifi.cpp]
2021-06-20 additional settings for web interface
    still need to fix getting and saving settings
    [tc_time.cpp, tc_wifi.cpp]
2021-08-26 Fixed startup delay (really)
    - Fixed startup animate too
    [tc_time.cpp]
2021-09-19 Create enclosure_one_piece-v2.stl
    - Increased rear opening from about 9.75 to 10.25" (width of a Delorean upper center console)
    - depth increased a tiny bit - left side 3", right side 4"
    - Height increased from 4.5" to 5"
    - Angles on left and right side going front to back are now about even
    - Bends on sides moved forward a bit
    - Rounded the corner on the lower left side
    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
    [enclosure_one_piece-v2.stl]
2021-09-24 Updated keypad to more closely match TRW keypad
    - moved side buttons and keypad down slightly
    - moved the slope of the top and bottom down, so the top is more flat when compared to the bottom
    - flattened the clear lettering a bit
    - removed lip on the inside of the lens/button cutout
    [button_lens_bracket-v2.stl, keypad_bezel-v2.stl, keypad_body-v2.stl]
2021-09-25 made hole for enter button larger
    [button_lens_bracket-v2.stl]
2021-09-25 fixed orientation
    [enclosure_one_piece-v2.stl]
2021-09-28 added proper 3mf files
    [button_lens_bracket-v2.3mf, button_lens_bracket-v2.stl, display_faceplate.3mf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]
2021-10-13 made lens holes larger, body slimmer, and easier to snap into body
    [button_lens_bracket-v2.3mf, button_lens_bracket-v2.stl]
2021-10-15 Added Cura 3mf files for keypad
    [cura_keypad_bezel-v2.3mf, cura_keypad_body-v2.3mf]
2021-12-02 Create TCD_STICKERS_v2.pdf
    - Sized each sticker individually to be more accurate to the screen used TCD (they were all slightly different since they were hand cut)
    - Switched from Microgramma D Med Ext to Microgramma D Extended font, which is naturally more bold. The M's and A's match better too
    - Increased font size a bit to better match the original
    - Carefully tweaked the spacing between letters, especially after I's and A's, to match the original
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2022-03-16 Outer enclosure v3 & display enclosures v2
    Update to the enclosures to make them more true to the original C car TCD, which is now in the restored A car.
    - Made bends on left and right sides angled forward
    - Corrected top dimensions
    - Adjusted angles of sides to the top, which are a bit > 90 degrees
    - Added proper curves to right back side
    - Added rear screw dash mounting holes
    - Adjusted display mounting holes to match original (which are not evenly spaced)
    - Made display enclosures resemble LMB boxes more by rounding top left/right edges, and face bottom edge, and squaring bottom left/right edges, and top face edge.
    [dest_time_enclosure-v2.3mf, enclosure_one_piece-v3.3mf, last_time_enclosure-v2.3mf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]
2022-05-18 cleaned up outer enclosure, added 2 piece enclosure
    [enclosure_left-v3.3mf, enclosure_one_piece-v3.3mf, enclosure_right-v3.3mf]
2022-06-21 fixed warning with return
    [tc_time.cpp]
2022-06-21 remove old controller design files
    [time_circuit_controller_1.1.brd, time_circuit_controller_1.1.sch]
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2022-06-21 temp fix for Arduino 2 not compiling properly
    [tc_wifi.cpp]
2022-08-04 Many updates & bug fixes thanks to Thomas Winischhofer (A10001986)
    - Return from Time Travel (hold "9" for 2 seconds)
    - "present time" is a clock (not stale) after time travel
    - New Keypad menu for adjusting various settings
    - Now uses time zones, automatic DST, instead of offset
    - Fixed "month-off-by-one" bug, and others
    - More stable WiFi connections at startup
    - Added incorrect date sound
    [tc_audio.cpp, tc_global.h, tc_keypad.cpp]
2022-08-16 Many additions and fixes
    - Add NET-WRK keypad menu item to show IP address
    - Add alarm function
    - Add 24-hour mode for clocks
    - Add keypad shortcuts and visual indicator for alarm on/off
    - Added night mode; enabled by holding "4", disabled by holding "5"
    - Night mode now also reduces sound volume
    - Fix autoInterval array to match indices 0-5
    - Add "fake power on" facility
    - Import and patch Keypad_I2C to tackle "ghost keys"
    - Added SD-Card support for audio files; A-Car display enhanced
    - New sound files, all re-done
    - Added External Time-Travel trigger
    - New time logic; Independence from NTP; Alarm base configurable
    [tc_audio.cpp, tc_global.h, tc_keypad.cpp]
2022-08-16 Bug fixes, clean ups
    Fix fake power off if time-rot-interval is non-zero
    Major cleanup
    [tc_keypad.cpp, tc_time.cpp, tc_wifi.cpp]
2022-08-17 Some updates & bug fixes
    - Added some error checking around alarm config loading
    - Show "BATT" during booting if RTC battery is depleted and needs to be changed
    - Pause autoInterval-cycling when user entered a valid destination time
    and/or initiated a time travel
    - Fix missing return value in loadAlarm
    [tc_keypad.cpp, tc_settings.cpp, tc_settings.h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]
2022-08-18 Small bug fixes
    Get rid of compiler warnings
    Fix bug with saving settings in the web interface before connecting to WiFi
    [tc_audio.cpp, tc_global.h, tc_time.cpp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]
2022-08-19 Add mini features; fix some small bugs
    - Better volume control (remove noise from pot values)
    - Volume knob is now polled during play back, allowing changes while sound is playing
    - Destination time/date can now be entered in mmddyyyy, mmddyyyyhhmm or hhmm format.
    - Sound file "hour.mp3" is played hourly on the hour, if the file exists on the SD card.
    - Holding "3" or "6" plays sound files "key3.mp3"/"key6.mp3" if these files exist on the SD card
    [tc_audio.cpp, tc_global.h, tc_keypad.cpp]
2022-08-22 New long time travel sequence; bugfix for alarm; startup display
    [tc_audio.cpp, tc_global.h, tc_keypad.cpp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]
2022-08-22 More features, bugfixes
    - Audio: Fix pot resolution, less logging
    - WiFi status in AP mode added; proper day check
    - Remove TWPRIVATE
    [tc_audio.cpp, tc_global.h, tc_keypad.cpp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]
2022-08-26 LittleFS, Copy from SD card, order & correct dates
    [tc_audio.cpp, tc_global.h, tc_settings.cpp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]
2022-08-26 move old 3d files to their own directory
    [button_lens_bracket.stl, enclosure_left.stl, enclosure_one_piece-v2.3mf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]
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2022-09-07 Web config portal beautified, upgrade and volume too loud crash bug fixes, add speedo support
    - Fix TC settings corruption when changing WiFi settings
    - Format flash file system if mounting fails
    - Reduce WiFi transmit power in AP mode (to avoid power issues with volume pot if not at minimum)
    - Nightmode: Displays can be individually configured to be dimmed or switched off in night mode
    - Fix logic screw-up in autoTimes, changed intervals to 5, 10, 15, 30, 60.
    - More Config Portal beauty enhancements
    - Clockdisplay: Remove dependency on settings.h
    - Fix static ip parameter handling (make sure strings are 0-terminated)
    [- I2C-Speedo integration; still inactive]
    [speeddisplay.cpp, speeddisplay.h, tc_global.h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]
2022-10-12 v2.1
    - Added support for triggering time travel on external props like a flux capacitor, and SID (now IO14)
    - Added Speedo support, complete with time travel, GPS & temp sensor functionality - if connected, the speedo will go up to 88mph, then the time travel sequence will trigger on the TCD. If the speedo reaches 88 via GPS, it will trigger a time travel sequence.
    - Added option to re-format SD card
    - Added feature to disable WiFi to save power
    - Added CPU power save feature
    - Added sound when volume is set in the menu
    - Reworked keypad and enter key debouncing
    - Removed dependency on RTCLib, and added a native slimmed down version
    - Changing the brightness in the menu no longer saves immed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
    [gps.cpp, gps.h, rtc.cpp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]
2022-10-26 v2.2
    - Fix time travel with speedo: Added forgotten code after re-write.
    - Added support for MTK3333 based GPS receivers connected through i2c. These can act as a source of authoritative time (just like NTP), as well as for calculating current speed, to be displayed on a speedo display.
    - Implemented completely native time system, handling NTP/GPS, time zones and DST calculation all by itself. This allows using this firmware with correct clocking until the year 9999 (at which point it rolls over to 1), with NTP support until around 2150. Also, DST is now automatically switched in stand-alone mode (ie without NTP or GPS).
    - Defer starting the Config Portal so that async WiFi scans don't dis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
    [gps.cpp, gps.h, rtc.cpp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]
2022-11-10 V2.3 update
    - Added auto night-mode presets
    - Support for speedo GPS, and getting time/speed
    - Re-order Config Portal options
    - Add short-cut to set alarm by typing 11hhmm+ENTER (weekday selection must still be done through keypad menu)
    - Change default time zone to UTC;
    - Change default "time travel persistence" to off to avoid flash wear
    - Add weekday selection for alarm
    - Enhancements to DST logic
    - Add option to disable time travel sounds (in order to have other props play theirs. This is only useful in connection with compatible props, triggered by IO14.)
    - Allow time travel to (non-existing) year 0, so users can simulate the movie error (Dec 25, 0000).
    - Many code optimizations and bug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
    [gps.cpp, gps.h, input.cpp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]
2022-11-30 v2.4
    - Added Extended Sound on the Hour: User can now put "hour-xx.mp3" files for each hour on the SD card (hour-00.mp3, hour-01.mp3, ..., hour-23.mp3). If one of the files is missing, "hour.mp3" will be played (if it exists on the SD card)
    - Added support for a light sensor to automatically switch TCD to night mode
    - Soft-reset the clock by entering 64738 and ENTER
    - Minor optimizations for Wifi
    - Fixed bug with Destination Time not coming back on after a time travel event
    [gps.cpp, sensors.cpp, sensors.h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]
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2023-02-02 v2.6
    - Added music player (from SD card)
    - Added countdown timer. Type 44xxENTER, xx being the number of minutes (2 digits). Type 44ENTER to see the time remaining.
    - Added room condition mode (will display temp and humidity if sensor is hooked up
    - Added MAC address to display "Network" keypad menu
    - Added mDNS support to access the config portal via http://timecircuits.local
    - Added support for more light sensors
    - Updated config portal to account for new features
    - Added shortcut (11+Enter) to show alarm settings
    - Changed audio file installer so files are installed automatically if they are on the SD card and not already installed
    - See timecircuits.ino for full release log
    Co-Authored-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
    [gps.cpp, gps.h, input.cpp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]
2023-03-28 v2.7
    - Add beep sound. Enabled/disabled by 000+ENTER. Disabled by default. Requires new sound-pack.
    - Fixes for CircuitSetup's speedo display
    - External time travel button: When held for 3 seconds, a "return from time travel" is triggered. This brings a change in external time travel triggering: Up until now, a time travel was issued when the button was pressed for 200ms, regardless of when it was released. Now, the tt will be triggered upon release of the button, as long it is released in under 3000ms. If a delay is configured, it, too, will start running upon release.
    - Prepare for TCD CB 1.3 with switchable LEDs. LEDs are off when fake power is off, and in night mode.
    [speeddisplay.cpp, speeddisplay.h, tc_audio.cpp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]
2023-04-05 v2.7
    - NTP: Do not overwrite previous packet age in case of a bad(outdated) new packet
    - Fix beep: Off in nightmode and when unit is fake-powered off
    - Fix CB1.3 LED logic: On only if unit is NOT fake powered off, and NOT in night mode.
    - Add beep option to setup page
    - Add option to keep temperature display on (and dimmed) in night mode
    [tc_audio.cpp, tc_global.h, tc_keypad.cpp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]
2023-04-06 v2.7 beep and wifi logic fix
    - Audio: Re-do beep; remove all traces of (obsolete) MIXER; Short fx are now played without re-scanning the analog input during play-back. Reason: Pot tolerance led to "distortions" with very short sounds.
    - WiFi: Reconnect for NTP also if previously in AP-mode, if a WiFi network is configured to connect to.
    [tc_audio.cpp, tc_global.h, tc_keypad.cpp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]
2023-05-22 v2.8
    -Added MQTT feature - can display txt sent via MQTT, and trigger time travel events when sent TIMETRAVEL. Events are also published to the subscribed MQTT topic.
    -Added beep modes and keypad shortcuts
    -Added World Clock mode with city labels
    -Added yearly/monthly reminder feature
    -Many logic/bug fixes/code optimizations
    [timezones.csv]
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2023-10-02 v2.9
    - Add remote control facility through TCD keypad for Flux Capacitor, SID and Plutonium Gauges via BTTFN.
    3xxx = Flux Capacitor, 6xxx = SID, 9xxx = Plutonium Gauges
    - Add REFILL network command for Plutonium gauges; triggered by 009ENTER
    - Add compile time option to disable tt sequence display flicker (TT_NO_ANIM)
    - Add custom "stale present time" mode: 99mmddyyyyhhMM sets a stale present time
    - Add option to signal time travel on TT_OUT/IO13 without 5 seconds lead
    - Add "AP name appendix" setting; allows unique AP names when running multiple TCDs in AP mode in close range
    - Add AP password: Allows to configure a WPA2 password for the TCD's AP mode
    - Add "car mode": Reboots (and stays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
    [timezones.csv]
2023-10-03 Exhibition mode fix
    Exhibition mode: Honor "Make time travels persistent" option properly
    [tc_global.h, tc_settings.cpp, tc_time.cpp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]
2023-10-23 Small fixes to v2.9
    - Don't use speedo if not detected
    - Auto-expire beep-timer when entering night mode
    - Whenever the beep timer is(would be) restarted, the wakeup is sent
    - Colons on in night mode
    - Fix P1 length sent to BTTFN clients
    [gps.cpp, gps.h, input.cpp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]
2023-11-08 v2.9.1
    - Fix boot loop when SP_ALWAYS_ON is enabled
    - Abort audio file installer on first error
    - Settings: (De)serialize JSON from/to buffer instead of file
    - Customize ArduinoJSON compile-time options to reduce bin size
    - Add support for a rotary encoder to select "speed" to be displayed on the speedo
    - Unmount filesystems before reboot
    - WiFiManager: Disable pre-scanning of WiFi networks when starting the CP
    [input.cpp, input.h, sensors.cpp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]
2023-11-12 update enclosure files
    [dest_time_enclosure-v2.5.3mf, enclosure_one_piece-v4.3mf, last_time_enclosure-v2.5.3mf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]
2023-11-12 move old enclosure files
    [dest_time_enclosure-v2.3mf, enclosure_left-v3.3mf, enclosure_one_piece-v3.3mf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]
2024-08-16 added v3 keypad
    [button_lens_bracket-v2.stl, cura_keypad_bezel-v2.3mf, cura_keypad_body-v2.3mf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]
2024-10-25 v3.1.1
    - Added support for upcoming Futaba remote control, including playing a sound when remote is turned on/off, syncing speedo speed with remote, STOP remote switch functionality (speedo displays 0 until stop switch/brake is turned off), and accelerating to 88mph to trigger time travel
    - Revisit UTF8 filtering for MQTT messages and ID3 data
    - Properly truncate UTF8 strings (MQTT user/topics) if beyond buffer size
    - Fix for line-out switching
    - Skip white led blink if fake power switch is on pos during boot
    - Add support for HDC302X temperature/humidity sensor
    - Key3, key6 are now played over line-out (if available and enabled)
    - Speedo/acceleration: Implement option to use either r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
    [gps.cpp, gps.h, input.cpp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]
2024-12-17 v3.2
    - Use multicast for BTTFN - sync other connected props faster during time travel sequences - all prop firmware must be updated to use this feature: Flux >= 1.60, SID >= 1.40, Dash Gauges >= 1.10, VSR >= 1.10, Remote >= 0.90
    - Show "00" on speedo when there is no fix on GPS
    [speeddisplay.cpp, tc_audio.cpp, tc_global.h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]
2025-03-07 v3.2.003
    - BTTFN: Add support for requesting currently displayed present, destination, departed times
    - BTTFN: Add support for remote controlling TCD keypad. Supported by FC 1.70 and SID 1.50, through their IR remote control.
    - Set epochs to 2025
    - Refine change of 2024/11/07. If the fix is lost, the speedo displays "--" for 60 seconds and then switches to "00". If the last GPS speed registered (before losing the fix) was < 4, it goes to "00" directly. It's nicer to see "--" in a tunnel than "00", and the exhibition situation (stationary car, indoors) is still covered.
    [gps.cpp, gps.h, input.cpp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]
2025-03-24 correct keypad in global.h
    [tc_global.h]
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2025-04-30 Fix outer enclosure & include 2 piece version
    [enclosure_one_piece-v4.1.3mf, x1_enclosure_2_piece-v4.1.3mf]
2025-04-30 Create circuitsetup_time_circuits_display.3mf
    compatible with Bambu Labs printers
    [circuitsetup_time_circuits_display.3mf]
2025-04-30 Update circuitsetup_time_circuits_display.3mf
    works with Bambu Studio v2
    [circuitsetup_time_circuits_display.3mf]
2025-08-15 Add v3 enclosure files and archive old versions
    Moved previous enclosure .3mf files to an Old_Versions directory for archival. Added new v3 enclosure files for destination, last departed, and present time.
    [dest_time_enclosure-v2.5.3mf, destination_time_v3.3mf, enclosure_one_piece-v4.3mf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]
2025-10-08 v3.5
    - Add emergency firmware update via SD (for dev purposes)
    - WM fixes (Upload, etc)
    - WM: Skip setting static IP params in Save
    - Add "No SD present" banner in Config Portal if no SD present
    - CP: Show msg instead of upload file input if no sd card is present
    - Let DNS server in AP mode only resolve our domain (hostname)
    - Allow 6 clients in AP mode instead of 4. So all props can connect to the TCD in AP mode, plus one admin computer/hand held. HOWEVER: Under normal use, do NOT connect a computer or phone to the TCD in AP mode unless for configuration changes. That computer might think it is connected to the internet, resulting in lots of network traffic, leading to packet loss, slowdown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
    [WiFiManager.cpp, WiFiManager.h, gps.cpp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]
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2025-12-05 v3.10
    - Play user-provided "ttcancel.mp3" if TT is cancelled through brake on Remote
    - Make TCD<->Remote communication more robust
    - P0: Fix speed-jumps on Remote when hitting brake (Remote and TCD firmware)
    - Speedo-less operation with Remote: Set TCD speed to 0 as long as brake is on. This prevents a time travel at 88 on the Remote with brake on.
    - Modify speedo-less time travel sequence if bttf clients are present or mqtt "publish" (regardless of enhanced TIMETRAVEL message) is enabled, and the tt is triggered by '0', BTTFN or MQTT (NOT: button):
    Now the sequence takes 5 seconds (as opposed to 1.4 seconds in prior versions) to give the props enough time for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
    [WiFiManager.cpp, WiFiManager.h, gps.cpp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]
2026-01-29 Refactor GPS, input, and sensor handling; update assets
    - New sound pack (TW05/CS05)
    - Keypad menu: Add navigation using keypad keys 2 (up), 5 (select), 8 (down), 9 (cancel). Old "ENTER" method still supported.
    - Add MQTT commands "PLAY_DOOR_OPEN", "PLAY_DOOR_CLOSE" (with optional appendices "_L"/"_R" for playing it on one stereo channel only).
    - Add way for Dash Gauges to play door open/close sounds through TCD (Gauges >= 1.29)
    - Fix float settings (temp offset, accel figure factor; broken since 3.6)
    - Add new notification, which eliminates the need for clients to poll for data and helps to reduce network traffic.(For full effect, other props need updates, too: FC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
2026-01-30 Move images to img/ and update AddOns.md
    Relocate image assets from DIY/img to a top-level img/ directory and add several new images. Update AddOns.md to use the new image paths, reorder and consolidate the Speedometer and GPS sections, clarify I2C wiring (recommend shielded twisted pair, shield->GND, and reduce SDA/SCL crosstalk), add guidance for relay-connected props with a relay module image, fix the splitter production link to the GitHub tree, and make minor wording/diagram label tweaks (decelleration -> deceleration). Files added: multiple img/*.jpg and img/*.png assets referenced by the updated document.
2026-03-16 v3.20
    - New file format for secondary and IP settings. This version of the firmware converts old to new.
    - Add geolocation: Display GPS coordinates in Destination and Last Time Dep displays. 114(DD notation)/115(DMS)/116(DMD) to enable/disable this mode.
    - Display mode (Room condition, World Clock, Geolocation) is now persistent (SD card required). Current mode is saved 10 seconds after activation (or upon fake-power-down or a controlled reboot such as when changing settings in Config Portal)
    - "Shuffle" setting changes are now saved (SD card required), "Shuffle" option removed from Config Portal.
    - Add option to *not* use GPS time; no one knows what happens after 2034/2038 when the GPS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
    [gps.cpp, gps.h, input.cpp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]
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

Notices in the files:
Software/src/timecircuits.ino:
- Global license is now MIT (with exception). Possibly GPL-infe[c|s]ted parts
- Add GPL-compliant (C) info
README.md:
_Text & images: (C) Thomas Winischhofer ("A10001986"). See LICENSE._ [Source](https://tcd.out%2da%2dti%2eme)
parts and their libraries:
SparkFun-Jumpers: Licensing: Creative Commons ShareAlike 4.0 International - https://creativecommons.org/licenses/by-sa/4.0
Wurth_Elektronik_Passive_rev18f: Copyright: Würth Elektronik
